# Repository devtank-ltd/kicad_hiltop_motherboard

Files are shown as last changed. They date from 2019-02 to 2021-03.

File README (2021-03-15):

Copyright Devtank Ltd 2021.

This documentation describes Open Hardware and is Licensed under CERN-OHL-W v2.

You may redistribute and modify this documentation under the terms of the CERN-OHL-W v2 (https://cern.ch/cern-ohl). This documentation is distributed WITHOUT ANY EXPRESS OR IMPLIED WARRANTY, INCLUDING OF MERCHANTABILITY, SATISFACTORY QUALITY AND FITNESS FOR A PARTICULAR PURPOSE. Please see the CERN-OHL-W v2 for applicable conditions

Source location: git@github.com:devtank-ltd/hiltop_motherboard.git 

As per CERN-OHL-W v2 section 4.1, should You produce hardware based on these sources, You must maintain the   Source Location visible on the external case of the HILTOP or other product you make using this documentation.

This folder contains HILTOP Motherboard hardware schematics, PCB layout and BOM files. 

You will need Kicad to open hardware design files.

HILTOP Motherboards and other test and measurement products can be purchased directly from Devtank Ltd.

Please contact:
Tim Telford
CTO - Devtank Ltd
+44 (0)1332 650944

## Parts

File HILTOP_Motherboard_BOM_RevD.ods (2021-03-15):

Title | HILTOP Motherboard
Revision | Rev D
Date | 2021-17-02
Generated
Company | Devtank Ltd
Comment 1
Comment 2
Comment 3
Comment 4
Total Parts | 793
Total Unique Parts | 157
Ref | Qty | Value | Footprint | Devtank | Description | Manufacturer | Manufacturer Part Number | Supplier | Supplier Part number
BT1 | 1 | Battery_Cell | Devtank_PCB_Lib:BatteryHolder_Keystone_1061_1x20mm | 750-001 | Keystone 1061_1x20mm Battery Holder, PCB Mount | Keystone | 1061 | Farnell | 1282702
C8 C22 C26 C25 C24 C12 C14 C17 C121 C5 C19 C15 C20 C50 C75 C77 C55 C243 C23 C123 C124 C125 C126 C127 C128 C152 C85 C86 C87 C88 C89 C90 C91 C92 C93 C94 C95 C236 C106 C109 C96 C97 C49 C66 C57 C60 C64 C118 C117 C180 C194 C187 C191 C192 C188 C189 C193 C190 C184 C185 C155 C98 C156 C99 C157 C160 C129 C122 C215 C223 C216 C218 C205 C207 C209 C211 C212 C213 C203 C201 C208 C210 C219 C225 C82 C80 C81 C83 C234 C226 C232 C230 C235 C228 C233 C231 C110 C143 C146 C149 C140 C137 C135 C144 C147 C150 C141 C138 C136 C142 C145 C148 C139 C173 C169 C244 | 116 | 100nF | Capacitor_SMD:C_0603_1608Metric | 105-002 | 100nF 50V X7R | Kemet | C0603C104M5RACTU | Farnell | 2581046
C27 C107 C114 C116 C113 C68 C100 C153 C217 C224 C76 C45 | 12 | 4.7uF | Capacitor_SMD:C_0805_2012Metric | 105-007 | 4.7uF 16V X7R | muRata | GCJ21BR71C475KA01L | Farnell | 2781412
C4 C10 C119 C6 | 4 | 10uF | Capacitor_SMD:CP_Elec_6.3x5.3 | 108-002 | 10uF 50V KZ, V-Chip Series | Multicomp | MCVKZ050M100EA1L | Farnell | 2611344
C9 C11 C16 C120 | 4 | 4.7uF | Capacitor_SMD:CP_Elec_5x5.3 | 108-001 | 4.7uF 50V KZ, V-Chip Series | Multicomp | MCVKZ050M4R7DA1L | Farnell | 2611348
C51 C32 C35 C28 C39 C34 C31 C36 C38 C40 C41 C52 | 12 | 100nF | Capacitor_SMD:C_0402_1005Metric | 105-019 | 100nF 50V X7R | TDK | C1005X7R1H104M050BB | Farnell | 2525048
C3 C18 C7 C13 C2 C241 C242 C67 C186 C70 C79 | 11 | 100uF | Capacitor_SMD:CP_Elec_6.3x7.7 | 108-003 | 100uF 50V 0.34R FT Series | Panasonic | EEEFTH101XAP | Farnell | 1868426
C74 C63 C115 C111 C171 | 5 | 1uF | Capacitor_SMD:C_0805_2012Metric | 105-004 | 1uF 16V X7R | Walsin | 0805B105K160CT | Farnell | 2496946
C30 C33 C151 C132 | 4 | 18pF | Capacitor_SMD:C_0402_1005Metric | 106-010 | 18pF COG/NPO | AVX | 04025A180JAT2A | Farnell | 1740572
C21 C29 C37 C42 C175 C195 C227 C229 | 8 | 1uF | Capacitor_SMD:C_0603_1608Metric | 105-014 | 1uF 16V X7R | Walsin | 0603B105K160CT | Farnell | 2496835
C131 C177 | 2 | 10nF | Capacitor_SMD:C_0603_1608Metric | 105-006 | 10nF 50V X7R | Kemet | C0603C103K5RACTU | Farnell | 1414609
C130 C61 C62 C112 C237 C238 C167 C176 | 8 | DNF | Capacitor_SMD:C_0603_1608Metric
C48 C47 | 2 | 12pF | Capacitor_SMD:C_0603_1608Metric | 106-009 | 12pF 50V COG/NPO | AVX | 06035A120JAT2A | Farnell | 1462447
C221 C222 C196 C133 C134 C174 C168 | 7 | 22uF | Capacitor_SMD:C_1206_3216Metric | 105-003 | 22uF 10V X7R | Kemet | C1206C226M8RACTU | Farnell | 2118135
C178 C84 C102 C78 C44 | 5 | 2.2uF | Capacitor_SMD:C_0805_2012Metric | 105-005 | 2.2uF 16V X7R | Kemet | C0805C225K4RACAUTO | Farnell | 2070473
C170 C172 | 2 | 10uF | Capacitor_SMD:C_0805_2012Metric | 105-001 | 10uF 16V X5R 10% MLCC | AVX | 0805YD106KAT2A | Farnell | 1658880
C56 C58 C179 | 3 | 2.2uF | Capacitor_SMD:C_1206_3216Metric | 105-011 | 2.2uF 25V X7R | Yageo | CC1206KKX7R8BB225 | Farnell | 1458911
C54 | 1 | 330pF | Capacitor_SMD:C_0201_0603Metric | 106-001 | 330pF 100V COG/NPO | Kemet | C0603C331J5GACTU | Farnell | 1414634
C65 C181 C182 C183 | 4 | 4.7uF | Capacitor_SMD:C_1210_3225Metric | 105-008 | 4.7uF 50V X7R | AVX | 12105C475KAT2A | Farnell | 1658891
C69 | 1 | 470nF | Capacitor_SMD:C_0805_2012Metric | 105-009 | 470nF 100V X7R | AVX | 08051C474K4Z2A | Farnell | 1867963
C53 C162 C159 C164 C166 C161 C158 C163 C165 C72 C202 C220 C240 C71 C73 C214 C239 | 17 | 47pF | Capacitor_SMD:C_0603_1608Metric | 106-011 | 47pF COG/NPO | AVX | 06035A470JAT2A | Farnell | 498567
C103 C105 C104 C108 C206 C204 | 6 | 9pF | Capacitor_SMD:C_0603_1608Metric | 106-008 | 9pF 50V COG/NPO | TDK | C1608C0G1H090C080AA | Farnell | 2526242
C101 C154 C43 C46 | 4 | 470pF | Capacitor_SMD:C_0603_1608Metric | 106-007 | 470pF 50V COG/NPO | AVX | 06035A471JAT2A | Farnell | 316672
C197 C198 C199 C200 | 4 | 10nF | Capacitor_SMD:C_0402_1005Metric | 105-017 | 10nF 50V X7R | AVX | 04025C103KAT2A | Farnell | 2332514
C59 | 1 | DNF | Capacitor_SMD:C_0402_1005Metric | 105-019
D1 D11 D13 D15 D17 D26 D28 D30 D23 D22 D21 D18 D85 D86 D87 D88 D89 D90 D91 D92 D32 D33 | 22 | GRN | LED_SMD:LED_0402_1005Metric | 110-005 | LED GREEN CLEAR 1006 SMD | Rohm Semiconductor | SML-P13PTT86R | Digikey | 846-1197-1-ND
D34 D35 D93 D94 D95 D38 D39 D40 D41 D42 D43 D44 D45 D47 D48 D49 D46 D50 D51 D55 D56 D57 D54 D58 D59 D60 D61 D63 D64 D65 D62 D76 D68 D74 D75 D8 D10 D7 D9 | 39 | BAV99 | Package_TO_SOT_SMD:SOT-23 | 134-001 | BAV99 - Small Signal Diode, Dual Series, 75 V, 300 mA, 1.25 V, 4 ns, 4.5 | Diodes Inc | BAV99 | Farnell | 1902422
D12 D14 D16 D25 D27 D29 D31 | 7 | YEL | LED_SMD:LED_0402_1005Metric | 110-007 | LED GREEN-YELLOW CLEAR 1006 SMD | Rohm Semiconductor | SML-P11MTT86R | Digikey | 846-1211-1-ND
D2 D4 D3 | 3 | RED | LED_SMD:LED_0402_1005Metric | 110-004 | LED RED CLEAR 0402 SMD | Rohm Semiconductor | SML-P12VTT86R | Digikey | 846-1168-6-ND
D66 | 1 | MBR230LSFT | Diode_SMD:D_SOD-123F | 133-006 | Schottky Rectifier, 30 V, 2 A, Single, SOD-123FL | ON Semi | MBR230LSFT1G | Farnell | 2317422
D24 D20 | 2 | STPS1L30 | Diodes_SMD:D_SMB | 133-001 | STPS1L30 Low Drop Power Schottky Diode (300mV max) | ST Microelectronics | STPS1L30 | Farnell | 1467550
D6 | 1 | MBRD1035 | Devtank_PCB_Lib:DPAK | 133-003 | MBRD1035CTL Schottky Power Rectifier | On Semi | MBRD1035CTL | Farnell | 9556974
D5 | 1 | VB40100C | Devtank_PCB_Lib:TO-263AB | 133-002 | Dual High Voltage Trench MOS barrier Schottky Rectifier | Vishay | VB40100C-E3/4W | Farnell | 2335186
D19 | 1 | LM4040 | Package_TO_SOT_SMD:SOT-23 | 138-001 | LM4040CYM3-2.5V Reference | Microchip | LM4040CYM3-2.5 | Farnell | 2509863
D37 D36 | 2 | NUP2105L | Package_TO_SOT_SMD:SOT-23 | 136-002 | TVS DIODE – CAN BUS | ON Semi | NUP2105LT1G | Digikey | NUP2105LT1GOSCT-ND
D67 D53 | 2 | SM6T15A | Diode_SMD:D_SMB | 136-004 | Transil SM6T Series, Unidirectional, 12.8 V, 27.2 V | ST Microelectronics | SM6T15A | Farnell | 9885900
D69 | 1 | SM6T6V8A | Diode_SMD:D_SMB | 136-005 | Transil SM6T Series, Unidirectional, 5.8 V, 13.4 V, DO-214AA | ST Microelectronics | SM6T6V8A | Farnell | 9802720
D52 | 1 | SMLVT3V3 | Diode_SMD:D_SMB | 136-006 | Transil SMLV Series, Unidirectional, 3.3 V, 10.3 V, DO-214AA | ST Microelectronics | SMLVT3V3 | Farnell | 9802886
EXP1 EXP2 | 2 | CONN_02X20 | Connector_IDC:IDC-Header_2x20_P2.54mm_Vertical | 710-007 | 40 Way 2.54mm Box Header | Amphenol | T821140A1S100CEU | Farnell | 2215314
F1 | 1 | PPTC 3.8A | Fuse:Fuse_Bourns_MF-RHT200 | 190-001 | PPTC Resettable Fuse, Through Hole, MF-RHT Series, 2 A, 3.8 A, 32 V, -40 °C | Bourns Inc | MF-RHT200/32-2 | Farnell | 2810350
F3 F2 | 2 | Polyfuse | Fuse:Fuse_1206_3216Metric | 190-002 | PPTC Resettable Fuse, SMD, POLYFUSE 1206L | Littlefuse | 1206L050/15YR | Farnell | 2752736
FB1 FB2 FB3 FB4 FB5 FB8 FB7 FB9 FB11 FB6 FB10 | 11 | 120R_100MHz | Resistor_SMD:R_0603_1608Metric | 113-001 | 120Ohm, 100MHz Ferrite Bead | muRata | BLM18AG121SN1D | Farnell | 1515672
FL2 FL1 | 2 | PE-1812ACC510STS | Devtank_PCB_Lib:Inductor_PE-1812ACCXXXSTS | 114-001 | CMC 230MA 2LN 3.5 KOHM AEC-Q200 | Pulse Electronics | PE-1812ACC510STS | Digikey | 553-2565-1-ND
J10 | 1 | HDMI | Devtank_PCB_Lib:FCI_10029449-11RLF | 702-001 | HDMI Connector – PCB Mount | Amphenol | 47151-1051 | Digikey | 609-4614-1-ND
J11 | 1 | DISP_PWR | Connector_Molex:Molex_KK-254_AE-6410-05A_1x05_P2.54mm_Vertical | 710-016 | 5 Way Header KK Series | Molex | 22-27-2051 | Farnell | 9731679
J19 | 1 | Micro_SD_Card | Devtank_PCB_Lib:uSD_MSDC-PP03 | 705-002 | uSD Valcon Push-push type MSDC-PP-03 | Valcon | MSDC-PP-03 | Toby | MSDC-PP-03
J12 | 1 | DISPLAY_PORT | Devtank_PCB_Lib:DSI_FCC15W_VERT | 702-003 | Vertical 15Way FFC Connector, 1mm | Valcon | FFC1-15-V-TR | Toby | FFC115VTR
J17 | 1 | PWR_LED | Pin_Headers:Pin_Header_Straight_1x02_Pitch2.54mm | 710-003 | 2 Way 2.54mm Header (shroudless) | Valcon | THS-02-R | Toby | THS-02-R
J16 | 1 | SOFT_START_PWR | Pin_Headers:Pin_Header_Straight_1x02_Pitch2.54mm | 710-003 | 2 Way 2.54mm Header (shroudless) | Valcon | THS-02-R | Toby | THS-02-R
J2 | 1 | ATX_MOLEX_02X12 | Connectors_Molex:Molex_MiniFit-JR-5556-24A_2x12x4.20mm_Straight | 709-001 | 24 Way Molex ATX Connector | Valcon | 5900-W24ST | Toby | 5900-W24ST
J14 | 1 | VADJ_B | Connectors_Molex:Molex_MiniFit-JR-5556-02A_2x01x4.20mm_Straight | 709-002 | 2 Way Molex ATX Connector | Valcon | 5900-W02ST | Toby | 5900-W02ST
J15 | 1 | VADJ_A | Connectors_Molex:Molex_MiniFit-JR-5556-02A_2x01x4.20mm_Straight | 709-002 | 2 Way Molex ATX Connector | Valcon | 5900-W02ST | Toby | 5900-W02ST
J4 | 1 | USB_A_DOUBLE | Devtank_PCB_Lib:USB_A_Double_Lumberg_2410_03 | 703-004 | USB Type A – PCB Mount Dual | Lumberg | 2410 03 | Toby | 2410-03
J9 | 1 | RJ45-TRANS_SI-61001-F | Devtank_PCB_Lib:RJ45_TRANSFO_STEWART | 704-002 | RJ45 Ethernet with Magnetics + LEDs 10/100/1000 | Stewart | SI-61001-F | Farnell | 1572191
J3 | 1 | SATA | Connector:SATA-7_THT_VERT_1 | 716-001 | SATA- 7 Pin Vertical Header | Molex | 47155-4001 | Farnell | 1519801
J21 J23 | 2 | EXT_FAN | Connector_Molex:Molex_KK-254_AE-6410-04A_1x04_P2.54mm_Vertical | 710-013 | 4 Way Header KK Series | Molex | 47053-1000 | Farnell | 2313705
J5 | 1 | USB FRONT PANEL | Connector_Molex:Molex_Picoflex_90325-0008_2x04_P1.27mm_Vertical | 714-001 | 8 Way Picoflex 90325 Series | Molex | 90325-0008 | Farnell | 673237
J7 | 1 | RS485 | Connector_Molex:Molex_Picoflex_90325-0016_2x08_P1.27mm_Vertical | 714-004 | 16 Way Picoflex 90325 Series | Molex | 90325-0016 | Farnell | 673262
J6 | 1 | CAN | Connector_Molex:Molex_Picoflex_90325-0010_2x05_P1.27mm_Vertical | 714-002 | 10 Way Picoflex 90325 Series | Molex | 90325-0010 | Farnell | 673249
J8 | 1 | EXT_TEMP_MON | Connector_Molex:Molex_KK-254_AE-6410-03A_1x03_P2.54mm_Vertical | 710-014 | 3 Way Header KK Series | Molex | 22-27-2031 | Farnell | 9731156
J20 | 1 | CAMERA_PORT | Devtank_PCB_Lib:DSI_FCC15W_VERT | 702-003 | Vertical 15Way FFC Connector, 1mm | Valcon | FFC1-15-V-TR | Toby | FFC115VTR
J1 | 1 | BACKPLANE_PWR | Connector_Molex:Molex_Mini-Fit_Jr_5566-08A_2x04_P4.20mm_Vertical | 709-005 | 8 Way Molex ATX Connector | Valcon | 5900-W08ST | Toby | 5900-W08ST
J22 | 1 | BACKPLANE_LV_PWR | Connector_Molex:Molex_Mini-Fit_Jr_5566-04A_2x02_P4.20mm_Vertical | 709-006 | 4 Way Molex ATX Connector | Valcon | 5900-W04ST | Toby | 5900-W04ST
J18 | 1 | USB_B | Connector_USB:USB_B_Horizontal | 703-002 | USB Type B – PCB Mount | Lumberg | 2411 02 | Toby | 2411-02
J26 | 1 | IO_EXP | Connector_IDC:IDC-Header_2x06_P2.54mm_Vertical | 710-002 | 12 Way 2.54mm Box Header | Amphenol | T821112A1S100CEU | Farnell | 2215306
J27 | 1 | USB_A | Devtank_PCB_Lib:USB_A_Vertical_Lumberg_2410_01 | 703-003
J13 | 1 | DDR2_SODIMM_COMPUTE_MODULE_3 | Devtank_PCB_Lib:Conn_TE-DDR2-SODIMM-0.6-200P-ComputeModule | 712-001 | DDR 2 SODIMM – Compute Module | Amp-TE | 1565917-4 | Farnell | 2112525
J25 | 1 | DEBUG | Connector_PinHeader_2.54mm:PinHeader_1x03_P2.54mm_Vertical | 710-015 | 3 Way Header (shroudless) | Valcon | THS-03-R | Toby | THS-03-R
J24 | 1 | HILTOP_PCIE-64_CONN | Devtank_PCB_Lib:PCIE-064-02-X-D-TH | 716-002 | Amphenol FCI 64 Way PCI-E connector | Amphenol FCI | 10018783-11111TLF | RS | 615-9524
L1 L2 L3 L8 | 4 | 22uH | Devtank_PCB_Lib:Inductor_8x8 | 112-001 | VLP8040T-220M, 22uH, 2.5A shielded | TDK | VLP8040T-220M | Farnell | 2345218
L12 | 1 | 120R | 6A | Resistor_SMD:R_1206_3216Metric
L9 | 1 | 3.3uH | Devtank_PCB_Lib:Inductor_8x8 | 112-003 | VLP8040T-3R3N, 3.3uH, 5.2A shielded | TDK | VLP8040T-3R3N | Mouser | 810-VLP8040T-3R3N
L10 | 1 | 2.2uH | Devtank_PCB_Lib:Inductor_8x8 | 112-002 | VLP8040T-2R2N, 2.2uH, 6.7A shielded | TDK | VLP8040T-2R2N | Farnell | 2345220
L4 | 1 | 10uH | Devtank_PCB_Lib:Inductor_Coilcraft_SER2800 | 112-005 | Coilcraft SER2814H-103 10uH – Extremely low DCR, High Current (>100A) | Coilcraft | SER2814H-103 | Coilcraft | SER2814H-103
L7 L11 L5 L6 | 4 | 10uH | Devtank_PCB_Lib:Inductor_MuRata_82103C | 112-004 | 82103C – 10uH, 500mA, 400mOhm, 10% | muRata | 82103C | Mouser | 580-82103C
Q3 Q4 | 2 | 2N7002 | Package_TO_SOT_SMD:SOT-23 | 170-001 | 2N7002 N Channel 300mA, 60V, 2.8Ohm | Nexperia | 2N7002 | Farnell | 1510761
Q1 Q2 | 2 | Si7148DP-T1-E3 | Devtank_PCB_Lib:PowerPAK_SO-8 | 172-001 | Si7148 N Channel 75V 28A 5.4W | Vishay | Si7148DP-T1-E3 | Digikey | SI7148DP-T1-E3CT-ND
Q5 Q6 Q7 | 3 | ZXMN6A07F | Package_TO_SOT_SMD:SOT-23 | 170-002 | ZXMN6A07F N Channel 1A, 60V, 0.4Ohm | Diodes Inc | ZXMN6A07FTA | Farnell | 9525769
Q8 | 1 | SSM3J328R | Package_TO_SOT_SMD:SOT-23 | 173-003 | SSM3J328R P-CH 20V 6A SOT23F | Toshiba | SSM3J328R | Digikey | SSM3J328RLFCT-ND
R12 R119 R121 R23 R25 R136 R167 R61 R65 R116 R113 R132 R105 R199 R200 R228 R233 R217 R218 R159 R184 R185 R81 R244 R221 R222 R110 R256 R202 | 29 | 10K | Resistor_SMD:R_0603_1608Metric | 101-010 | Use 1% part, voltage rating 50V or above
R17 R3 R10 R19 R18 R11 R148 R152 R126 R104 R103 R77 R79 R91 R174 R66 R67 R68 R142 R232 R94 R203 R208 R209 R223 R188 R192 R193 R194 R195 R196 R197 R198 R109 R162 | 35 | 0R | Resistor_SMD:R_0603_1608Metric | 101-005
R14 R16 R4 R22 R2 R24 R130 R73 R60 R118 R123 R143 R176 R175 R229 R177 R219 R220 R243 R186 R201 | 21 | DNF | Resistor_SMD:R_0603_1608Metric
R1 R6 R98 | 3 | 1K | Resistor_SMD:R_0603_1608Metric | 101-012
R5 R7 R56 | 3 | DNF | Resistor_SMD:R_1206_3216Metric
R120 R93 R131 R70 R71 R231 R230 R224 R226 R111 R106 | 11 | 4K7 | Resistor_SMD:R_0603_1608Metric | 101-009
R122 | 1 | 1K5 | Resistor_SMD:R_0603_1608Metric | 101-032
R124 R74 | 2 | 47K | Resistor_SMD:R_0603_1608Metric | 101-016
R125 | 1 | 20K | Resistor_SMD:R_0603_1608Metric | 101-017
R85 R83 R129 R128 R127 R76 R166 R133 R165 R204 R205 | 11 | 330R | Resistor_SMD:R_0603_1608Metric | 101-024
R149 | 1 | DNF | Resistor_SMD:R_1210_3225Metric
R8 | 1 | 360R | Resistor_SMD:R_1206_3216Metric
R9 | 1 | 120R | Resistor_SMD:R_0603_1608Metric | 101-047
R54 R245 R246 R247 R248 R28 R80 R82 R84 R86 R87 R88 R89 R90 R95 R96 R97 R140 R141 R153 R154 R155 R156 R157 R158 R182 R183 R189 R190 R191 R92 | 31 | 220R | Resistor_SMD:R_0402_1005Metric | 101-503
R20 | 1 | 100K | Resistor_SMD:R_0603_1608Metric | 101-015
R27 R134 | 2 | 12K | Resistor_SMD:R_0603_1608Metric | 101-044
R21 | 1 | 1M | Resistor_SMD:R_0603_1608Metric | 101-019
R34 R49 R50 R72 R53 | 5 | 10K | Resistor_SMD:R_0402_1005Metric | 101-501
R213 R206 R210 R214 R52 R51 R78 R173 R171 R169 | 10 | DNF | Resistor_SMD:R_0402_1005Metric
R35 R36 R37 R38 R39 R40 R41 R42 R43 R44 R45 R46 R47 R48 R31 R33 R32 R235 R236 R237 R238 R239 R240 R241 R242 | 25 | 330R | Resistor_SMD:R_0402_1005Metric | 101-504
R55 | 1 | 8.06K | Resistor_SMD:R_0603_1608Metric | 101-030
R135 R137 R138 R139 R144 R145 R146 R147 R64 | 9 | 51R | Resistor_SMD:R_0603_1608Metric | 101-028
R100 R101 R99 R102 | 4 | 100K | Resistor_SMD:R_0402_1005Metric | 101-502
R13 R15 R29 R26 R107 | 5 | 2K2 | Resistor_SMD:R_0603_1608Metric | 101-011
R178 R179 R180 R181 | 4 | 100R | Resistor_SMD:R_0402_1005Metric | 101-500
R108 R114 R215 R216 | 4 | 470R | Resistor_SMD:R_0603_1608Metric | 101-001
R160 | 1 | 30.1K | Resistor_SMD:R_0603_1608Metric | 101-003
R161 R164 | 2 | 22.1K | Resistor_SMD:R_0603_1608Metric | 101-002
R163 | 1 | 12.7K | Resistor_SMD:R_0603_1608Metric | 101-004
R63 | 1 | 0R | Resistor_SMD:R_1206_3216Metric | 101-007
R59 | 1 | 18K | Resistor_SMD:R_0603_1608Metric | 101-020
R58 | 1 | 30K | Resistor_SMD:R_0603_1608Metric | 101-021
R57 | 1 | 75K | Resistor_SMD:R_0603_1608Metric | 101-022
R69 | 1 | 0.015 | Devtank_PCB_Lib:RL7520W_3008 | 103-001 | 0.015R Precision Current Shunt Resisitor 2W 1% | Susumu | RL7520WT-R015-F | Digikey | RL75WT.015FCT-ND
R75 | 1 | 3K3 | Resistor_SMD:R_0603_1608Metric | 101-013
R112 | 1 | 3.16K | Resistor_SMD:R_0603_1608Metric | 101-027
R117 | 1 | 47R | Resistor_SMD:R_0603_1608Metric | 101-025
R115 | 1 | 2K | Resistor_SMD:R_0603_1608Metric | 101-026
R62 | 1 | 820R | Resistor_SMD:R_0603_1608Metric | 101-029
R234 | 1 | 90.9K | Resistor_SMD:R_0603_1608Metric | 101-010
R225 R227 R251 | 3 | DNF | Resistor_SMD:R_0603_1608Metric | 101-009
R211 R207 R212 R250 R168 R170 R172 | 7 | 0R | Resistor_SMD:R_0402_1005Metric | 101-506
R187 | 1 | 0R | Resistor_SMD:R_0805_2012Metric
RL1 | 1 | SPST-NO | Devtank_PCB_Lib:Relay_SPST_TE_PCH | 140-001 | 12V Coil – General Purpose Relay SPST-NO, 5A, 30V | TE-Connectivity | PCH-112L2MH | Farnell | 9659331
TP8 TP9 TP10 TP12 TP14 TP13 TP11 TP51 TP52 TP53 TP54 TP92 TP93 TP67 TP68 TP69 TP70 TP71 TP72 TP73 TP74 TP75 TP76 TP77 TP78 TP79 TP80 TP81 TP82 TP83 TP84 TP85 TP86 TP87 TP88 TP89 TP90 TP91 TP55 TP56 TP57 TP58 TP59 TP60 TP61 TP62 TP63 TP64 TP65 TP66 TP33 TP34 TP38 TP39 TP43 TP44 TP45 TP46 TP47 TP48 TP49 TP50 TP17 TP18 TP19 TP94 TP20 TP21 TP22 TP23 TP24 TP25 TP26 TP27 TP28 TP29 TP30 TP31 TP32 TP15 TP16 TP41 TP42 TP40 TP37 TP36 TP35 TP2 TP1 TP3 TP4 TP6 TP5 TP7 TP95 | 95 | TP | TestPoint:TestPoint_THTPad_D1.0mm_Drill0.5mm
U25 | 1 | STM6719SFWB6F | Package_TO_SOT_SMD:TSOT-23-6 | 128-001 | STM6719SFWB6F Triple POR 140ms Active Low | ST Microelectronics | STM6719SFWB6F | Mouser | 511-M6719SFWB6F
U1 | 1 | LM337BD2TG | Package_TO_SOT_SMD:TO-263-2 | 150-003 | LM337D2TG Linear Negative Regulator Adjustable -37 to -1.2v | ON Semi | LM337D2TG | Farnell | 9665005
U39 | 1 | MCP23017 | Package_SO:SSOP-28_5.3x10.2mm_P0.65mm | 123-007 | MCP23017 | Microchip | MCP23017 | Farnell | 2851558RL
U42 | 1 | 24LC512 | Package_SO:SOIC-8_3.9x4.9mm_P1.27mm | 129-005 | 24LC512 | Microchip | 24LC512 | Farnell | 9758038
U48 | 1 | 74LVC1G3157 | Package_SO:TSOP-6_1.65x3.05mm_P0.95mm |  | Multiplexer/Demultiplexer | Nexperia | 74LVC1G3157GV,125 | Farnell | 2463921
U3 | 1 | USB2517 | Devtank_PCB_Lib:QFN-64-1EP_9x9mm_P0.5mm_EP4.7x4.7mm | 118-004 | USB2517 USB Hub controller – 7 Ports | Microchip | USB2517-JZX | Farnell | 2292607
U2 U4 | 2 | MIC2026-1YM | Package_SOIC:SOIC-8_3.9x4.9mm_P1.27mm | 153-003 | MIC2026-1YM USB Power distribution Switch Current Limit, high side switch – 2 outputs | Microchip | MIC2026-1YM | Farnell | 2509898
U5 U6 U14 U47 U40 | 5 | SP3003-02XJ | Devtank_PCB_Lib:SC70-5 | 153-004 | SP3003-02JTG-ESD Protection Device | Littlefuse | SP3003-02JTG | Farnell | 1827640
U7 | 1 | LAN7500 | Devtank_PCB_Lib:QFN-56_8x8mm_Pitch0.5mm | 123-003 | LAN7500 10/100/1000 USB Ethernet Controller | Microchip | LAN7500 | RS | 803-2339
U45 | 1 | 93AAxxA | Package_SO:SOIC-8_3.9x4.9mm_P1.27mm | 129-003 | EEPROM, 512K x8 | Microchip | 93AA66A-I/SN | Mouser | 579-93AA66A-I/SN
U23 | 1 | TPD12S016 | Package_SSOP:TSSOP-24_4.4x7.8mm_P0.65mm | 123-001 | TPD12S016 HDMI Companion chip | Texas Instruments | TPD12S016 | RS | 812-4270
U22 | 1 | BQ32000 | Package_SO:SOIC-8_3.9x4.9mm_P1.27mm | 123-008 | BQ32000DR – RTC, I2C, 3V to 3.6V | Texas Instruments | BQ32000DR | Farnell | 1754773
U26 | 1 | LM75B | Package_SO:SOIC-8_3.9x4.9mm_P1.27mm | 155-005 | LM75BD Temperature Sensor -55degC to +125degC | NXP | LM75BD | Farnell | 1854077
U24 | 1 | MAX16054 | Package_TO_SOT_SMD:TSOT-23-6 | 123-002 | MAX16054 Push Button On/Off Debouncer | Maxim | MAX16054 | Farnell | 2515822
U28 | 1 | LP2985 | Package_TO_SOT_SMD:SOT-23-5 | 150-001 | LP2985 Fixed 2.5V LDO, 280mV dropout, 150mA | Texas Instruments | LP2985-25DBVR | Farnell | 2492273
U27 | 1 | TPS54394 | Devtank_PCB_Lib:HTSSOP-16_4.4x5mm_Pitch0.65mm | 151-002 | TPS54394 3A Dual Synchronous Step-Down Switcher with Integrated FETs | Texas Instruments | TPS54394 | Farnell | 2211340
U8 | 1 | LM5118 | Package_SSOP:HTSSOP-20-1EP_4.4x6.5mm_P0.65mm_ThermalPad | 151-001 | LM5118 DC/DC Buck Boost Controller 3 to 75V input | Texas Instruments | LM5118MH | Farnell | 1609187
U11 | 1 | ADS1015 | Package_SSOP:TSSOP-10_3x3mm_P0.5mm | 124-001 | ADS1015 12 bit ADC, 4 Channel, 3.3kSPS, I2C | Texas Instruments | ADS1015IDGST | Farnell | 1778211
U12 | 1 | MCP4725 | Package_TO_SOT_SMD:SOT-23-6 | 125-001 | MCP4725 12bit DAC, single channel, I2C | Microchip | MCP4725A0T-E/CH | Farnell | 1578449
U10 | 1 | TLC271 | Package_SOIC:SOIC-8_3.9x4.9mm_P1.27mm | 120-001 | TLC271 Single 1.7MHz 3.6V/uS, 3V to 16V | Texas Instruments | TLC271ACDG4 | Farnell | 1234674
U9 | 1 | INA250A3 | Package_SSOP:TSSOP-16_4.4x5mm_P0.65mm | 119-001 | INA250 Current Shunt Monitor 800mV/A (A3) | Texas Instruments | INA250A3PWR | Digikey | 296-43803-1-ND
U36 U35 | 2 | MCP2561FD | Package_SOIC:SOIC-8_3.9x4.9mm_P1.27mm | 118-005 | MCP2561FD CAN FD Transceiver – 4.5 to 5.5V | Texas Instruments | MCP2561FD-E/SN | Farnell | 2434896
U34 U33 | 2 | ADuM1201 | Package_SOIC:SOIC-8_3.9x4.9mm_P1.27mm | 117-002 | ADUM1201 Digital Isolator Dual 2 Channel, 150ns | Analog Devices | ADUM1201ARZ | Digikey | ADUM1201ARZ-RL7CT-ND
U31 U30 | 2 | MCP2517FD | Package_SOIC:SOIC-14_3.9x8.7mm_P1.27mm | 118-006 | MCP2517FD CAN FD Controller | Texas Instruments | MCP2517FD-H/SL | Farnell | 2806158
U29 U32 U13 U17 | 4 | CME0505S3C | Devtank_PCB_Lib:CME_XXXX_S3C_PSU_MODULE | 131-003 | CME0505S3C Isolated Fixed output 5V, 750mW | MuRata | CME0505S3C | Farnell | 2400812
U37 | 1 | TUSB9261 | Devtank_PCB_Lib:PQFP-64_7x7mm_P0.4mm_EP | 118-003 | TUSB9261 USB3.0 to SATA Bridge IC | Texas Instruments | TUSB9261PVP | Farnell | 2335695
U38 | 1 | AT25DN512CSSHF-B | Package_SO:SOIC-8_3.9x4.9mm_P1.27mm | 129-002 | 512K, 2.3V, 104MHz Serial Flash | Adesto | AT25DN512C-SSHF-B (https://www.mouser.co.uk/ProductDetail/Adesto-Technologies/AT25DN512C-SSHF-B) | Mouser | 988-AT25DN512CSSHF-B
U41 | 1 | CP2102N-A01-GQFN24 | Package_DFN_QFN:QFN-24-1EP_4x4mm_P0.5mm_EP2.6x2.6mm_ThermalVias | 118-007 | CP2102N USB to UART adapter IC | Silicon Labs | CP2102N-A01-GQFN24 | Farnell | 2577278
U15 U16 | 2 | ISO3080 | Package_SOIC:SOIC-16W_7.5x10.3mm_P1.27mm | 118-008 | ISO3080DW Line Transceiver | Texas Instruments | ISO3080DW | RS | 121-9062
U18 U19 U20 U21 | 4 | USB6B1 | Package_SOIC:SOIC-8_3.9x4.9mm_P1.27mm | 153-005 | USB6B1 ESD Protection Device | ST Microelectronics | USB6B1RL | Farnell | 2341651
U43 U44 | 2 | MAX3107 | Package_SO:SSOP-24_5.3x8.2mm_P0.65mm | 118-009 | MAX3107 UART Interface (SPI/I2C) 1 Channel, 24Mbps | Maxim | MAX3107EAG+ | Farnell | 2517399
Y1 | 1 | 24Mhz Xtal | Crystal:Crystal_SMD_Abracon_ABM8G-4Pin_3.2x2.5mm | 181-012 | 24MHz Crystal 10ppm | AEL Crystals | X24M000000S050 | Farnell | 3255020RL
Y2 | 1 | 25MHz Crystal | Crystal:Crystal_SMD_SeikoEpson_FA238V-4Pin_3.2x2.5mm | 181-001 | 25MHz Crystal 30ppm | Abracon | ABM8G-25.000MHZ-18-D2Y-T | Farnell | 2101339
Y4 | 1 | 32.768kHz | Crystal:Crystal_SMD_EuroQuartz_EQ161-2Pin_3.2x1.5mm |  | 32.768kHz Crystal | ECS | ECS-.327-6-34QN-TR | Mouser | 520-.327-6-34QNT
Y5 Y6 Y7 | 3 | 40MHz Crystal | Crystal:Crystal_SMD_SeikoEpson_FA238V-4Pin_3.2x2.5mm | 181-004 | 40MHz Crystal 10ppm | Epson | X1E0000210177 TSX-3225 | Farnell | 1712847
Y8 Y9 | 2 | 3.6864MHz Crystal | Crystal:Crystal_SMD_SeikoEpson_MA505-2Pin_12.7x5.1mm | 181-006 | 3.6864 Mhz Crystal 30ppm | TXC | 9C-3.6864MAAJ-T | Farnell | 1842323RL
Green | Can use equivalent/better
Black | Do not replace/substitute
DNP/DNF | do not populate / do not fit

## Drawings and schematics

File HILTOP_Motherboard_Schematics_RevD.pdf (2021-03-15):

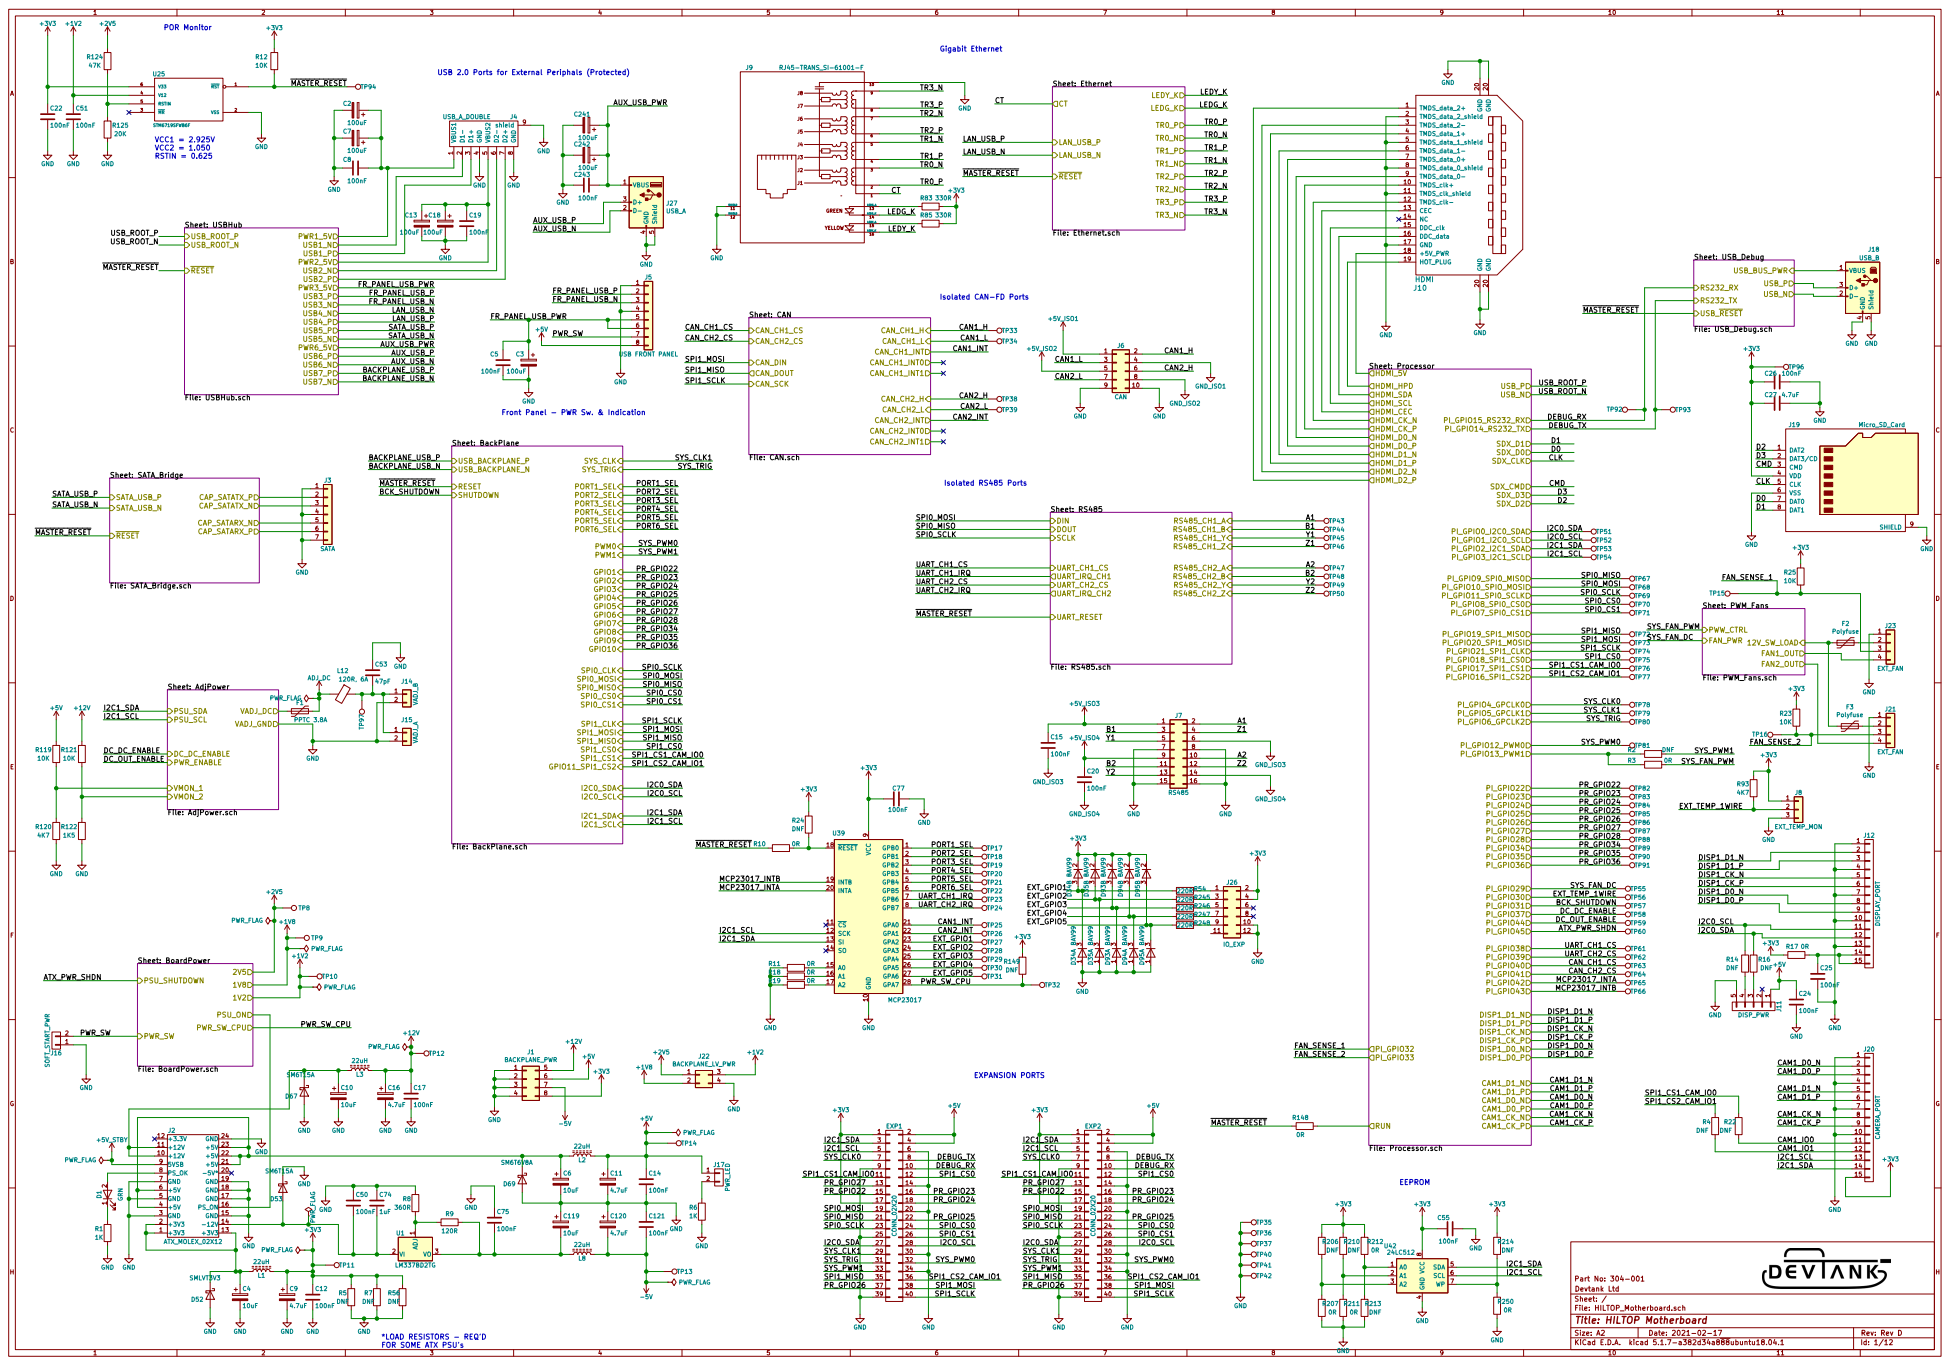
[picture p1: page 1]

USB 2.0 Ports for External Periphals (Protected) POR Monitor

Gigabit Ethernet
Sheet: Ethernet File: Ethernet.sch

Isolated CAN-FD Ports

Sheet: BackPlane File: BackPlane.sch

Front Panel - PWR Sw. & Indication

-5V* 20 +5V 21 +5V 22 +5V 23 GND 24 GND 3 +5V 4 GND 5 +5V 6 GND 7 PS_OK 8

-12V 14 GND 15 PS_ON 16 GND 17 GND 18 GND 19 +3V3 2

File: HILTOP_Motherboard.sch Sheet: / Devtank Ltd Part No: 304-001

Id: 1/12 Title: HILTOP Motherboard

GND
*LOAD RESISTORS - REQ'D
FOR SOME ATX PSU's

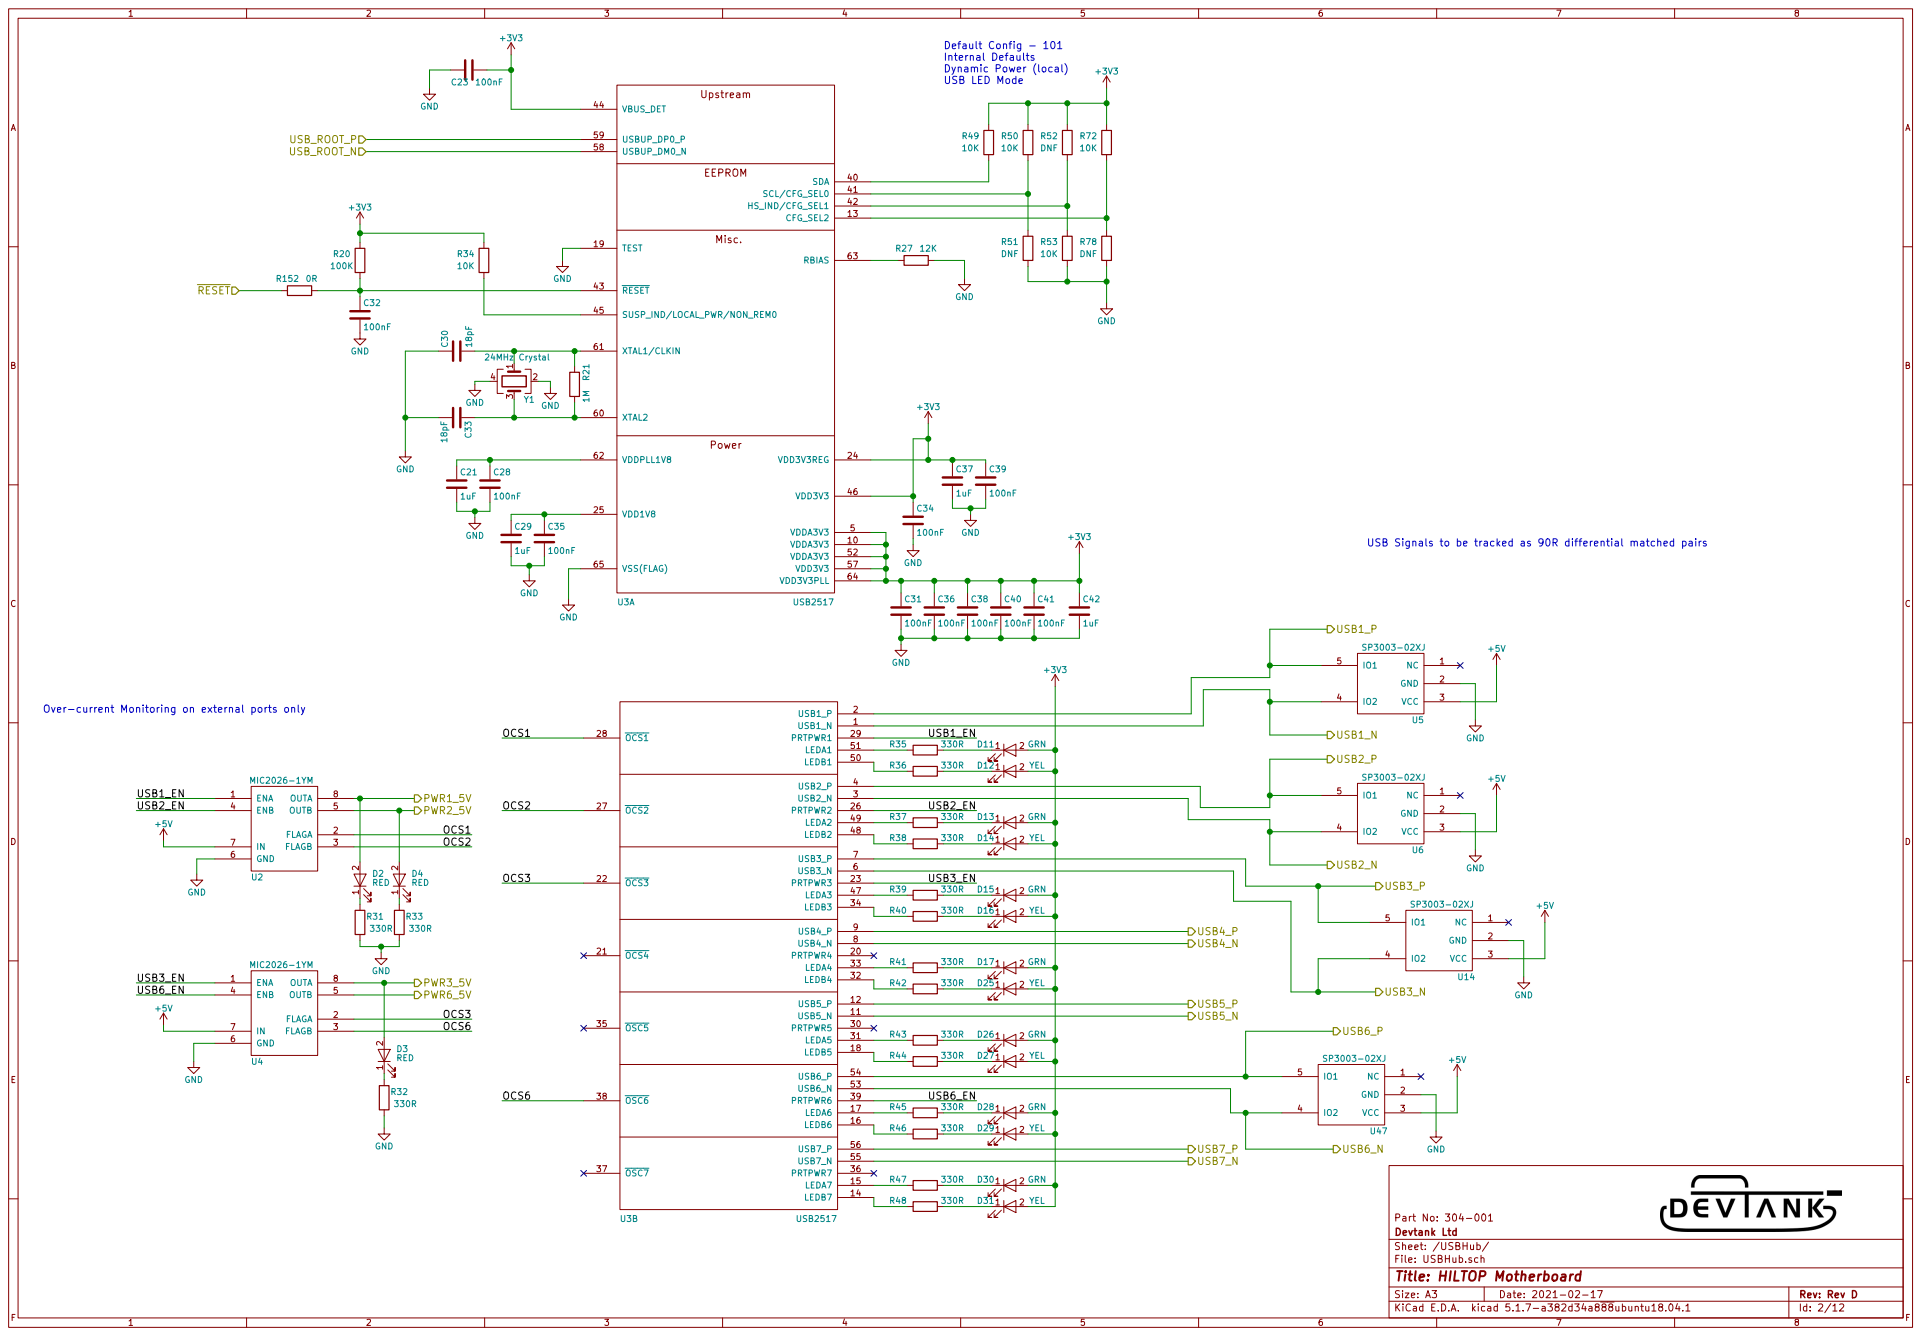
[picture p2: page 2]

Default Config - 101
Internal Defaults Dynamic Power (local)
+3V3 R78 DNF R53

USB Signals to be tracked as 90R differential matched pairs

Over-current Monitoring on external ports only

File: USBHub.sch Sheet: /USBHub/ Devtank Ltd Part No: 304-001 GND

Id: 2/12 Title: HILTOP Motherboard

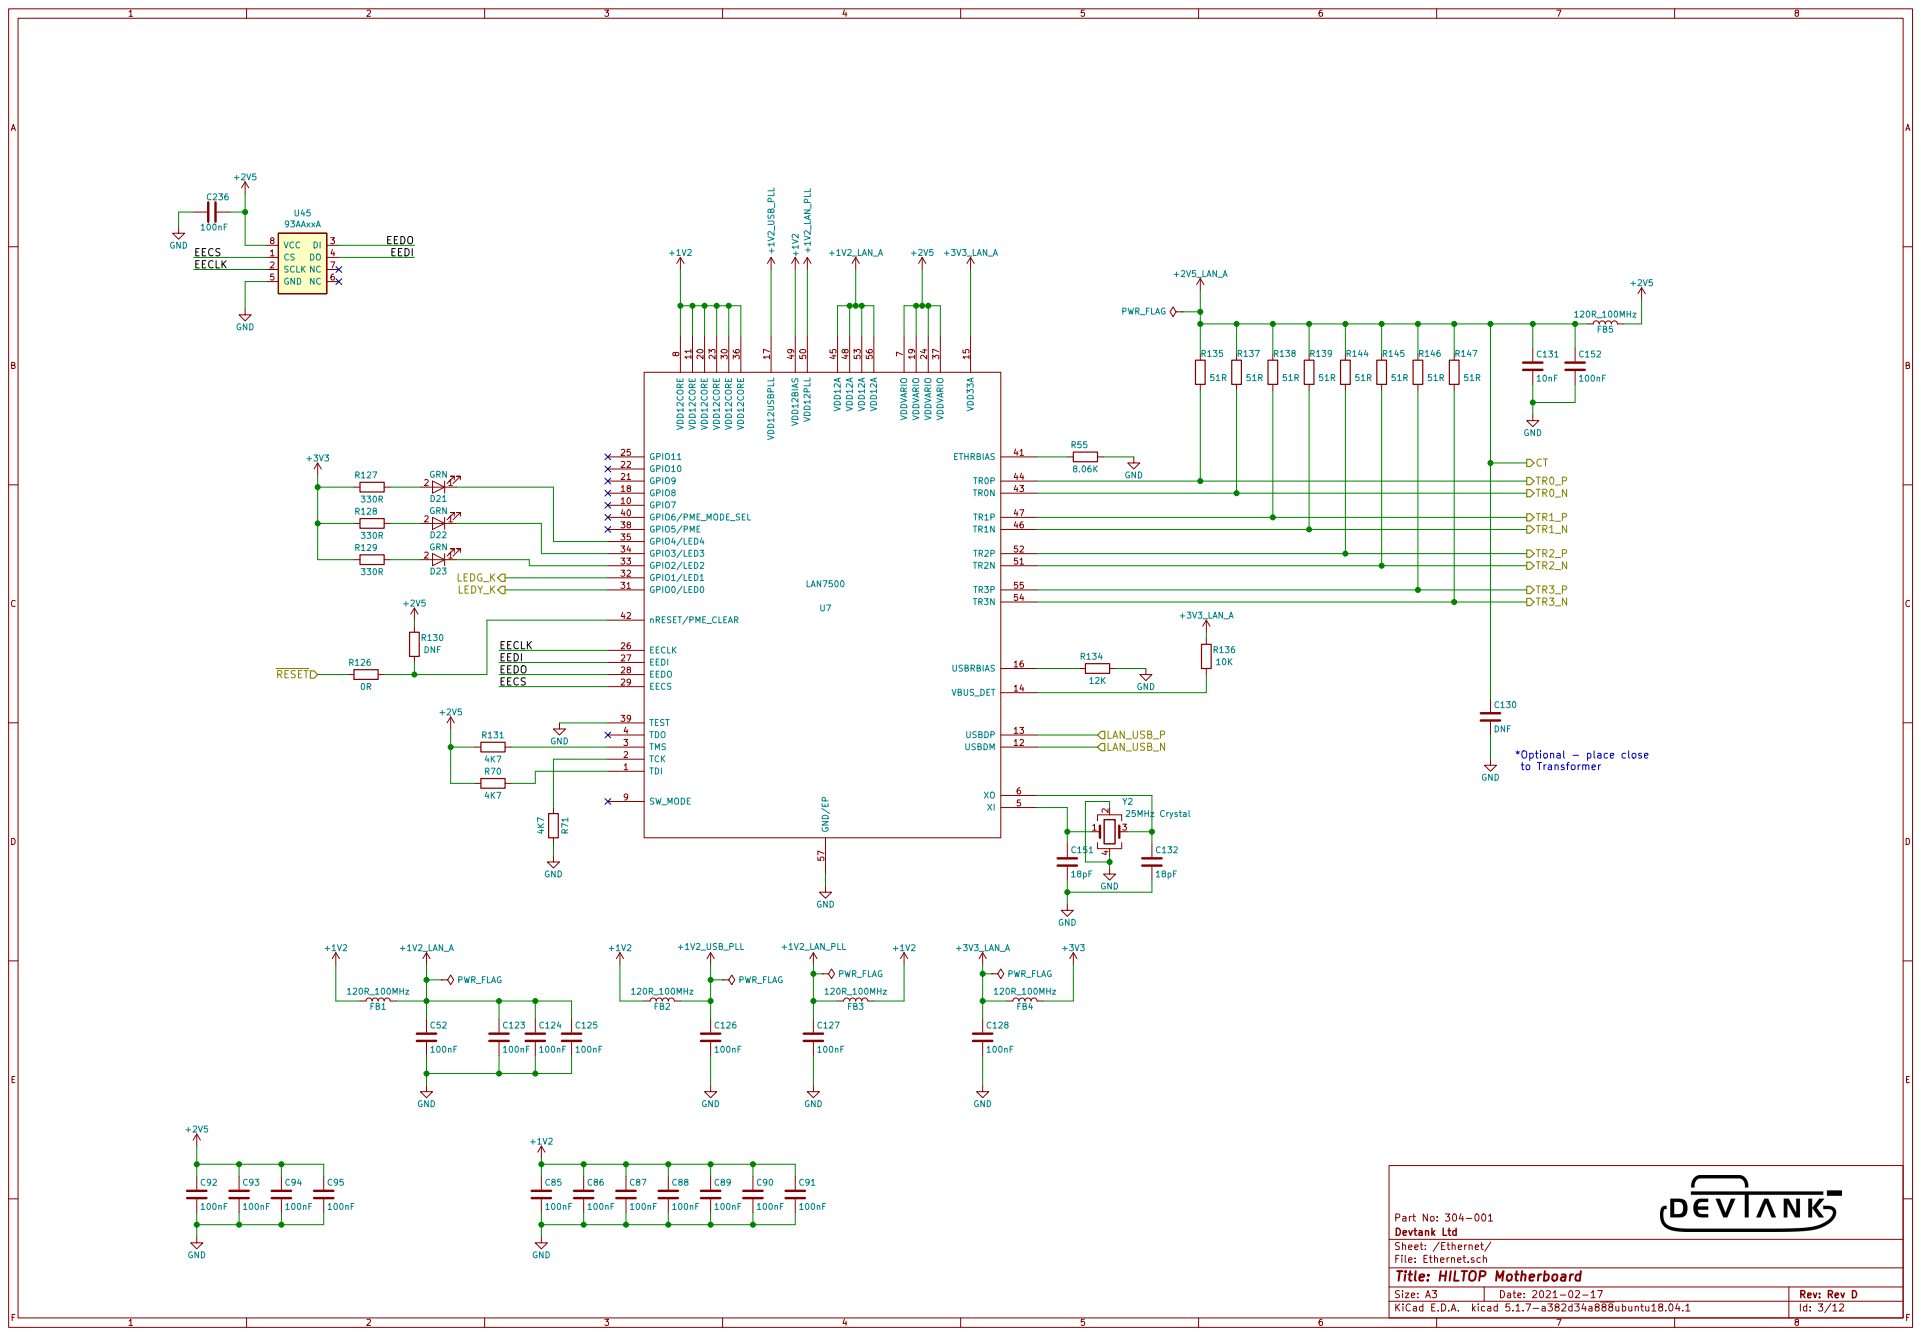
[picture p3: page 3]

File: Ethernet.sch Sheet: /Ethernet/ Devtank Ltd Part No: 304-001

Id: 3/12 Title: HILTOP Motherboard

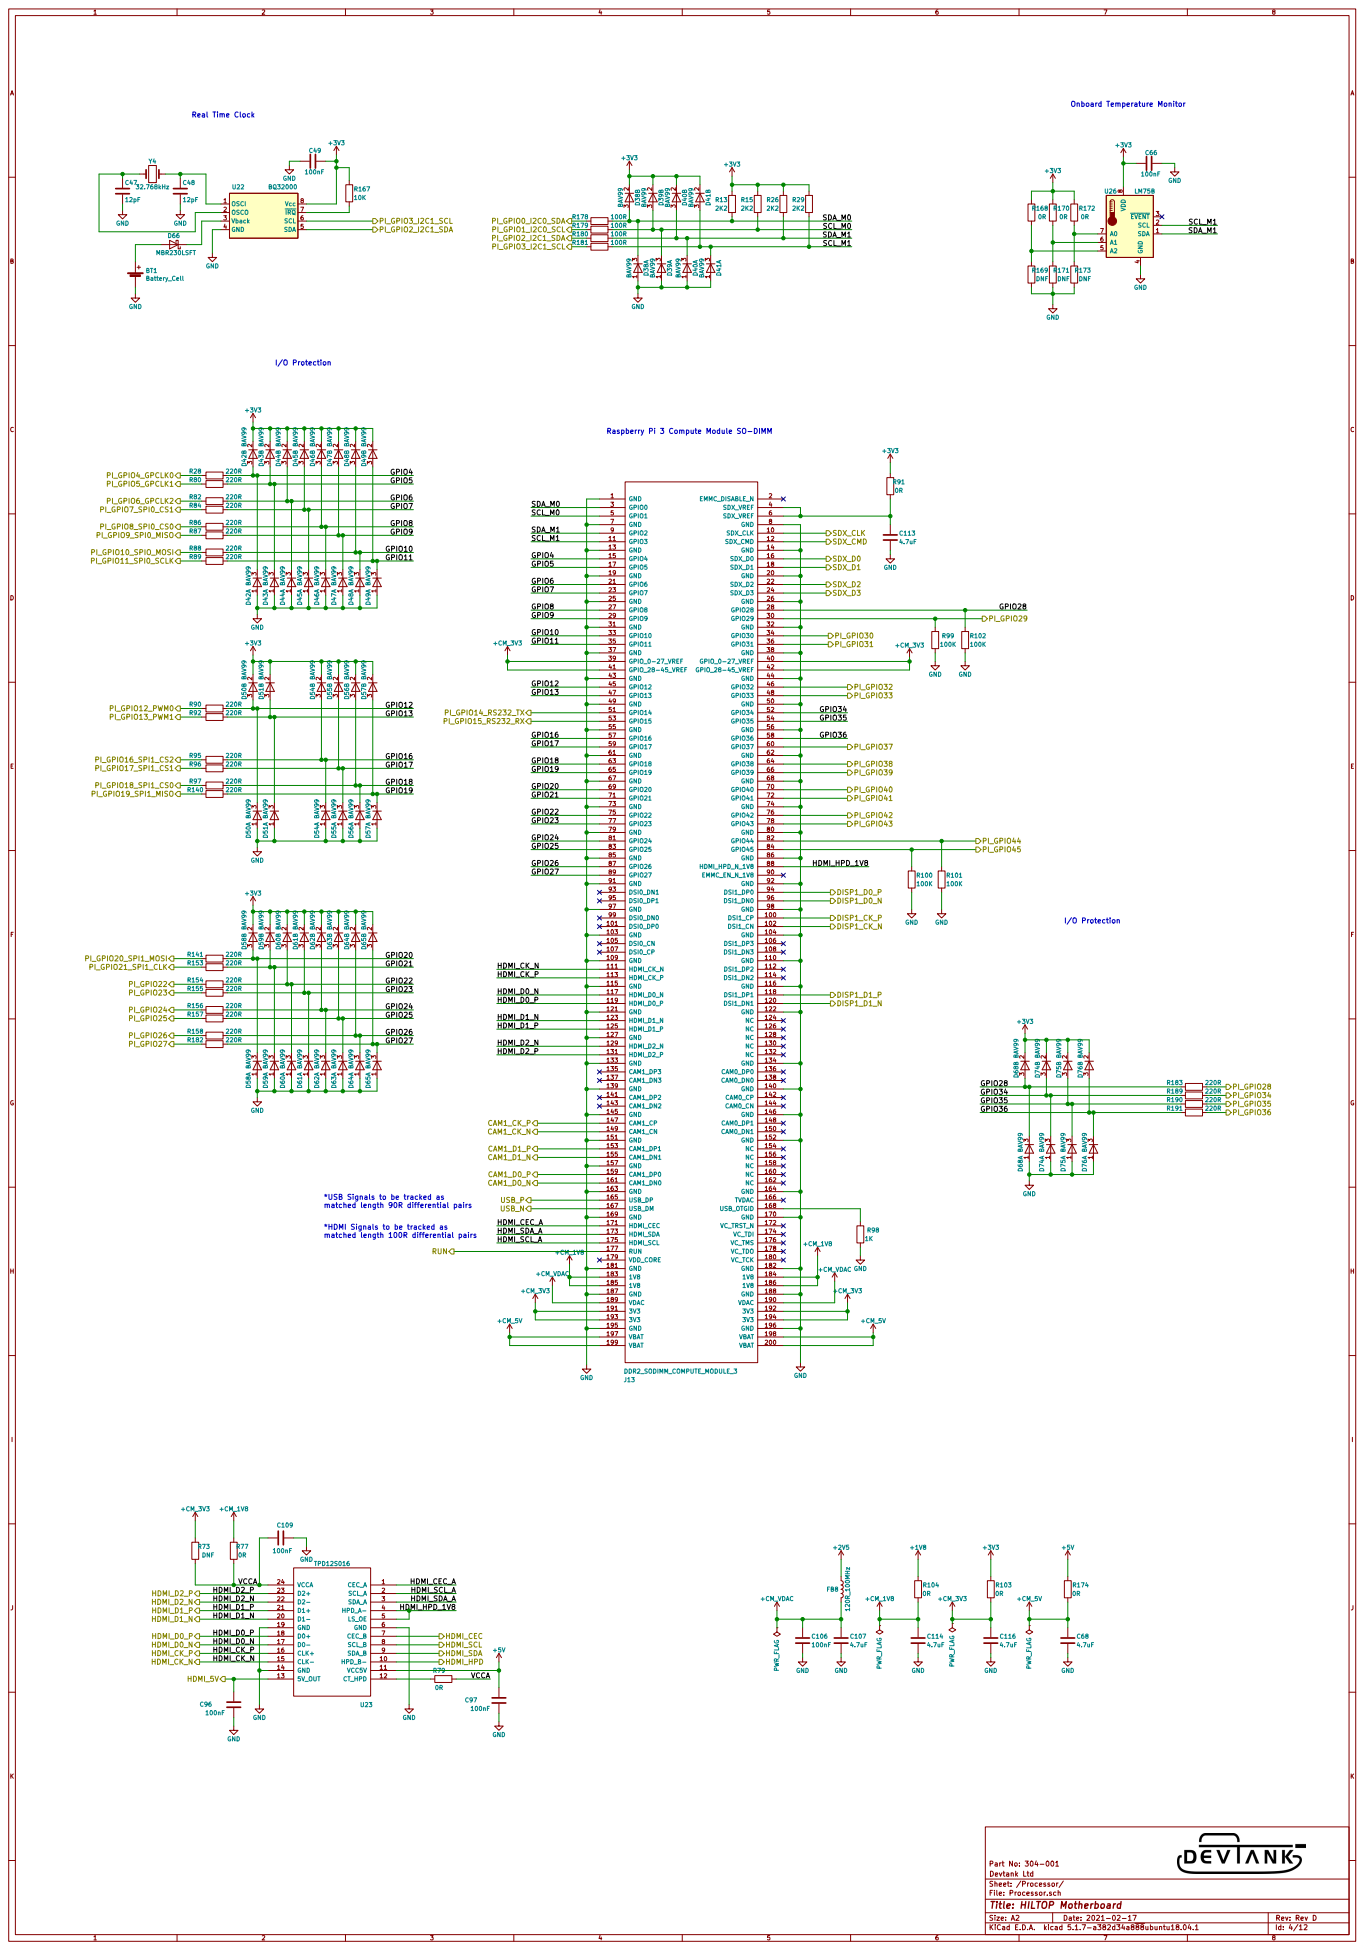
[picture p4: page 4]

Raspberry Pi 3 Compute Module SO-DIMM

*USB Signals to be tracked as
matched length 90R differential pairs

*HDMI Signals to be tracked as
matched length 100R differential pairs

File: Processor.sch Sheet: /Processor/ Devtank Ltd Part No: 304-001

Id: 4/12 Title: HILTOP Motherboard

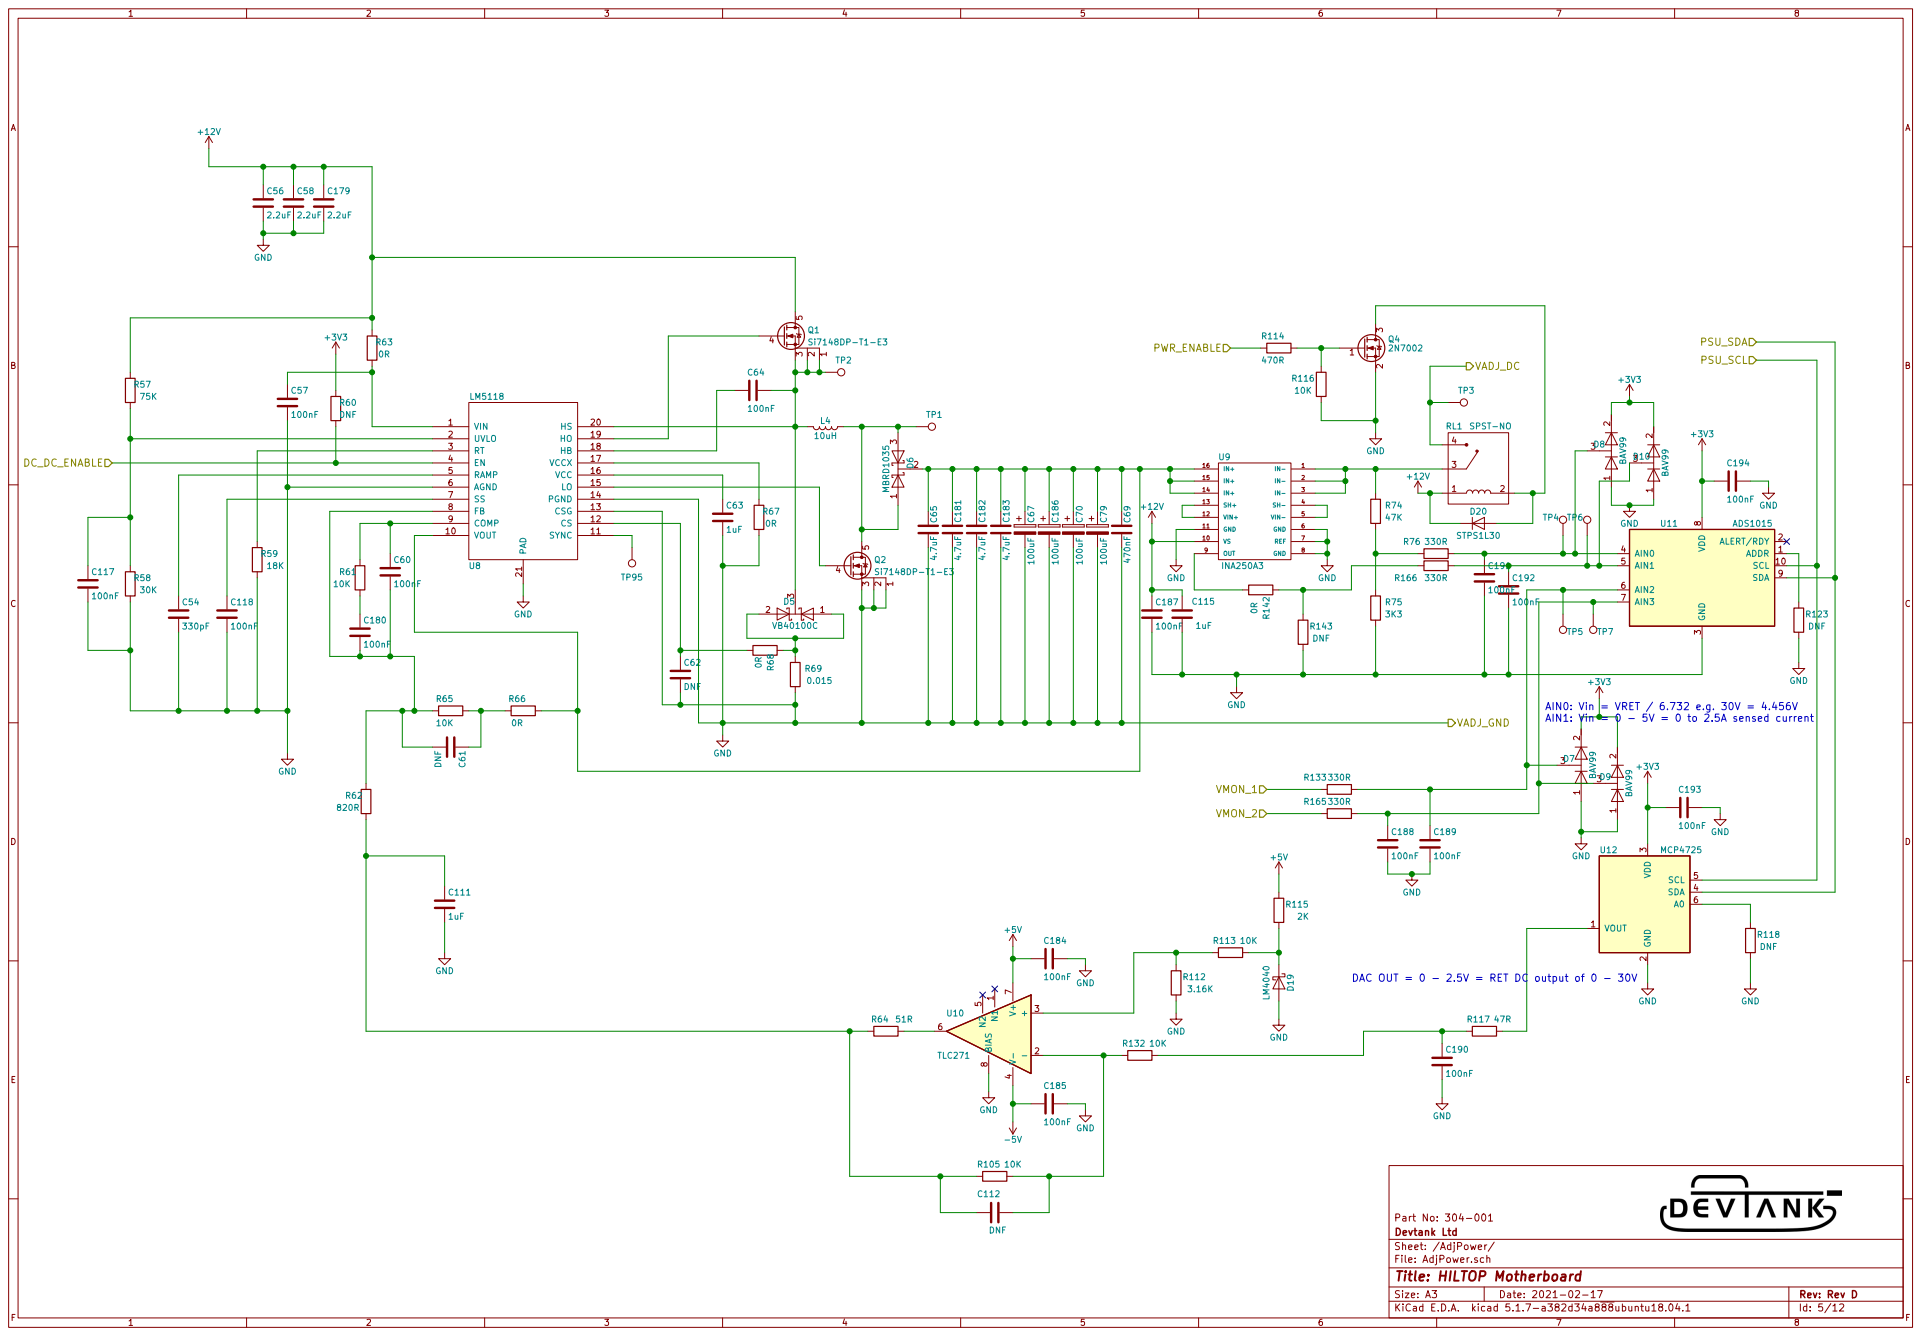
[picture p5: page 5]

AIN1: Vin = 0 - 5V = 0 to 2.5A sensed current DAC OUT = 0 - 2.5V = RET DC output of 0 - 30V

Sheet: /AdjPower/ Devtank Ltd Part No: 304-001

File: AdjPower.sch
Id: 5/12 Title: HILTOP Motherboard

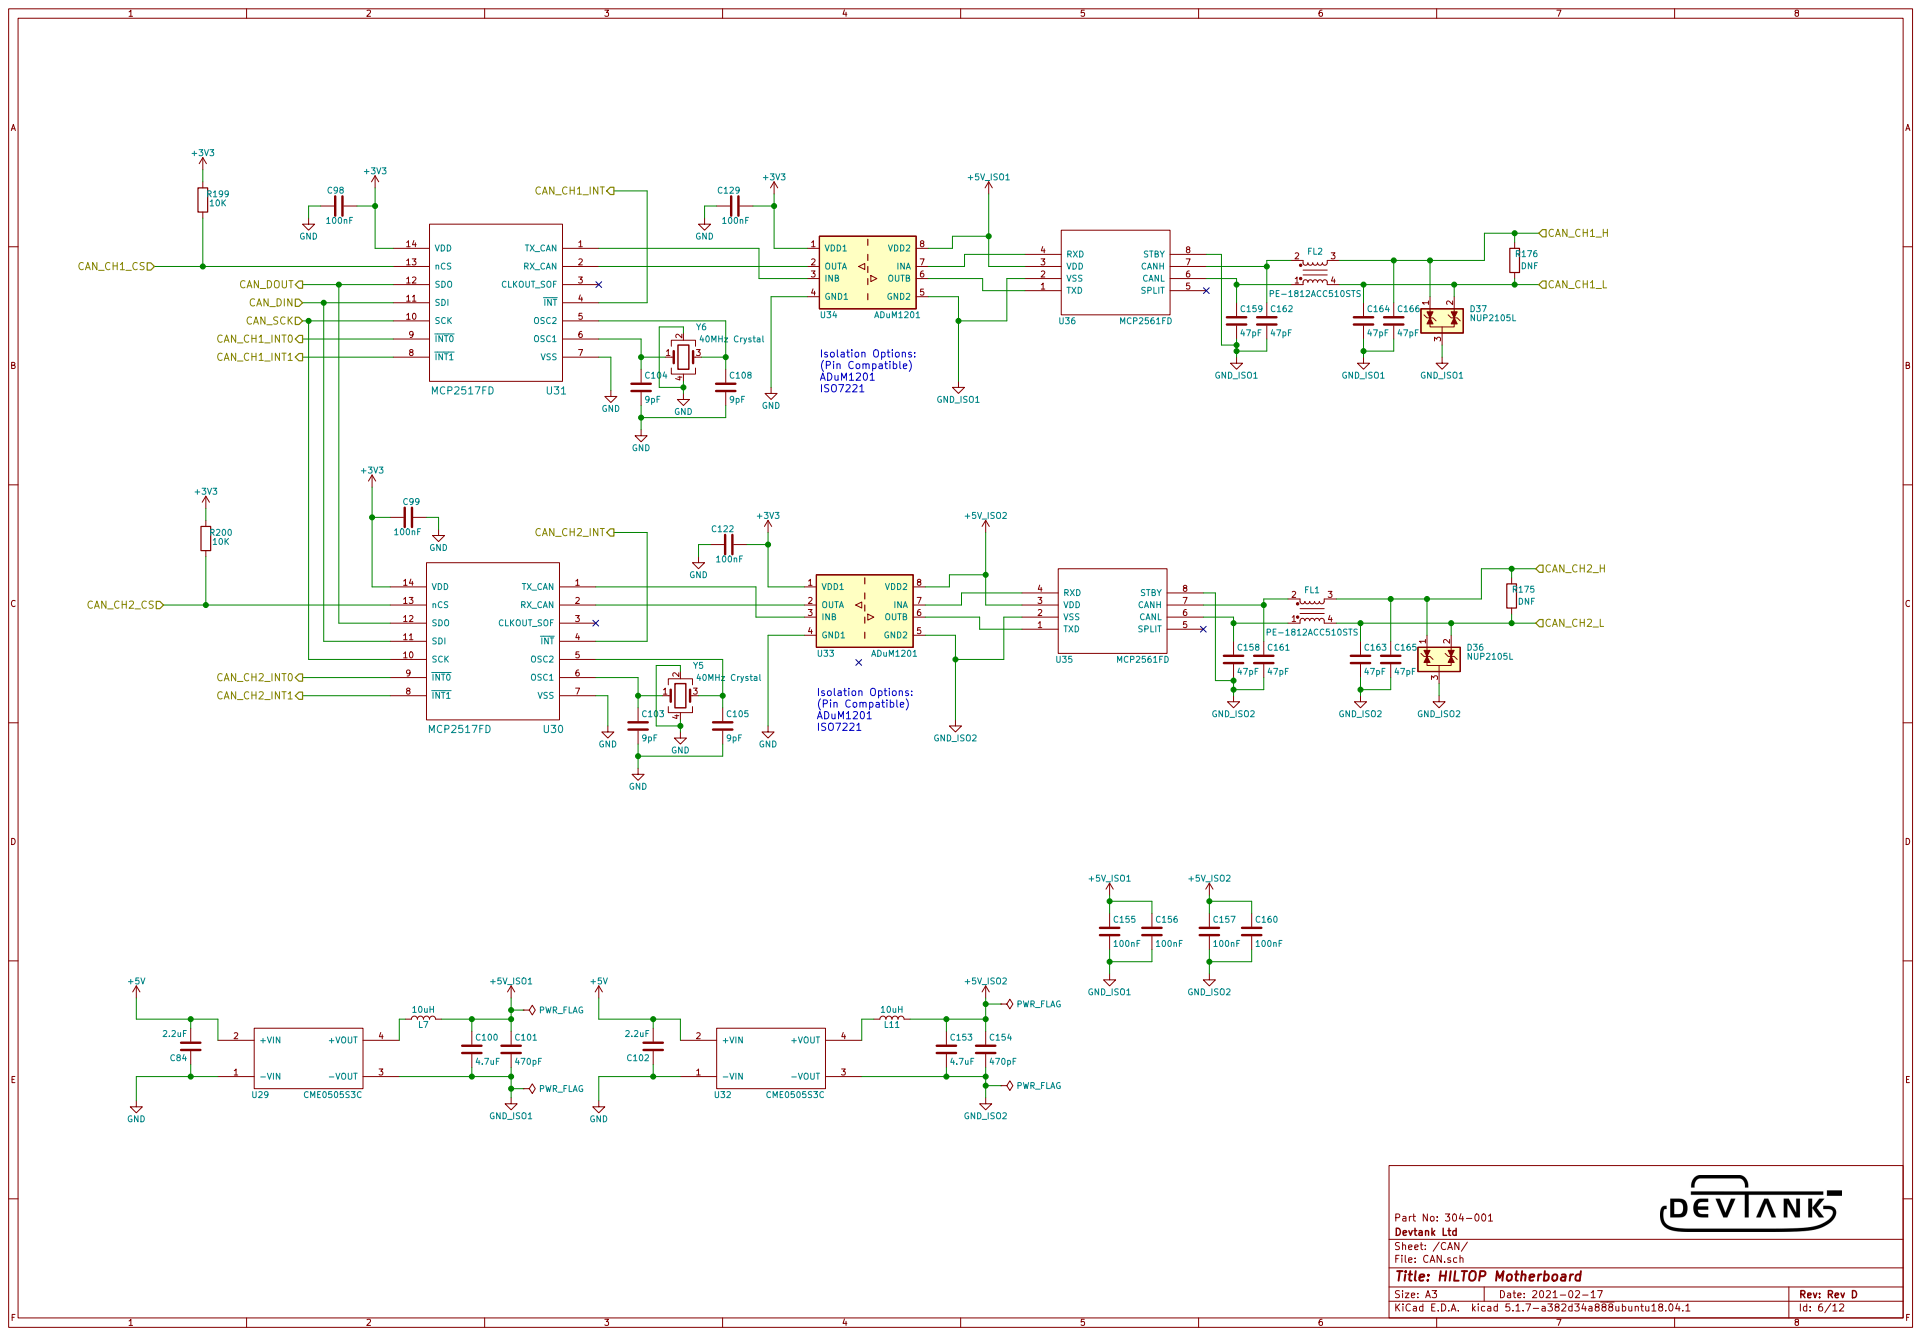
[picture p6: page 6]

File: CAN.sch Sheet: /CAN/ Devtank Ltd Part No: 304-001

Id: 6/12 Title: HILTOP Motherboard

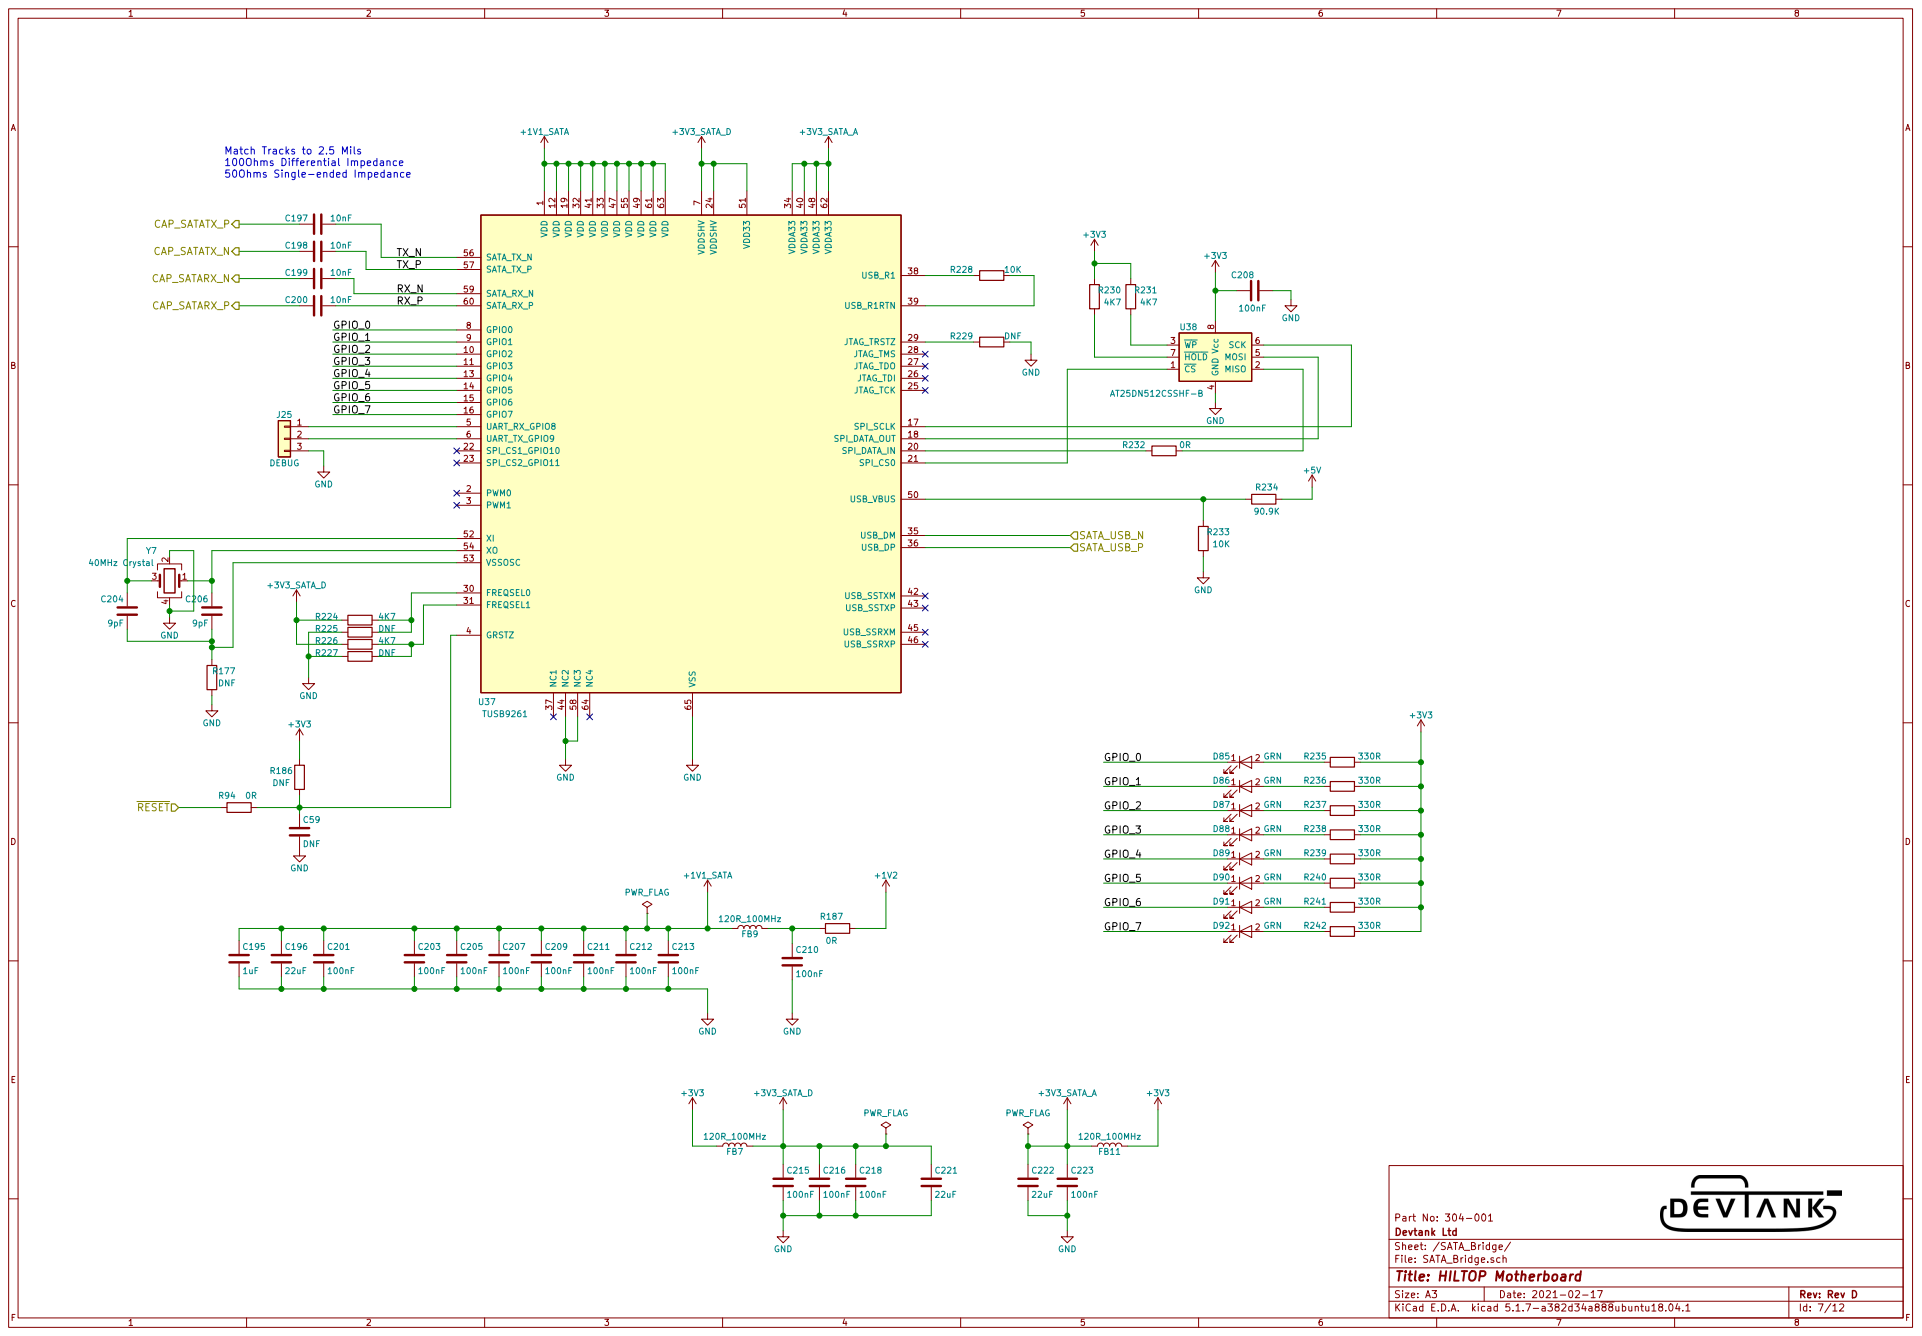
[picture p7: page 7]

GPIO_5 Match Tracks to 2.5 Mils 100Ohms Differential Impedance

4 MOSI 5 SCK 6 HOLD 7 Vcc U38 8 AT25DN512CSSHF-B VDD

Sheet: /SATA_Bridge/ Devtank Ltd Part No: 304-001

File: SATA_Bridge.sch
Id: 7/12 Title: HILTOP Motherboard

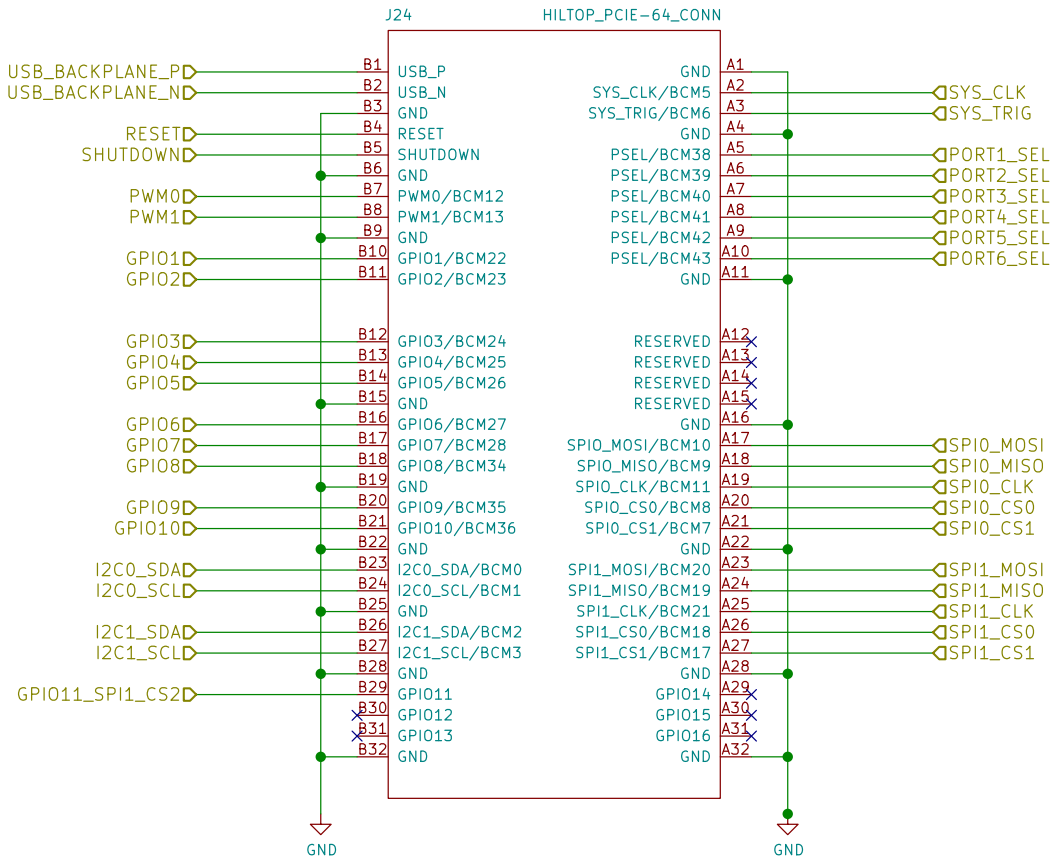
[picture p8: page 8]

Id: 8/12 Title: HILTOP Motherboard

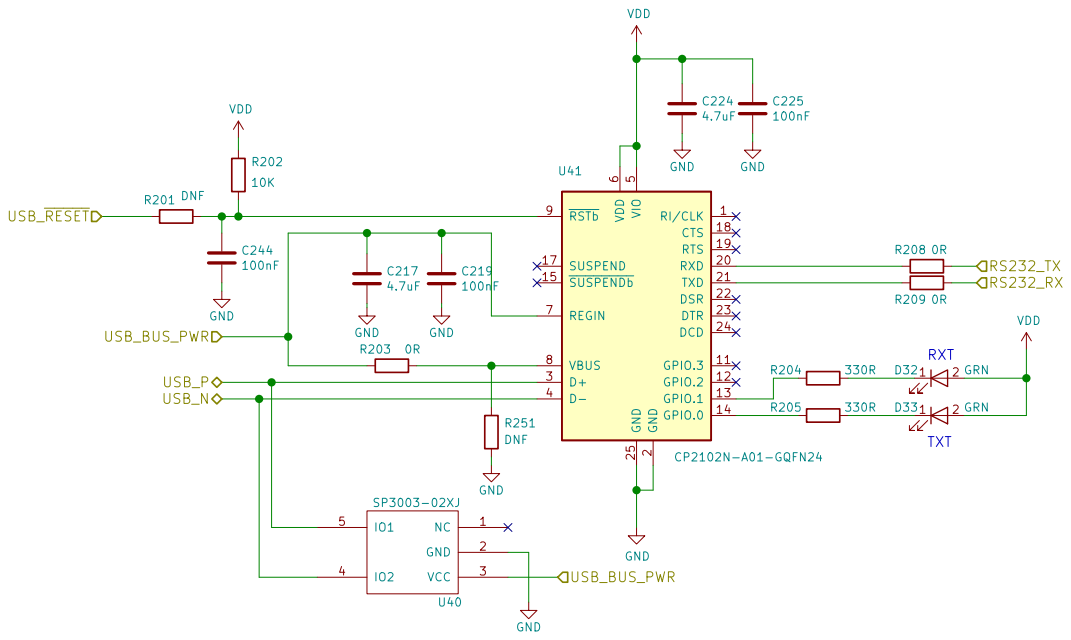
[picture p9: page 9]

2 RXD 20 TXD 21 DSR 22 DTR 23 DCD 24 GND 25 D+ 3 D- 4 VIO

Sheet: /USB_Debug/ Devtank Ltd Part No: 304-001 GND

File: USB_Debug.sch
Id: 9/12 Title: HILTOP Motherboard

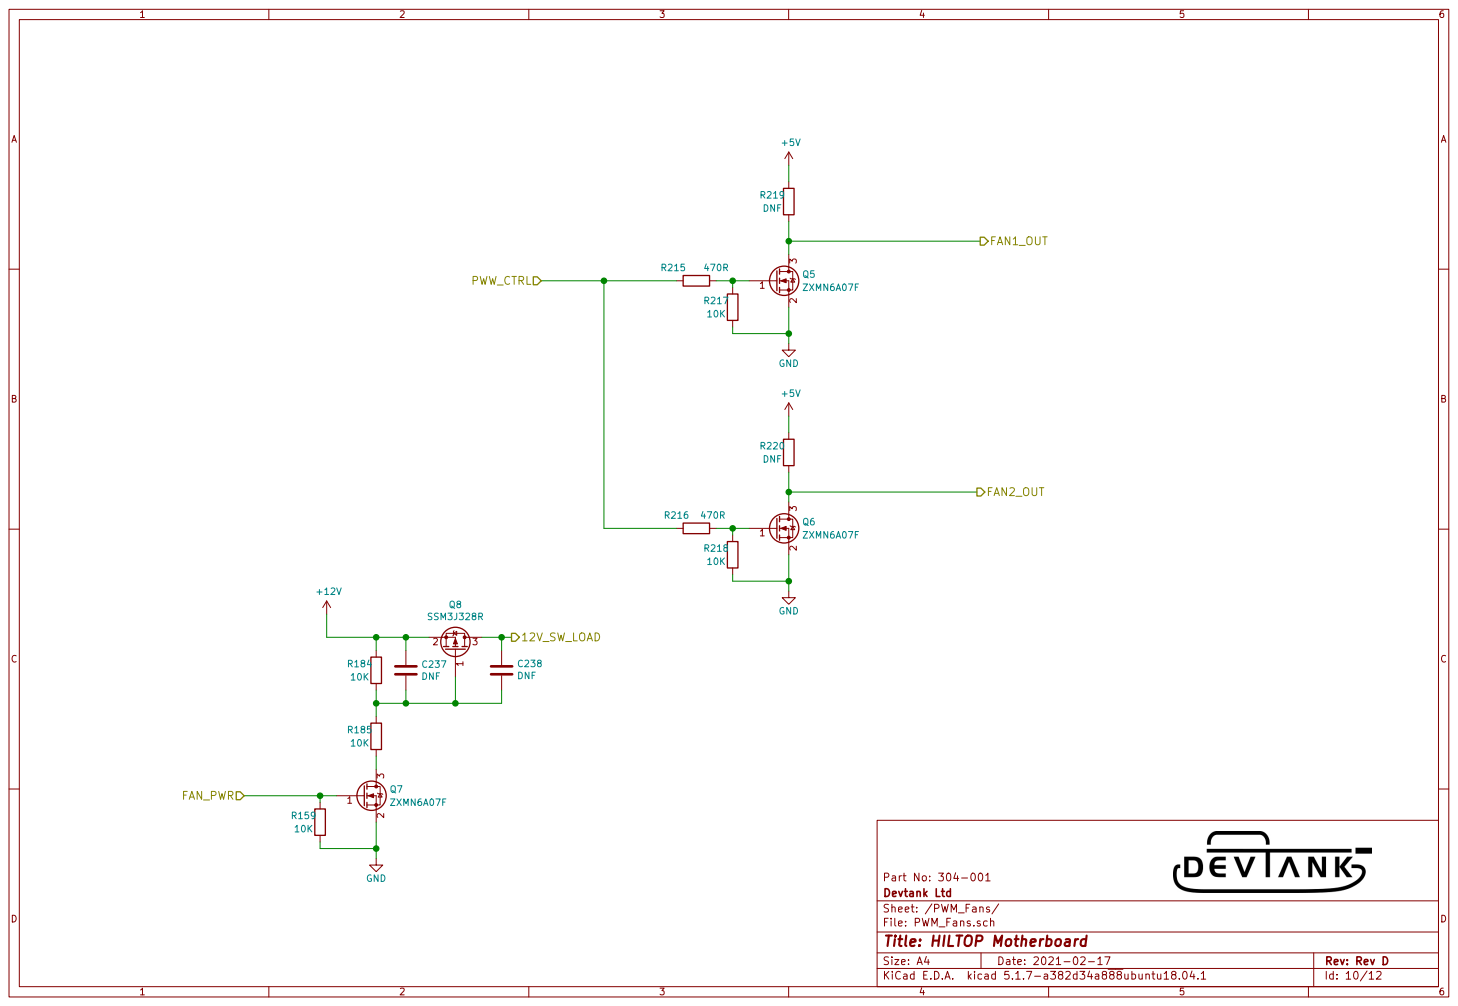
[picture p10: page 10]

Sheet: /PWM_Fans/ Devtank Ltd Part No: 304-001 R218

File: PWM_Fans.sch
Id: 10/12 Title: HILTOP Motherboard

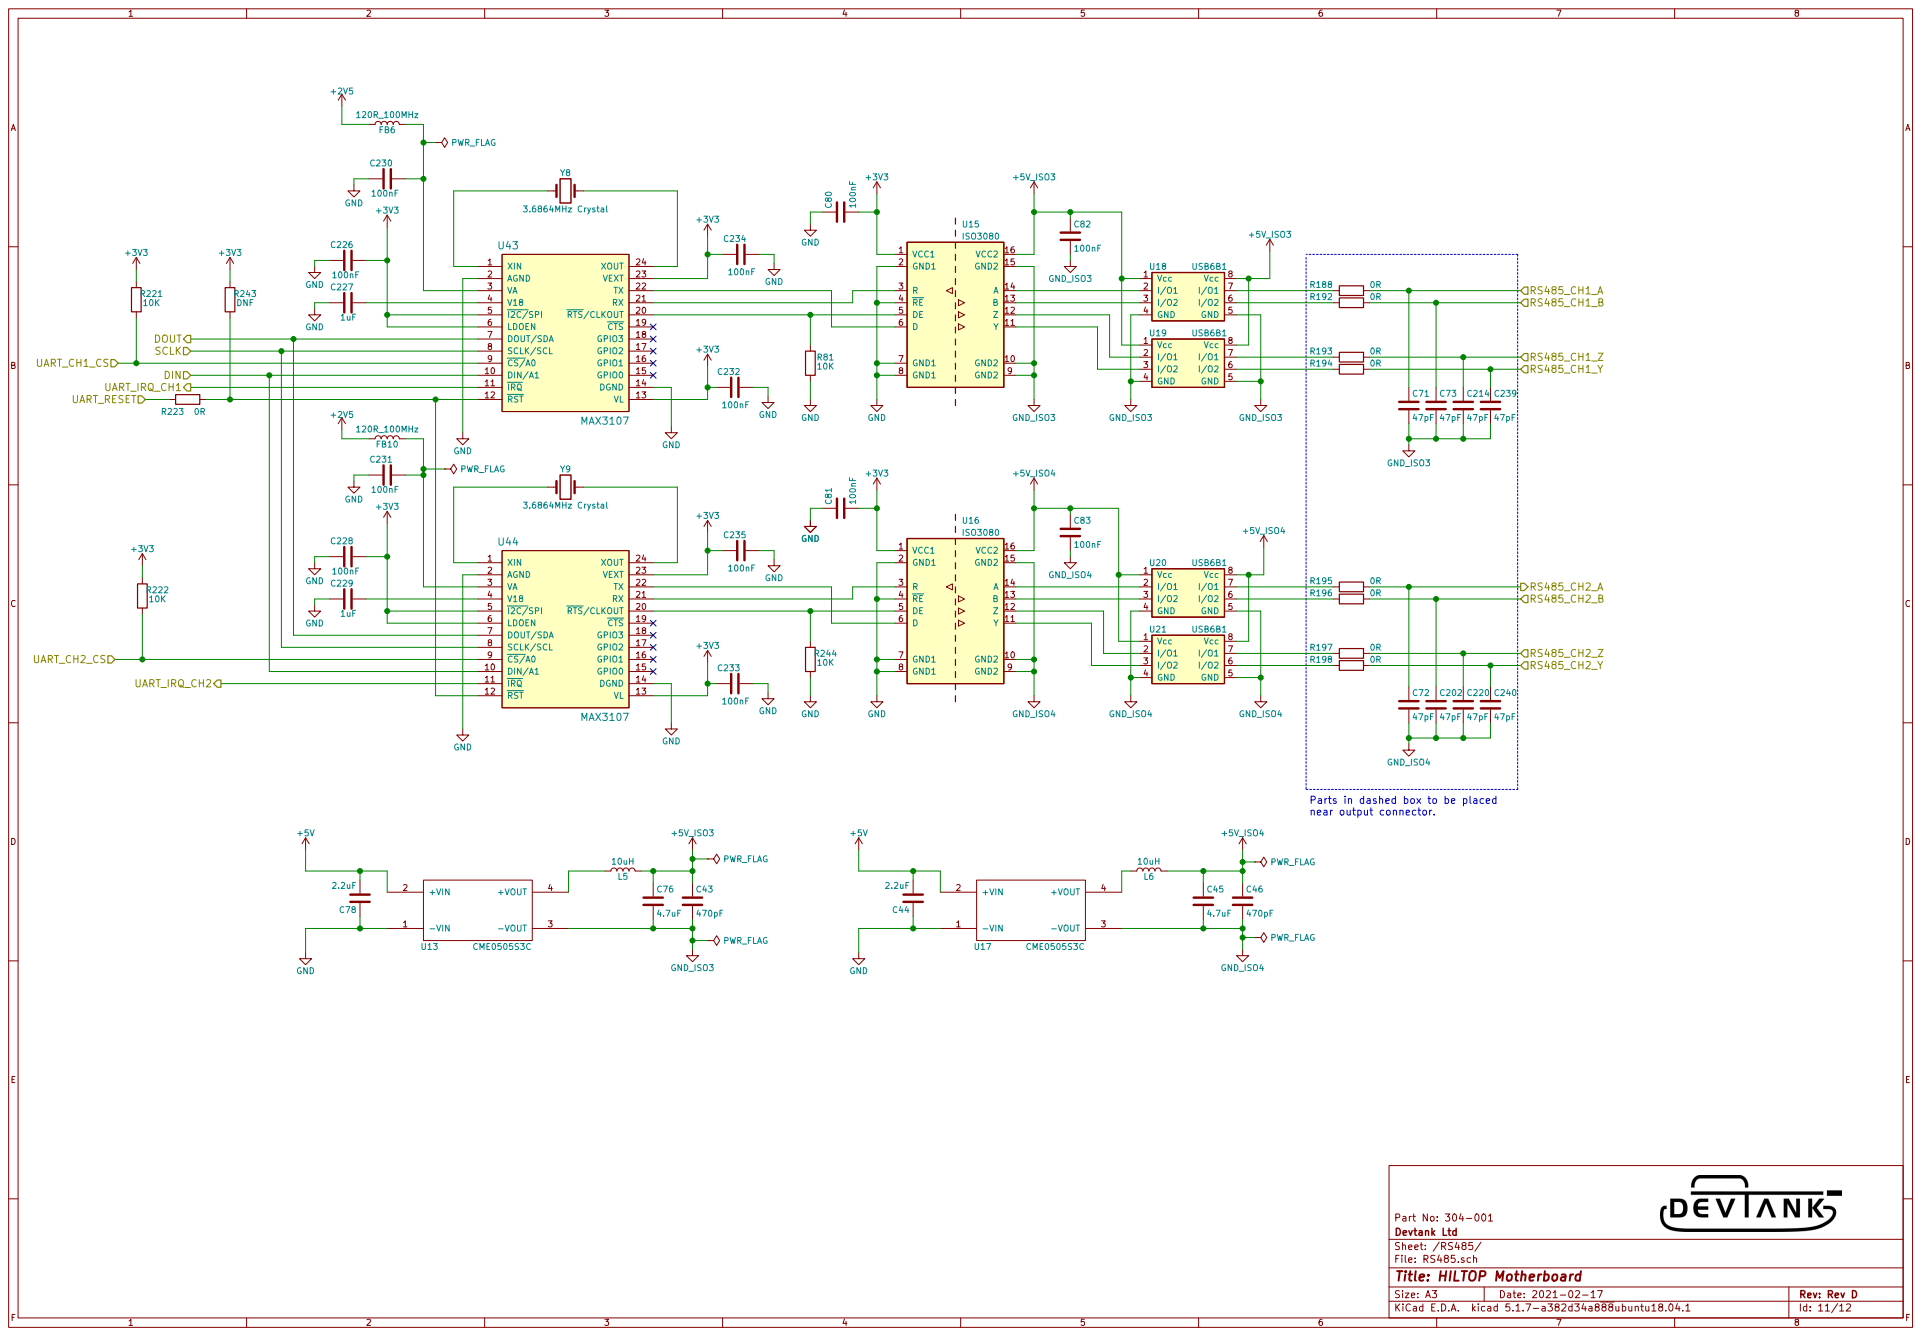
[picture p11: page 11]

Parts in dashed box to be placed
near output connector.

File: RS485.sch Sheet: /RS485/ Devtank Ltd Part No: 304-001

Id: 11/12 Title: HILTOP Motherboard

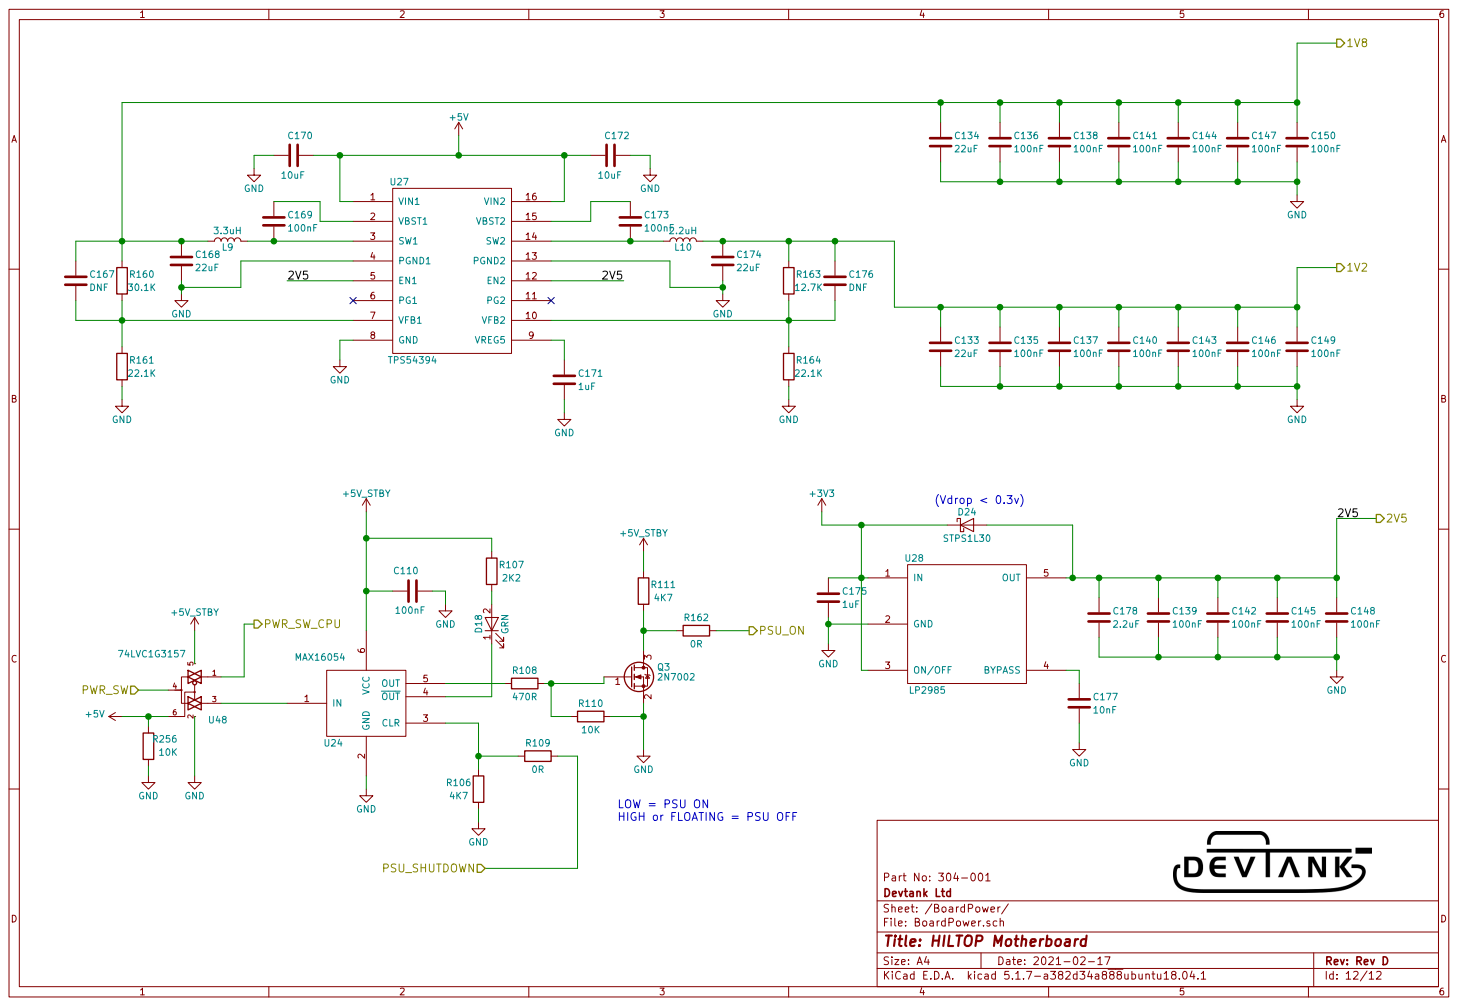
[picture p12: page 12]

2 CLR 3 OUT 4 OUT 5 VCC

LOW = PSU ON
HIGH or FLOATING = PSU OFF

File: BoardPower.sch Sheet: /BoardPower/ Devtank Ltd Part No: 304-001

Id: 12/12 Title: HILTOP Motherboard

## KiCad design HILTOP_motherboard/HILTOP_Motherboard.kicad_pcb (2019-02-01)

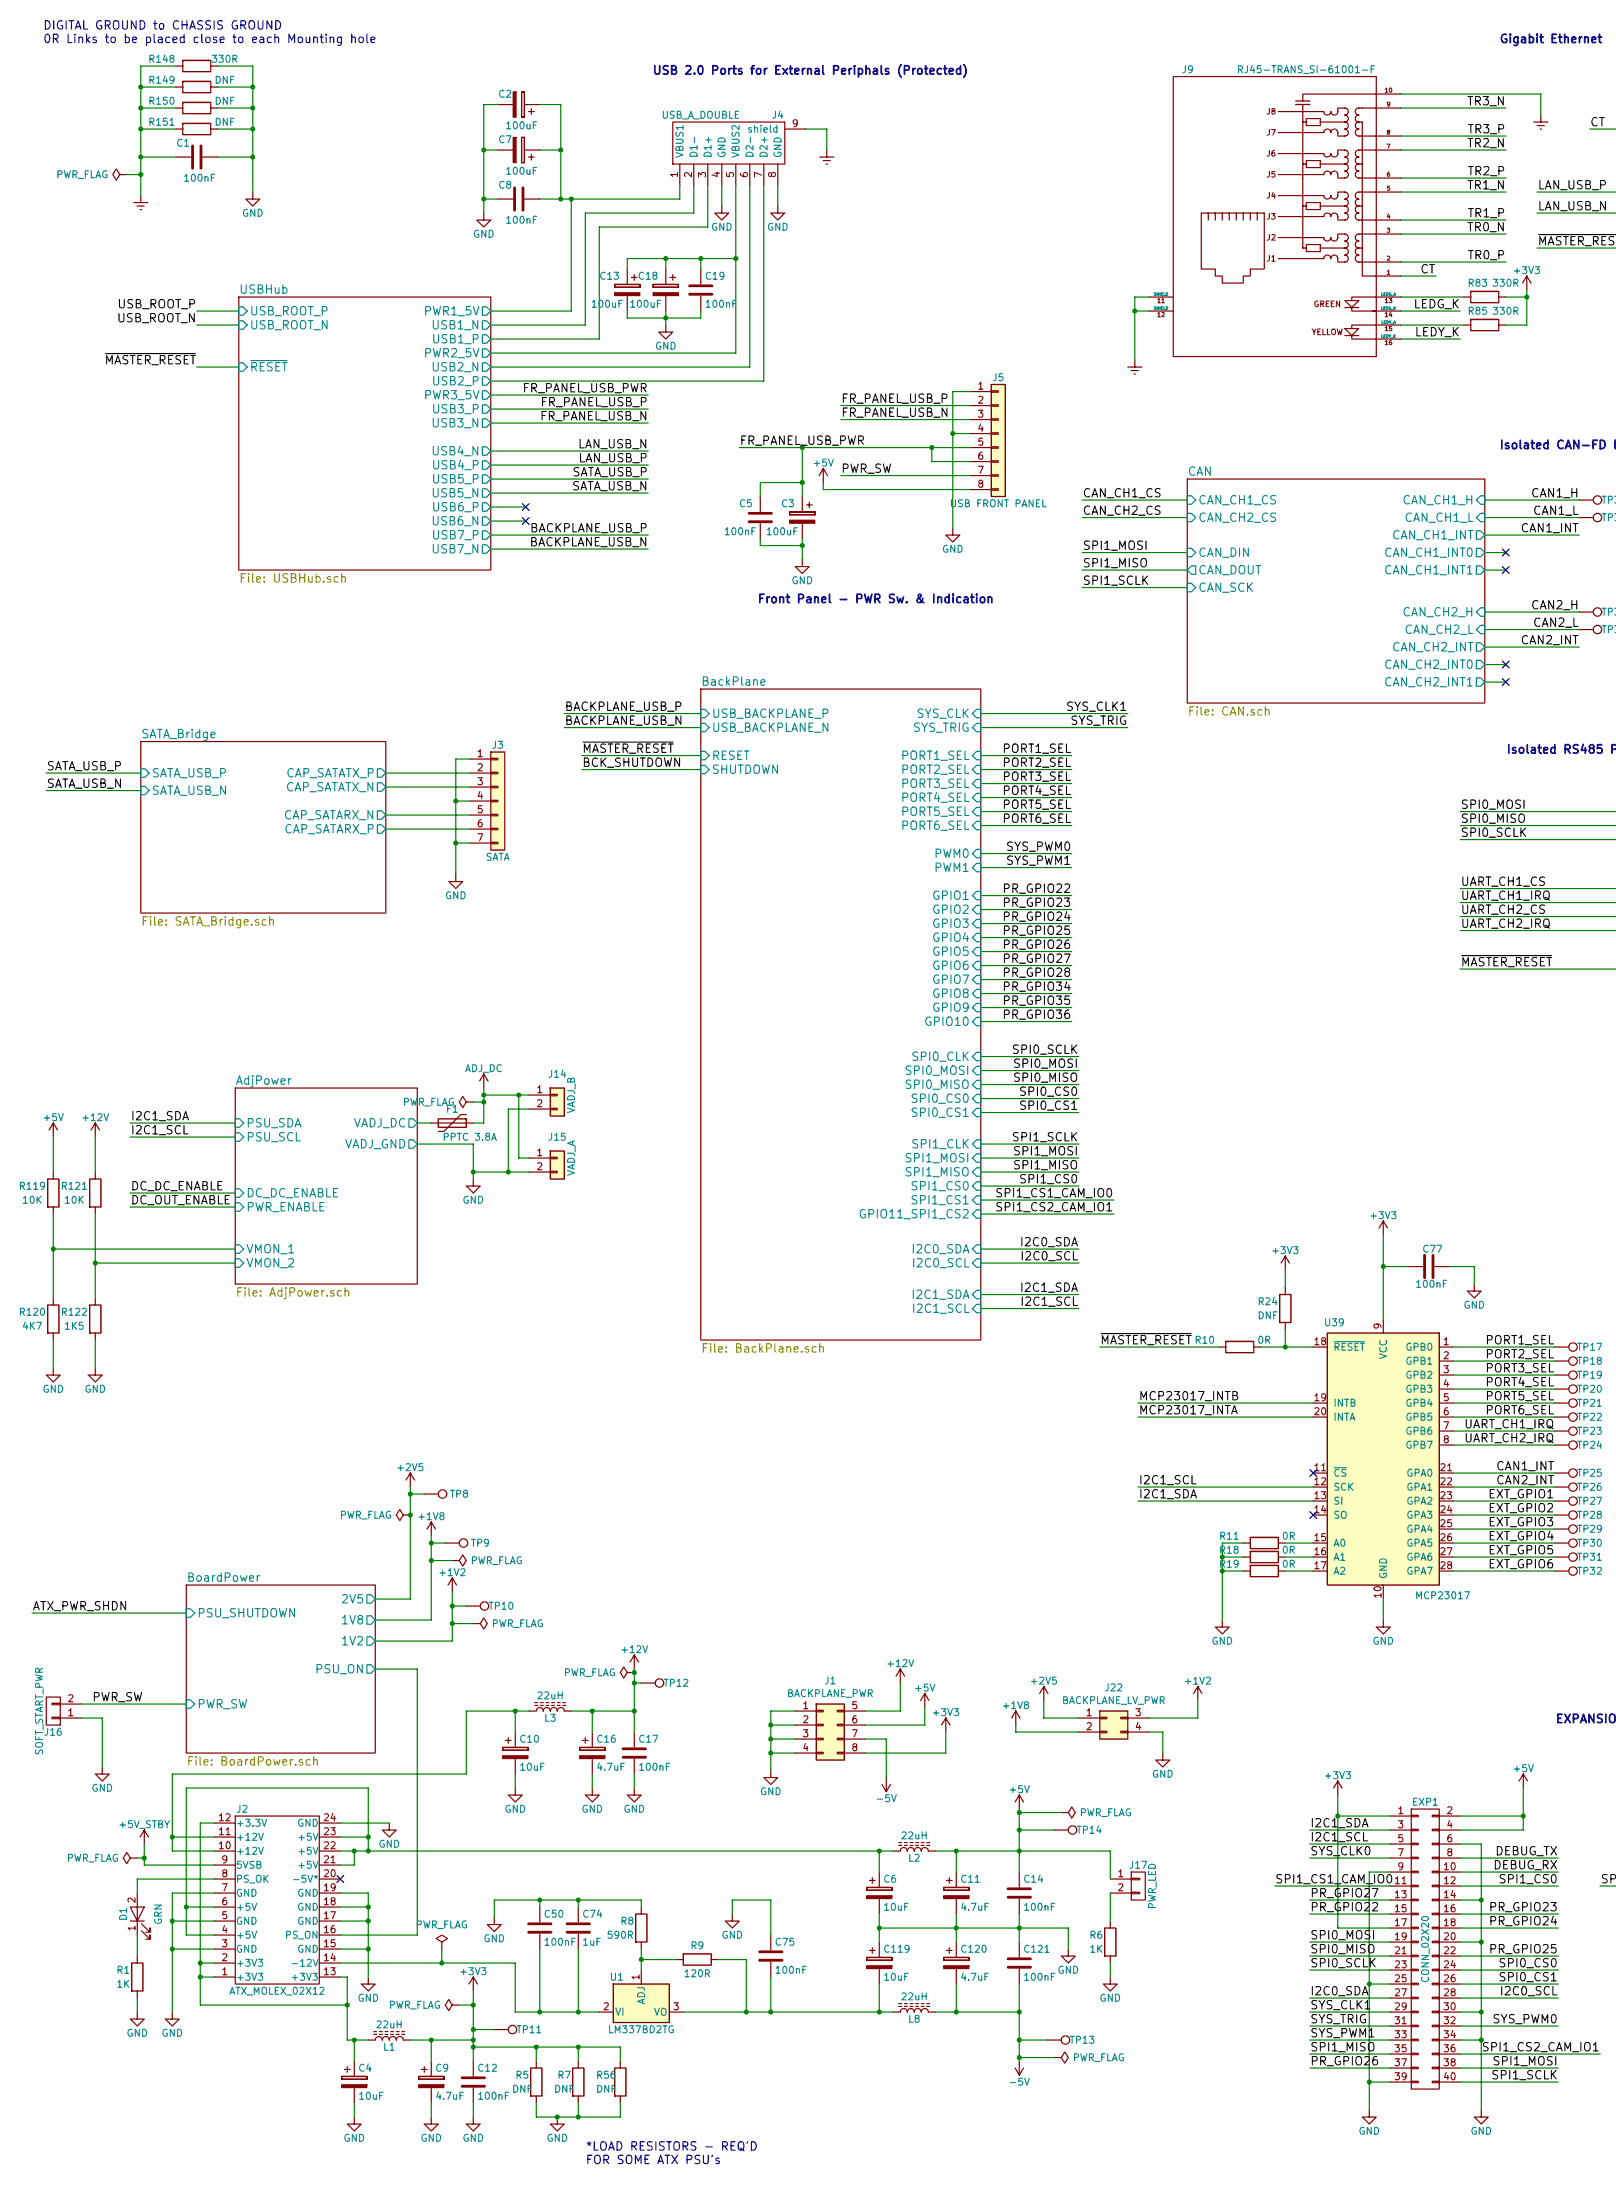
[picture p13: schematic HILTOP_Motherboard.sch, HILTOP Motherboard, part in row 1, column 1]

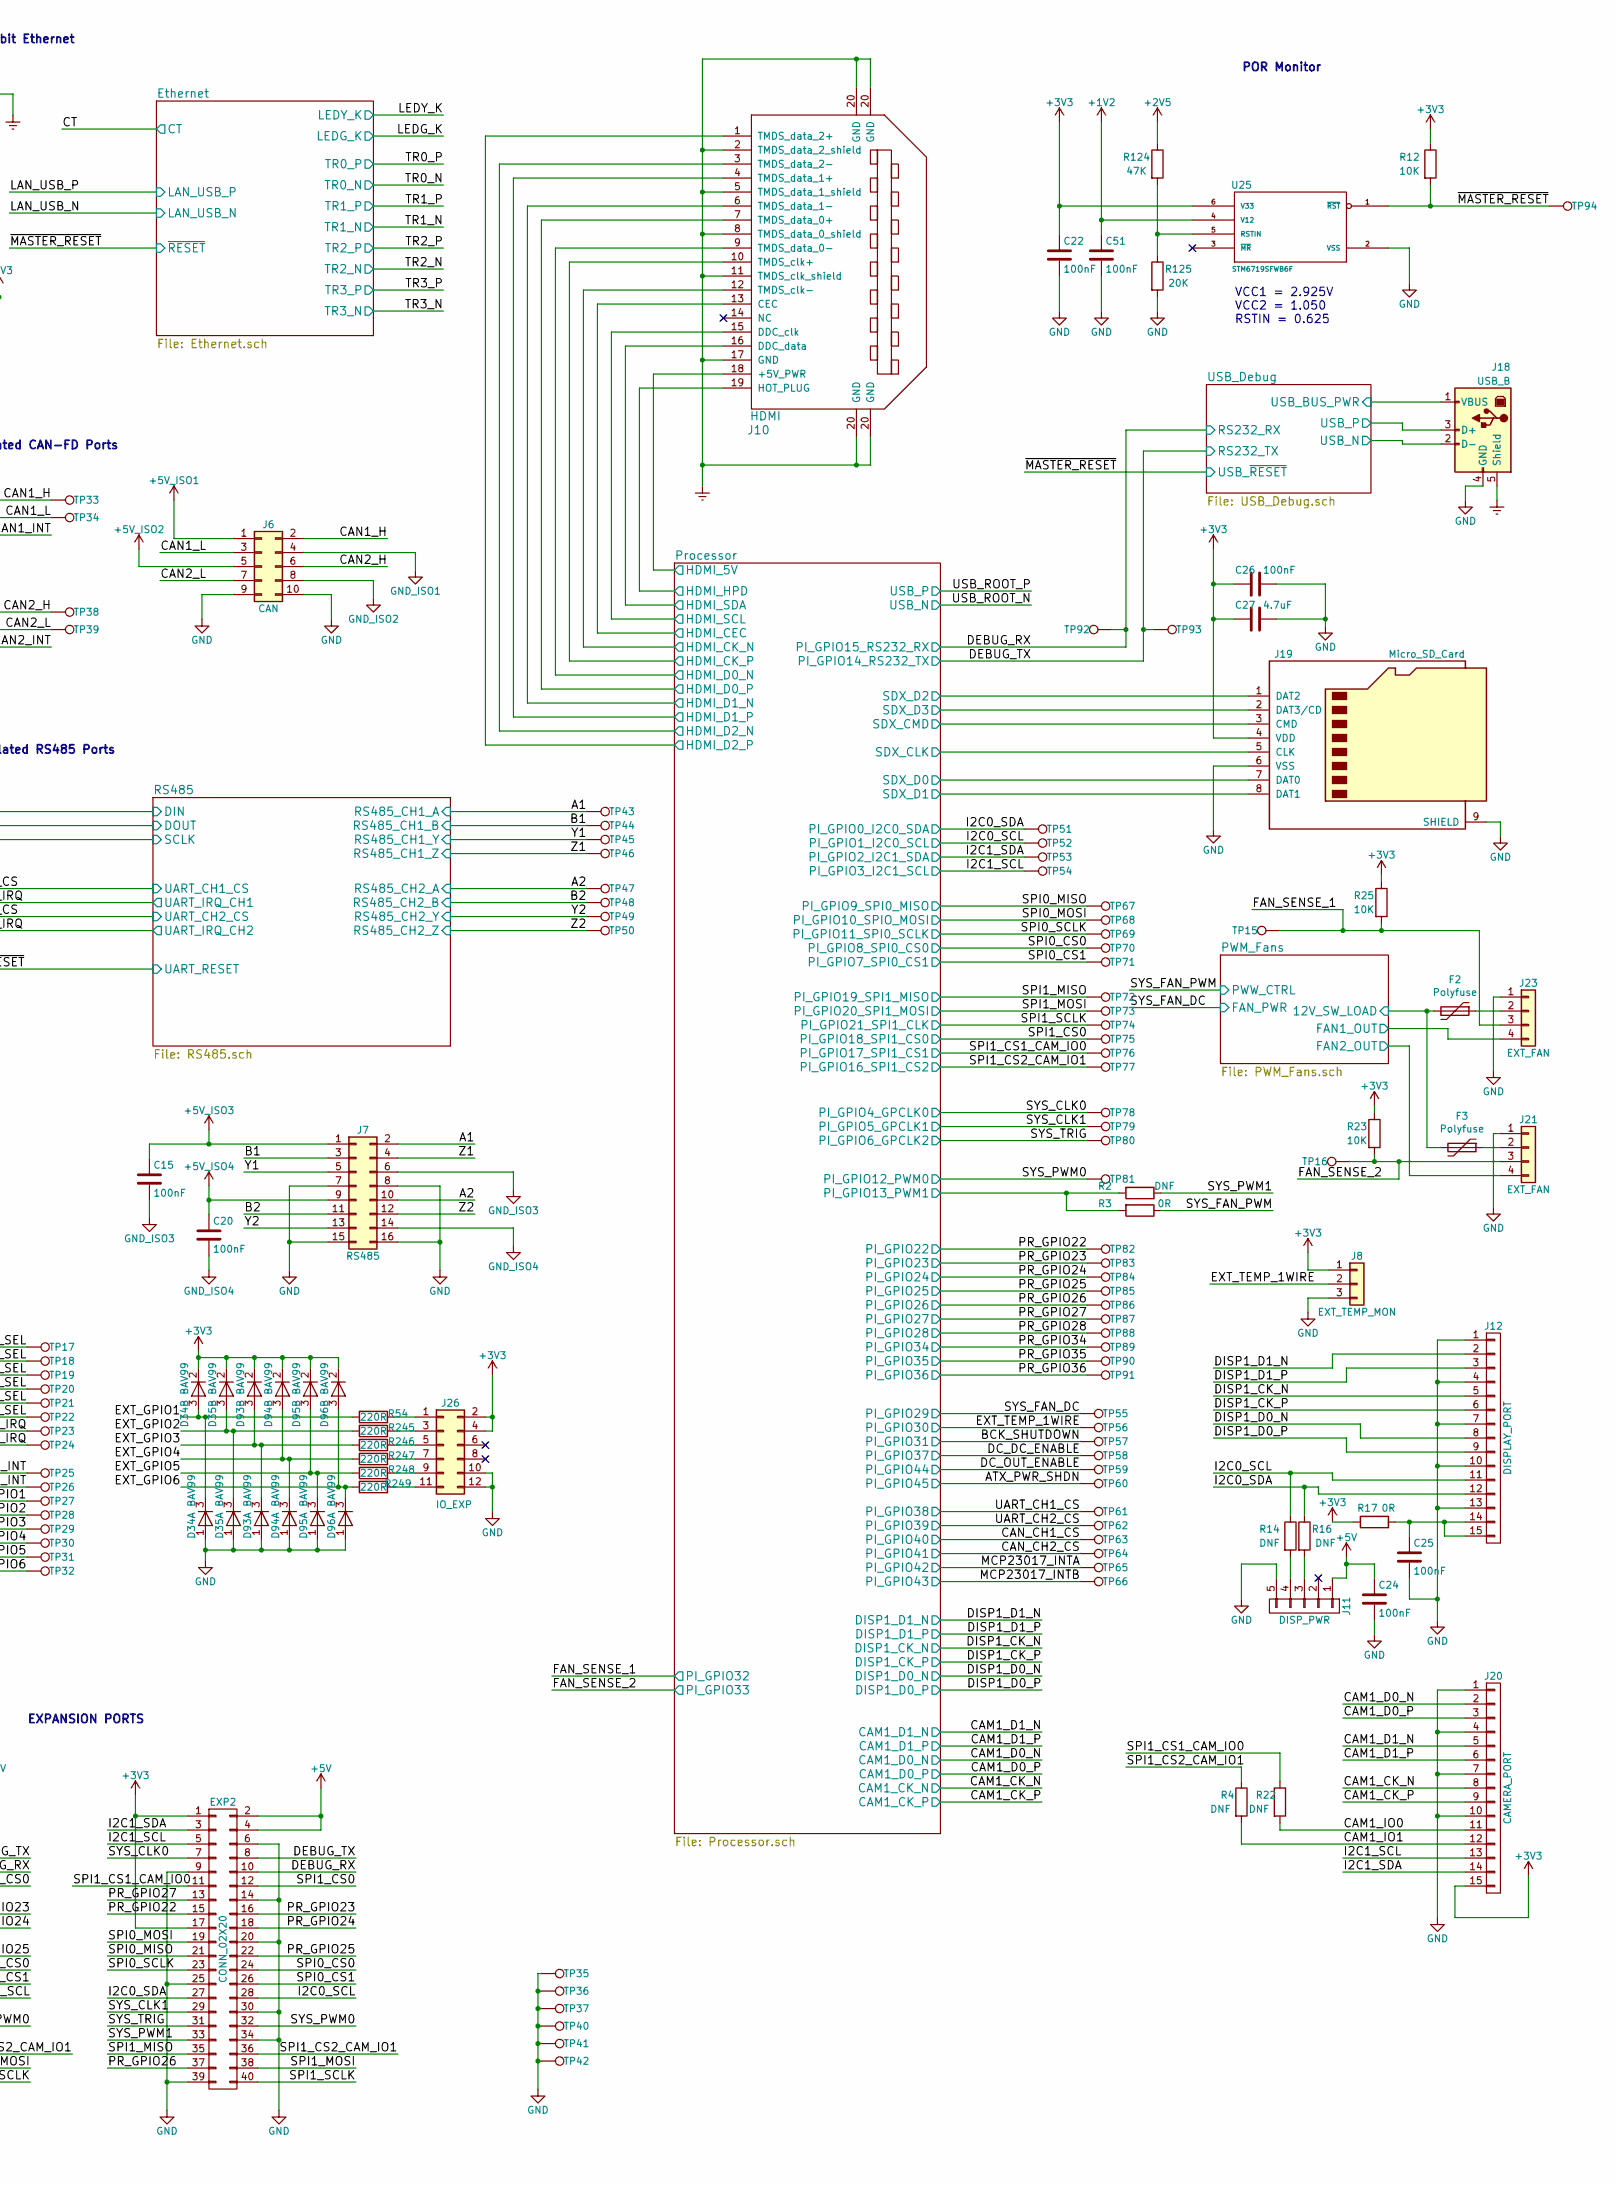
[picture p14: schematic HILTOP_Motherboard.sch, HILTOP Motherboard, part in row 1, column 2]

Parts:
C1: 100nF; C_1210_3225Metric
C2, C3, C7, C13, C18: 100uF; CP_Elec_6.3x7.7
C4, C6, C10, C119: 10uF; CP_Elec_6.3x5.3
C5, C8, C12, C14, C15, C17, C19, C20, C22, C24, C25, C26, C50, C75, C77, C121: 100nF; C_0603_1608Metric
C9, C11, C16, C120: 4.7uF; CP_Elec_5x5.3
C27: 4.7uF; C_0805_2012Metric
C51: 100nF; C_0402_1005Metric
C74: 1uF; C_0805_2012Metric
D1: GRN; LED_0402_1005Metric
D34, D35, D93, D94, D95, D96: BAV99; SOT-23
EXP1, EXP2: CONN_02X20; IDC-Header_2x20_P2.54mm_Vertical
F1: PPTC 3.8A; Fuse_Bourns_MF-RHT200
F2, F3: Polyfuse; Fuse_1206_3216Metric
J1: BACKPLANE_PWR; Molex_Mini-Fit_Jr_5566-08A_2x04_P4.20mm_Vertical
J2: ATX_MOLEX_02X12; Molex_MiniFit-JR-5556-24A_2x12x4.20mm_Straight
J3: SATA; SATA-7_THT_VERT_1
J4: USB_A_DOUBLE; USB_A_Double_Lumberg_2410_03
J5: USB FRONT PANEL; Molex_Picoflex_90325-0008_2x04_P1.27mm_Vertical
J6: CAN; Molex_Picoflex_90325-0010_2x05_P1.27mm_Vertical
J7: RS485; Molex_Picoflex_90325-0016_2x08_P1.27mm_Vertical
J8: EXT_TEMP_MON; Molex_KK-254_AE-6410-03A_1x03_P2.54mm_Vertical
J9: RJ45-TRANS_SI-61001-F; RJ45_TRANSFO_STEWART
J10: HDMI; FCI_10029449-11RLF
J11: DISP_PWR; Molex_KK-254_AE-6410-05A_1x05_P2.54mm_Vertical
J12: DISPLAY_PORT; DSI_FCC15W_VERT
J14: VADJ_B; Molex_MiniFit-JR-5556-02A_2x01x4.20mm_Straight
J15: VADJ_A; Molex_MiniFit-JR-5556-02A_2x01x4.20mm_Straight
J16: SOFT_START_PWR; Pin_Header_Straight_1x02_Pitch2.54mm
J17: PWR_LED; Pin_Header_Straight_1x02_Pitch2.54mm
J18: USB_B; USB_B_Horizontal
J19: Micro_SD_Card; uSD_MSDC-PP03
J20: CAMERA_PORT; DSI_FCC15W_VERT
J21, J23: EXT_FAN; Molex_KK-254_AE-6410-04A_1x04_P2.54mm_Vertical
J22: BACKPLANE_LV_PWR; Molex_Mini-Fit_Jr_5566-04A_2x02_P4.20mm_Vertical
J26: IO_EXP; IDC-Header_2x06_P2.54mm_Vertical
L1, L2, L3, L8: 22uH; Inductor_8x8
R1, R6: 1K; R_0603_1608Metric
R2, R4, R14, R16, R22, R24: DNF; R_0603_1608Metric
R3, R10, R11, R17, R18, R19: 0R; R_0603_1608Metric
R5, R7, R56: DNF; R_1206_3216Metric
R8: 590R; R_1206_3216Metric
R9: 120R; R_0603_1608Metric
R12, R23, R25, R119, R121: 10K; R_0603_1608Metric
R54, R245, R246, R247, R248, R249: 220R; R_0402_1005Metric
R83, R85: 330R; R_0603_1608Metric
R120: 4K7; R_0603_1608Metric
R122: 1K5; R_0603_1608Metric
R124: 47K; R_0603_1608Metric
R125: 20K; R_0603_1608Metric
R148: 330R; R_1210_3225Metric
R149, R150, R151: DNF; R_1210_3225Metric
TP8, TP9, TP10, TP11, TP12, TP13, TP14, TP15, TP16, TP17, TP18, TP19, TP20, TP21, TP22, TP23, TP24, TP25, TP26, TP27, TP28, TP29, TP30, TP31, TP32, TP33, TP34, TP35, TP36, TP37, TP38, TP39, TP40, TP41, TP42, TP43, TP44, TP45, TP46, TP47, TP48, TP49, TP50, TP51, TP52, TP53, TP54, TP55, TP56, TP57, TP58, TP59, TP60, TP61, TP62, TP63, TP64, TP65, TP66, TP67, TP68, TP69, TP70, TP71, TP72, TP73, TP74, TP75, TP76, TP77, TP78, TP79, TP80, TP81, TP82, TP83, TP84, TP85, TP86, TP87, TP88, TP89, TP90, TP91, TP92, TP93, TP94: TP; TestPoint_THTPad_D1.0mm_Drill0.5mm
U1: LM337BD2TG; TO-263-2
U25: STM6719SFWB6F; TSOT-23-6
U39: MCP23017; SSOP-28_5.3x10.2mm_P0.65mm

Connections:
+1V2: C51.1, J22.3, TP10.1, U25.4 (V12); also elsewhere on the board
+1V8: J22.2, TP9.1; also elsewhere on the board
+2V5: J22.1, R124.1, TP8.1; also elsewhere on the board
+2V5_LAN_A: J9.1; also elsewhere on the board
+3V3: C9.1, C12.1, C22.1, C26.2, C27.2, C77.2, D34.2 (K), D35.2 (K), D93.2 (K), D94.2 (K), D95.2 (K), D96.2 (K), EXP1.1, EXP1.17, EXP2.1, EXP2.17, J1.8, J8.1, J19.4 (VDD), J20.15, J26.2, J26.4, L1.2, R5.1, R7.1, R12.1, R17.2, R23.1, R24.1, R25.1, R56.1, R83.1, R85.1, TP11.1, U25.6 (V33), U39.9 (VCC); also elsewhere on the board
+5V: C11.1, C14.1, C24.1, EXP1.2, EXP1.4, EXP2.2, EXP2.4, J1.6, J5.8, J11.1, J17.1, L2.2, R119.1, TP14.1; also elsewhere on the board
+5V_ISO1: J6.1; also elsewhere on the board
+5V_ISO2: J6.5; also elsewhere on the board
+5V_ISO3: C15.1, J7.1; also elsewhere on the board
+5V_ISO4: C20.1, J7.9; also elsewhere on the board
+5V_STBY: J2.9 (5VSB); also elsewhere on the board
+12V: C16.1, C17.1, J1.5, L3.2, R121.1, TP12.1; also elsewhere on the board
-5V: C120.2, C121.2, J1.7, L8.2, TP13.1; also elsewhere on the board
/A1: J7.2, TP43.1; also elsewhere on the board
/A2: J7.10, TP47.1; also elsewhere on the board
/ATX_PWR_SHDN: TP60.1; also elsewhere on the board
/AdjPower/VADJ_DC: F1.2; also elsewhere on the board
/AdjPower/VMON_1: R119.2, R120.1; also elsewhere on the board
/AdjPower/VMON_2: R121.2, R122.1; also elsewhere on the board
/B1: J7.3, TP44.1; also elsewhere on the board
/B2: J7.11, TP48.1; also elsewhere on the board
/BCK_SHUTDOWN: TP57.1; also elsewhere on the board
/BoardPower/PSU_ON: J2.16 (PS_ON); also elsewhere on the board
/CAM1_CK_N: J20.8; also elsewhere on the board
/CAM1_CK_P: J20.9; also elsewhere on the board
/CAM1_D0_N: J20.2; also elsewhere on the board
/CAM1_D0_P: J20.3; also elsewhere on the board
/CAM1_D1_N: J20.5; also elsewhere on the board
/CAM1_D1_P: J20.6; also elsewhere on the board
/CAM1_IO0: J20.11, R22.2
/CAM1_IO1: J20.12, R4.2
/CAN1_H: J6.2, TP33.1; also elsewhere on the board
/CAN1_INT: TP25.1, U39.21 (GPA0); also elsewhere on the board
/CAN1_L: J6.3, TP34.1; also elsewhere on the board
/CAN2_H: J6.6, TP38.1; also elsewhere on the board
/CAN2_INT: TP26.1, U39.22 (GPA1); also elsewhere on the board
/CAN2_L: J6.7, TP39.1; also elsewhere on the board
/CAN_CH1_CS: TP63.1; also elsewhere on the board
/CAN_CH2_CS: TP64.1; also elsewhere on the board
/DC_DC_ENABLE: TP58.1; also elsewhere on the board
/DC_OUT_ENABLE: TP59.1; also elsewhere on the board
/DEBUG_RX: EXP1.10, EXP2.10, TP92.1; also elsewhere on the board
/DEBUG_TX: EXP1.8, EXP2.8, TP93.1; also elsewhere on the board
/DISP1_CK_N: J12.5; also elsewhere on the board
/DISP1_CK_P: J12.6; also elsewhere on the board
/DISP1_D0_N: J12.8; also elsewhere on the board
/DISP1_D0_P: J12.9; also elsewhere on the board
/DISP1_D1_N: J12.2; also elsewhere on the board
/DISP1_D1_P: J12.3; also elsewhere on the board
/EXT_GPIO1: D34.3 (K), R54.2, TP27.1, U39.23 (GPA2)
/EXT_GPIO2: D35.3 (K), R245.2, TP28.1, U39.24 (GPA3)
/EXT_GPIO3: D93.3 (K), R246.2, TP29.1, U39.25 (GPA4)
/EXT_GPIO4: D94.3 (K), R247.2, TP30.1, U39.26 (GPA5)
/EXT_GPIO5: D95.3 (K), R248.2, TP31.1, U39.27 (GPA6)
/EXT_GPIO6: D96.3 (K), R249.2, TP32.1, U39.28 (GPA7)
/EXT_TEMP_1WIRE: J8.2, TP56.1; also elsewhere on the board
/FAN_SENSE_1: J23.3, R25.2, TP15.1; also elsewhere on the board
/FAN_SENSE_2: J21.3, R23.2, TP16.1; also elsewhere on the board
/FR_PANEL_USB_N: J5.3; also elsewhere on the board
/FR_PANEL_USB_P: J5.2; also elsewhere on the board
/FR_PANEL_USB_PWR: C3.1, C5.1, J5.5, J5.6; also elsewhere on the board
/I2C0_SCL: EXP1.28, EXP2.28, J12.11, R14.1, TP52.1; also elsewhere on the board
/I2C0_SDA: EXP1.27, EXP2.27, J12.12, R16.1, TP51.1; also elsewhere on the board
/I2C1_SCL: EXP1.5, EXP2.5, J20.13, TP54.1, U39.12 (SCK); also elsewhere on the board
/I2C1_SDA: EXP1.3, EXP2.3, J20.14, TP53.1, U39.13 (SI); also elsewhere on the board
/LEDG_K: J9.14 (LEDG_K); also elsewhere on the board
/LEDY_K: J9.16 (LEDY_K); also elsewhere on the board
/MCP23017_INTA: TP65.1, U39.20 (INTA); also elsewhere on the board
/MCP23017_INTB: TP66.1, U39.19 (INTB); also elsewhere on the board
/PORT1_SEL: TP17.1, U39.1 (GPB0); also elsewhere on the board
/PORT2_SEL: TP18.1, U39.2 (GPB1); also elsewhere on the board
/PORT3_SEL: TP19.1, U39.3 (GPB2); also elsewhere on the board
/PORT4_SEL: TP20.1, U39.4 (GPB3); also elsewhere on the board
/PORT5_SEL: TP21.1, U39.5 (GPB4); also elsewhere on the board
/PORT6_SEL: TP22.1, U39.6 (GPB5); also elsewhere on the board
/PR_GPIO22: EXP1.15, EXP2.15, TP82.1; also elsewhere on the board
/PR_GPIO23: EXP1.16, EXP2.16, TP83.1; also elsewhere on the board
/PR_GPIO24: EXP1.18, EXP2.18, TP84.1; also elsewhere on the board
/PR_GPIO25: EXP1.22, EXP2.22, TP85.1; also elsewhere on the board
/PR_GPIO26: EXP1.37, EXP2.37, TP86.1; also elsewhere on the board
/PR_GPIO27: EXP1.13, EXP2.13, TP87.1; also elsewhere on the board
/PR_GPIO28: TP88.1; also elsewhere on the board
/PR_GPIO34: TP89.1; also elsewhere on the board
/PR_GPIO35: TP90.1; also elsewhere on the board
/PR_GPIO36: TP91.1; also elsewhere on the board
/PWM_Fans/12V_SW_LOAD: F2.2, F3.2; also elsewhere on the board
/PWM_Fans/FAN1_OUT: J23.4; also elsewhere on the board
/PWM_Fans/FAN2_OUT: J21.4; also elsewhere on the board
/PWR_SW: J5.7, J16.2; also elsewhere on the board
/Processor/HDMI_5V: J10.18 (+5V_PWR); also elsewhere on the board
/Processor/HDMI_CEC: J10.13 (CEC); also elsewhere on the board
/Processor/HDMI_CK_N: J10.12 (TMDS_clk-); also elsewhere on the board
/Processor/HDMI_CK_P: J10.10 (TMDS_clk+); also elsewhere on the board
/Processor/HDMI_D0_N: J10.9 (TMDS_data_0-); also elsewhere on the board
/Processor/HDMI_D0_P: J10.7 (TMDS_data_0+); also elsewhere on the board
/Processor/HDMI_D1_N: J10.6 (TMDS_data_1-); also elsewhere on the board
/Processor/HDMI_D1_P: J10.4 (TMDS_data_1+); also elsewhere on the board
/Processor/HDMI_D2_N: J10.3 (TMDS_data_2-); also elsewhere on the board
/Processor/HDMI_D2_P: J10.1 (TMDS_data_2+); also elsewhere on the board
/Processor/HDMI_HPD: J10.19 (HOT_PLUG); also elsewhere on the board
/Processor/HDMI_SCL: J10.15 (DDC_clk); also elsewhere on the board
/Processor/HDMI_SDA: J10.16 (DDC_data); also elsewhere on the board
/Processor/PI_GPIO13_PWM1: R2.2, R3.2; also elsewhere on the board
/Processor/SDX_CLK: J19.5 (CLK); also elsewhere on the board
/Processor/SDX_CMD: J19.3 (CMD); also elsewhere on the board
/Processor/SDX_D0: J19.7 (DAT0); also elsewhere on the board
/Processor/SDX_D1: J19.8 (DAT1); also elsewhere on the board
/Processor/SDX_D2: J19.1 (DAT2); also elsewhere on the board
/Processor/SDX_D3: J19.2 (DAT3/CD); also elsewhere on the board
/SATA_Bridge/CAP_SATARX_N: J3.5; also elsewhere on the board
/SATA_Bridge/CAP_SATARX_P: J3.6; also elsewhere on the board
/SATA_Bridge/CAP_SATATX_N: J3.3; also elsewhere on the board
/SATA_Bridge/CAP_SATATX_P: J3.2; also elsewhere on the board
/SPI0_CS0: EXP1.24, EXP2.24, TP70.1; also elsewhere on the board
/SPI0_CS1: EXP1.26, EXP2.26, TP71.1; also elsewhere on the board
/SPI0_MISO: EXP1.21, EXP2.21, TP67.1; also elsewhere on the board
/SPI0_MOSI: EXP1.19, EXP2.19, TP68.1; also elsewhere on the board
/SPI0_SCLK: EXP1.23, EXP2.23, TP69.1; also elsewhere on the board
/SPI1_CS0: EXP1.12, EXP2.12, TP75.1; also elsewhere on the board
/SPI1_CS1_CAM_IO0: EXP1.11, EXP2.11, R22.1, TP76.1; also elsewhere on the board
/SPI1_CS2_CAM_IO1: EXP1.36, EXP2.36, R4.1, TP77.1; also elsewhere on the board
/SPI1_MISO: EXP1.35, EXP2.35, TP72.1; also elsewhere on the board
/SPI1_MOSI: EXP1.38, EXP2.38, TP73.1; also elsewhere on the board
/SPI1_SCLK: EXP1.40, EXP2.40, TP74.1; also elsewhere on the board
/SYS_CLK0: EXP1.7, EXP2.7, TP78.1; also elsewhere on the board
/SYS_CLK1: EXP1.29, EXP2.29, TP79.1; also elsewhere on the board
/SYS_FAN_DC: TP55.1; also elsewhere on the board
/SYS_FAN_PWM: R3.1; also elsewhere on the board
/SYS_PWM0: EXP1.32, EXP2.32, TP81.1; also elsewhere on the board
/SYS_PWM1: EXP1.33, EXP2.33, R2.1; also elsewhere on the board
/SYS_TRIG: EXP1.31, EXP2.31, TP80.1; also elsewhere on the board
/TR0_N: J9.3; also elsewhere on the board
/TR0_P: J9.2; also elsewhere on the board
/TR1_N: J9.5; also elsewhere on the board
/TR1_P: J9.4; also elsewhere on the board
/TR2_N: J9.7; also elsewhere on the board
/TR2_P: J9.6; also elsewhere on the board
/TR3_N: J9.9; also elsewhere on the board
/TR3_P: J9.8; also elsewhere on the board
/UART_CH1_CS: TP61.1; also elsewhere on the board
/UART_CH1_IRQ: TP23.1, U39.7 (GPB6); also elsewhere on the board
/UART_CH2_CS: TP62.1; also elsewhere on the board
/UART_CH2_IRQ: TP24.1, U39.8 (GPB7); also elsewhere on the board
/USBHub/PWR1_5V: C2.1, C7.1, C8.1, J4.1 (VBUS1); also elsewhere on the board
/USBHub/PWR2_5V: C13.1, C18.1, C19.1, J4.5 (VBUS2); also elsewhere on the board
/USBHub/USB1_N: J4.2 (D1-); also elsewhere on the board
/USBHub/USB1_P: J4.3 (D1+); also elsewhere on the board
/USBHub/USB2_N: J4.6 (D2-); also elsewhere on the board
/USBHub/USB2_P: J4.7 (D2+); also elsewhere on the board
/USB_Debug/USB_BUS_PWR: J18.1 (VBUS); also elsewhere on the board
/USB_Debug/USB_N: J18.2 (D-); also elsewhere on the board
/USB_Debug/USB_P: J18.3 (D+); also elsewhere on the board
/Y1: J7.5, TP45.1; also elsewhere on the board
/Y2: J7.13, TP49.1; also elsewhere on the board
/Z1: J7.4, TP46.1; also elsewhere on the board
/Z2: J7.12, TP50.1; also elsewhere on the board
/~MASTER_RESET: R10.2, R12.2, TP94.1, U25.1 (~RST); also elsewhere on the board
ADJ_DC: F1.1, J14.1, J15.1
Earth: C1.2, J4.9 (shield), J9.10, J9.11 (SHIELD), J9.12 (SHIELD), J10.2 (TMDS_data_2_shield), J10.5 (TMDS_data_1_shield), J10.8 (TMDS_data_0_shield), J10.11 (TMDS_clk_shield), J10.17 (GND), J10.20 (GND), J18.5 (Shield), R148.2, R149.2, R150.2, R151.2
GND: C1.1, C2.2, C3.2, C4.2, C5.2, C6.2, C7.2, C8.2, C9.2, C10.2, C11.2, C12.2, C13.2, C14.2, C16.2, C17.2, C18.2, C19.2, C22.2, C24.2, C25.2, C26.1, C27.1, C50.1, C51.2, C74.1, C75.1, C77.1, C119.1, C120.1, C121.1, D34.1 (A), D35.1 (A), D93.1 (A), D94.1 (A), D95.1 (A), D96.1 (A), EXP1.6, EXP1.9, EXP1.14, EXP1.20, EXP1.25, EXP1.30, EXP1.34, EXP1.39, EXP2.6, EXP2.9, EXP2.14, EXP2.20, EXP2.25, EXP2.30, EXP2.34, EXP2.39, J1.1, J1.2, J1.3, J1.4, J2.3 (GND), J2.5 (GND), J2.7 (GND), J2.15 (GND), J2.17 (GND), J2.18 (GND), J2.19 (GND), J2.24 (GND), J3.1, J3.4, J3.7, J4.4 (GND), J4.8 (GND), J5.1, J5.4, J6.9, J6.10, J7.7, J7.8, J7.15, J7.16, J8.3, J11.5, J12.1, J12.4, J12.7, J12.10, J12.13, J14.2, J15.2, J16.1, J18.4 (GND), J19.6 (VSS), J19.9 (SHIELD), J20.1, J20.4, J20.7, J20.10, J21.1, J22.4, J23.1, J26.10, J26.12, R1.2, R5.2, R6.2, R7.2, R8.1, R11.2, R18.2, R19.2, R56.2, R120.2, R122.2, R125.2, R148.1, R149.1, R150.1, R151.1, TP35.1, TP36.1, TP37.1, TP40.1, TP41.1, TP42.1, U25.2 (VSS), U39.10 (GND); also elsewhere on the board
GND_ISO1: J6.4; also elsewhere on the board
GND_ISO2: J6.8; also elsewhere on the board
GND_ISO3: C15.2, J7.6; also elsewhere on the board
GND_ISO4: C20.2, J7.14; also elsewhere on the board
unnamed: C4.1, J2.1 (+3V3), J2.2 (+3V3), J2.12 (+3.3V), J2.13 (+3V3), L1.1
unnamed: C6.1, J2.4 (+5V), J2.6 (+5V), J2.21 (+5V), J2.22 (+5V), J2.23 (+5V), L2.1
unnamed: C10.1, J2.10 (+12V), J2.11 (+12V), L3.1
unnamed: C25.1, J12.14, J12.15, R17.1
unnamed: C50.2, C74.2, J2.14 (-12V), U1.2 (VI)
unnamed: C75.2, C119.2, L8.1, R9.1, U1.3 (VO)
unnamed: D1.1 (K), R1.1
unnamed: D1.2 (A), J2.8 (PS_OK)
unnamed: F2.1, J23.2
unnamed: F3.1, J21.2
unnamed: J9.13 (LEDG_A), R83.2
unnamed: J9.15 (LEDY_A), R85.2
unnamed: J11.3, R16.2
unnamed: J11.4, R14.2
unnamed: J17.2, R6.1
unnamed: J26.1, R54.1
unnamed: J26.3, R245.1
unnamed: J26.5, R246.1
unnamed: J26.7, R247.1
unnamed: J26.9, R248.1
unnamed: J26.11, R249.1
unnamed: R8.2, R9.2, U1.1 (ADJ)
unnamed: R10.1, R24.2, U39.18 (~RESET)
unnamed: R11.1, U39.15 (A0)
unnamed: R18.1, U39.16 (A1)
unnamed: R19.1, U39.17 (A2)
unnamed: R124.2, R125.1, U25.5 (RSTIN)

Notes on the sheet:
*LOAD RESISTORS - REQ'D FOR SOME ATX PSU's
EXPANSION PORTS
VCC1 = 2.925V VCC2 = 1.050 RSTIN = 0.625
DIGITAL GROUND to CHASSIS GROUND 0R Links to be placed close to each Mounting hole
Isolated RS485 Ports
Isolated CAN-FD Ports
Gigabit Ethernet
USB 2.0 Ports for External Periphals (Protected)
POR Monitor
Front Panel - PWR Sw. & Indication

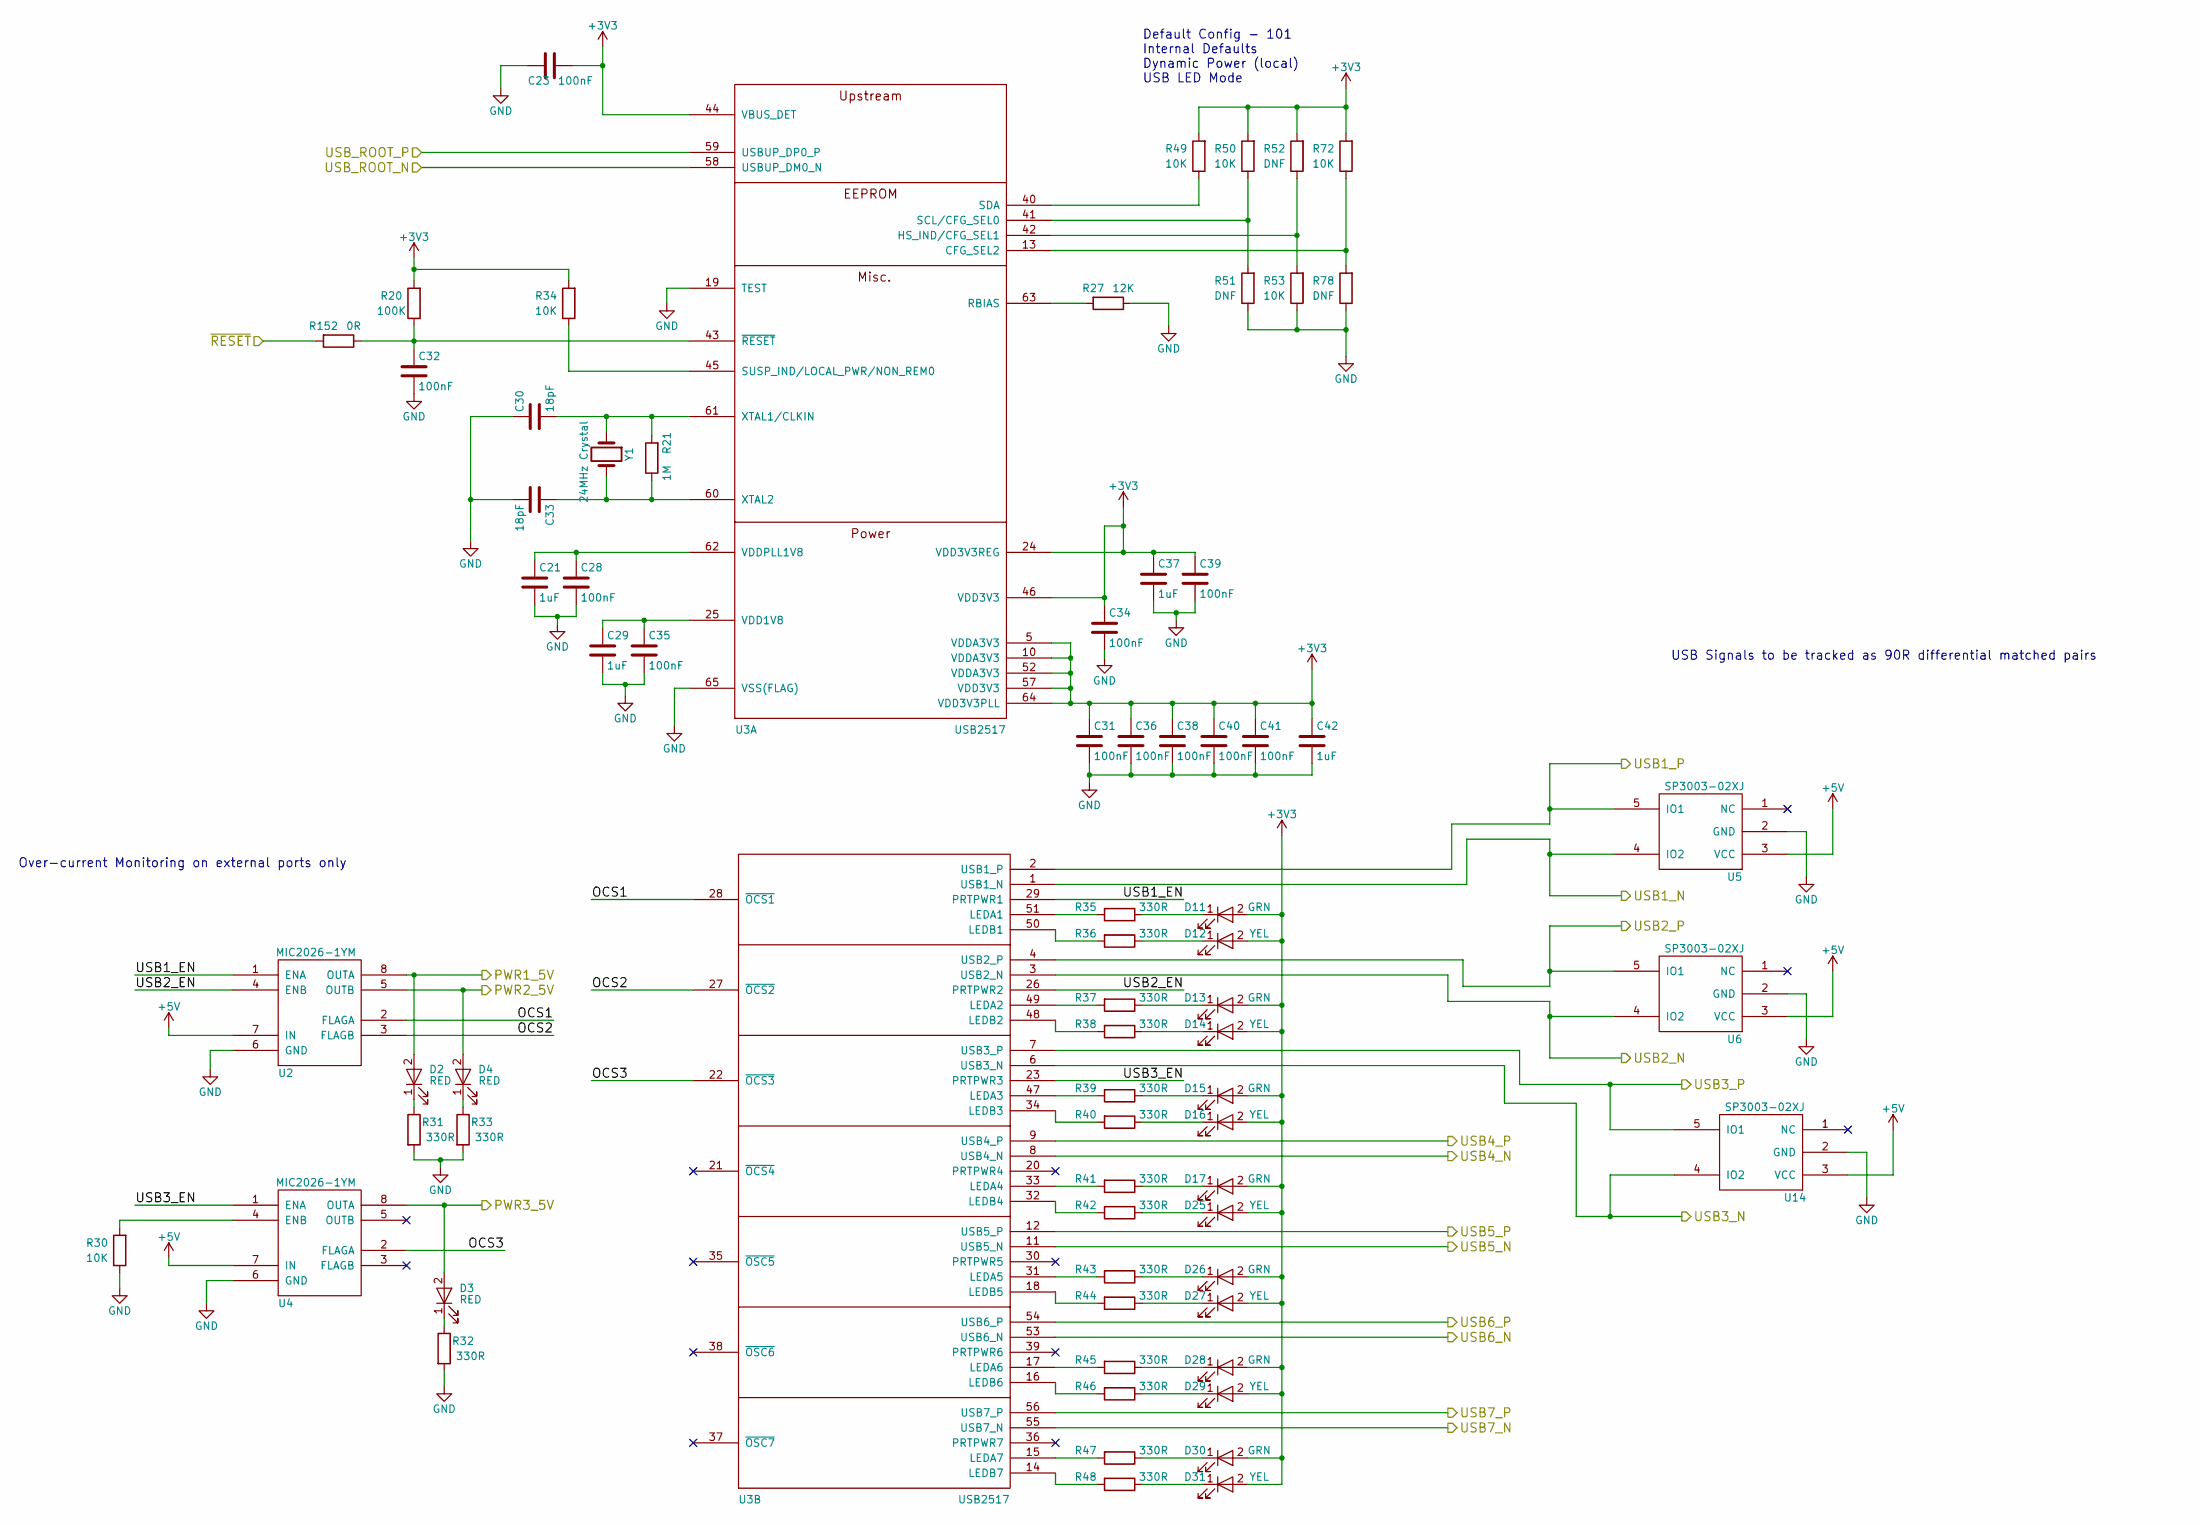
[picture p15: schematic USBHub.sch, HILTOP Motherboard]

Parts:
C21, C29, C37, C42: 1uF; C_0603_1608Metric
C23: 100nF; C_0603_1608Metric
C28: 100nF; C_0201_0603Metric
C30, C33: 18pF; C_0402_1005Metric
C31, C32, C34, C35, C36, C38, C39, C40, C41: 100nF; C_0402_1005Metric
D2, D3, D4: RED; LED_0402_1005Metric
D11, D13, D15, D17, D26, D28, D30: GRN; LED_0402_1005Metric
D12, D14, D16, D25, D27, D29, D31: YEL; LED_0402_1005Metric
R20: 100K; R_0603_1608Metric
R21: 1M; R_0603_1608Metric
R27: 12K; R_0603_1608Metric
R30, R34, R49, R50, R53, R72: 10K; R_0402_1005Metric
R31, R32, R33, R35, R36, R37, R38, R39, R40, R41, R42, R43, R44, R45, R46, R47, R48: 330R; R_0402_1005Metric
R51, R52, R78: DNF; R_0402_1005Metric
R152: 0R; R_0603_1608Metric
U2, U4: MIC2026-1YM; SOIC-8_3.9x4.9mm_P1.27mm
U3: USB2517; QFN-64-1EP_9x9mm_P0.5mm_EP4.7x4.7mm
U5, U6, U14: SP3003-02XJ; SC70-5
Y1: 24MHz Crystal; Crystal_SMD_7050-2Pin_7.0x5.0mm

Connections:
+3V3: C23.1, C31.1, C34.1, C36.1, C37.1, C38.1, C39.1, C40.1, C41.1, C42.1, D11.2 (A), D12.2 (A), D13.2 (A), D14.2 (A), D15.2 (A), D16.2 (A), D17.2 (A), D25.2 (A), D26.2 (A), D27.2 (A), D28.2 (A), D29.2 (A), D30.2 (A), D31.2 (A), R20.2, R34.2, R49.2, R50.2, R52.2, R72.2, U3.5 (VDDA3V3), U3.10 (VDDA3V3), U3.24 (VDD3V3REG), U3.44 (VBUS_DET), U3.46 (VDD3V3), U3.52 (VDDA3V3), U3.57 (VDD3V3), U3.64 (VDD3V3PLL); also elsewhere on the board
+5V: U2.7 (IN), U4.7 (IN), U5.3 (VCC), U6.3 (VCC), U14.3 (VCC); also elsewhere on the board
/BACKPLANE_USB_N: U3.55 (USB7_N); also elsewhere on the board
/BACKPLANE_USB_P: U3.56 (USB7_P); also elsewhere on the board
/FR_PANEL_USB_N: U3.6 (USB3_N), U14.4 (IO2); also elsewhere on the board
/FR_PANEL_USB_P: U3.7 (USB3_P), U14.5 (IO1); also elsewhere on the board
/FR_PANEL_USB_PWR: D3.2 (A), U4.8 (OUTA); also elsewhere on the board
/LAN_USB_N: U3.8 (USB4_N); also elsewhere on the board
/LAN_USB_P: U3.9 (USB4_P); also elsewhere on the board
/SATA_USB_N: U3.11 (USB5_N); also elsewhere on the board
/SATA_USB_P: U3.12 (USB5_P); also elsewhere on the board
/USBHub/OCS1: U2.2 (FLAGA), U3.28 (~OCS1)
/USBHub/OCS2: U2.3 (FLAGB), U3.27 (~OCS2)
/USBHub/OCS3: U3.22 (~OCS3), U4.2 (FLAGA)
/USBHub/PWR1_5V: D2.2 (A), U2.8 (OUTA); also elsewhere on the board
/USBHub/PWR2_5V: D4.2 (A), U2.5 (OUTB); also elsewhere on the board
/USBHub/USB1_EN: U2.1 (ENA), U3.29 (PRTPWR1)
/USBHub/USB1_N: U3.1 (USB1_N), U5.4 (IO2); also elsewhere on the board
/USBHub/USB1_P: U3.2 (USB1_P), U5.5 (IO1); also elsewhere on the board
/USBHub/USB2_EN: U2.4 (ENB), U3.26 (PRTPWR2)
/USBHub/USB2_N: U3.3 (USB2_N), U6.4 (IO2); also elsewhere on the board
/USBHub/USB2_P: U3.4 (USB2_P), U6.5 (IO1); also elsewhere on the board
/USBHub/USB3_EN: U3.23 (PRTPWR3), U4.1 (ENA)
/USB_ROOT_N: U3.58 (USBUP_DM0_N); also elsewhere on the board
/USB_ROOT_P: U3.59 (USBUP_DP0_P); also elsewhere on the board
/~MASTER_RESET: R152.2; also elsewhere on the board
GND: C21.2, C23.2, C28.2, C29.2, C30.1, C31.2, C32.2, C33.2, C34.2, C35.2, C36.2, C37.2, C38.2, C39.2, C40.2, C41.2, C42.2, R27.1, R30.1, R31.2, R32.2, R33.2, R51.1, R53.1, R78.1, U2.6 (GND), U3.19 (TEST), U3.65 (VSS(FLAG)), U4.6 (GND), U5.2 (GND), U6.2 (GND), U14.2 (GND); also elsewhere on the board
unnamed: C21.1, C28.1, U3.62 (VDDPLL1V8)
unnamed: C29.1, C35.1, U3.25 (VDD1V8)
unnamed: C30.2, R21.2, U3.61 (XTAL1/CLKIN), Y1.1
unnamed: C32.1, R20.1, R152.1, U3.43 (~RESET)
unnamed: C33.1, R21.1, U3.60 (XTAL2), Y1.2
unnamed: D2.1 (K), R31.1
unnamed: D3.1 (K), R32.1
unnamed: D4.1 (K), R33.1
unnamed: D11.1 (K), R35.1
unnamed: D12.1 (K), R36.1
unnamed: D13.1 (K), R37.1
unnamed: D14.1 (K), R38.1
unnamed: D15.1 (K), R39.1
unnamed: D16.1 (K), R40.1
unnamed: D17.1 (K), R41.1
unnamed: D25.1 (K), R42.1
unnamed: D26.1 (K), R43.1
unnamed: D27.1 (K), R44.1
unnamed: D28.1 (K), R45.1
unnamed: D29.1 (K), R46.1
unnamed: D30.1 (K), R47.1
unnamed: D31.1 (K), R48.1
unnamed: R27.2, U3.63 (RBIAS)
unnamed: R30.2, U4.4 (ENB)
unnamed: R34.1, U3.45 (SUSP_IND/LOCAL_PWR/NON_REM0)
unnamed: R35.2, U3.51 (LEDA1)
unnamed: R36.2, U3.50 (LEDB1)
unnamed: R37.2, U3.49 (LEDA2)
unnamed: R38.2, U3.48 (LEDB2)
unnamed: R39.2, U3.47 (LEDA3)
unnamed: R40.2, U3.34 (LEDB3)
unnamed: R41.2, U3.33 (LEDA4)
unnamed: R42.2, U3.32 (LEDB4)
unnamed: R43.2, U3.31 (LEDA5)
unnamed: R44.2, U3.18 (LEDB5)
unnamed: R45.2, U3.17 (LEDA6)
unnamed: R46.2, U3.16 (LEDB6)
unnamed: R47.2, U3.15 (LEDA7)
unnamed: R48.2, U3.14 (LEDB7)
unnamed: R49.1, U3.40 (SDA)
unnamed: R50.1, R51.2, U3.41 (SCL/CFG_SEL0)
unnamed: R52.1, R53.2, U3.42 (HS_IND/CFG_SEL1)
unnamed: R72.1, R78.2, U3.13 (CFG_SEL2)

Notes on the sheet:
Default Config - 101 Internal Defaults Dynamic Power (local) USB LED Mode
Over-current Monitoring on external ports only
USB Signals to be tracked as 90R differential matched pairs

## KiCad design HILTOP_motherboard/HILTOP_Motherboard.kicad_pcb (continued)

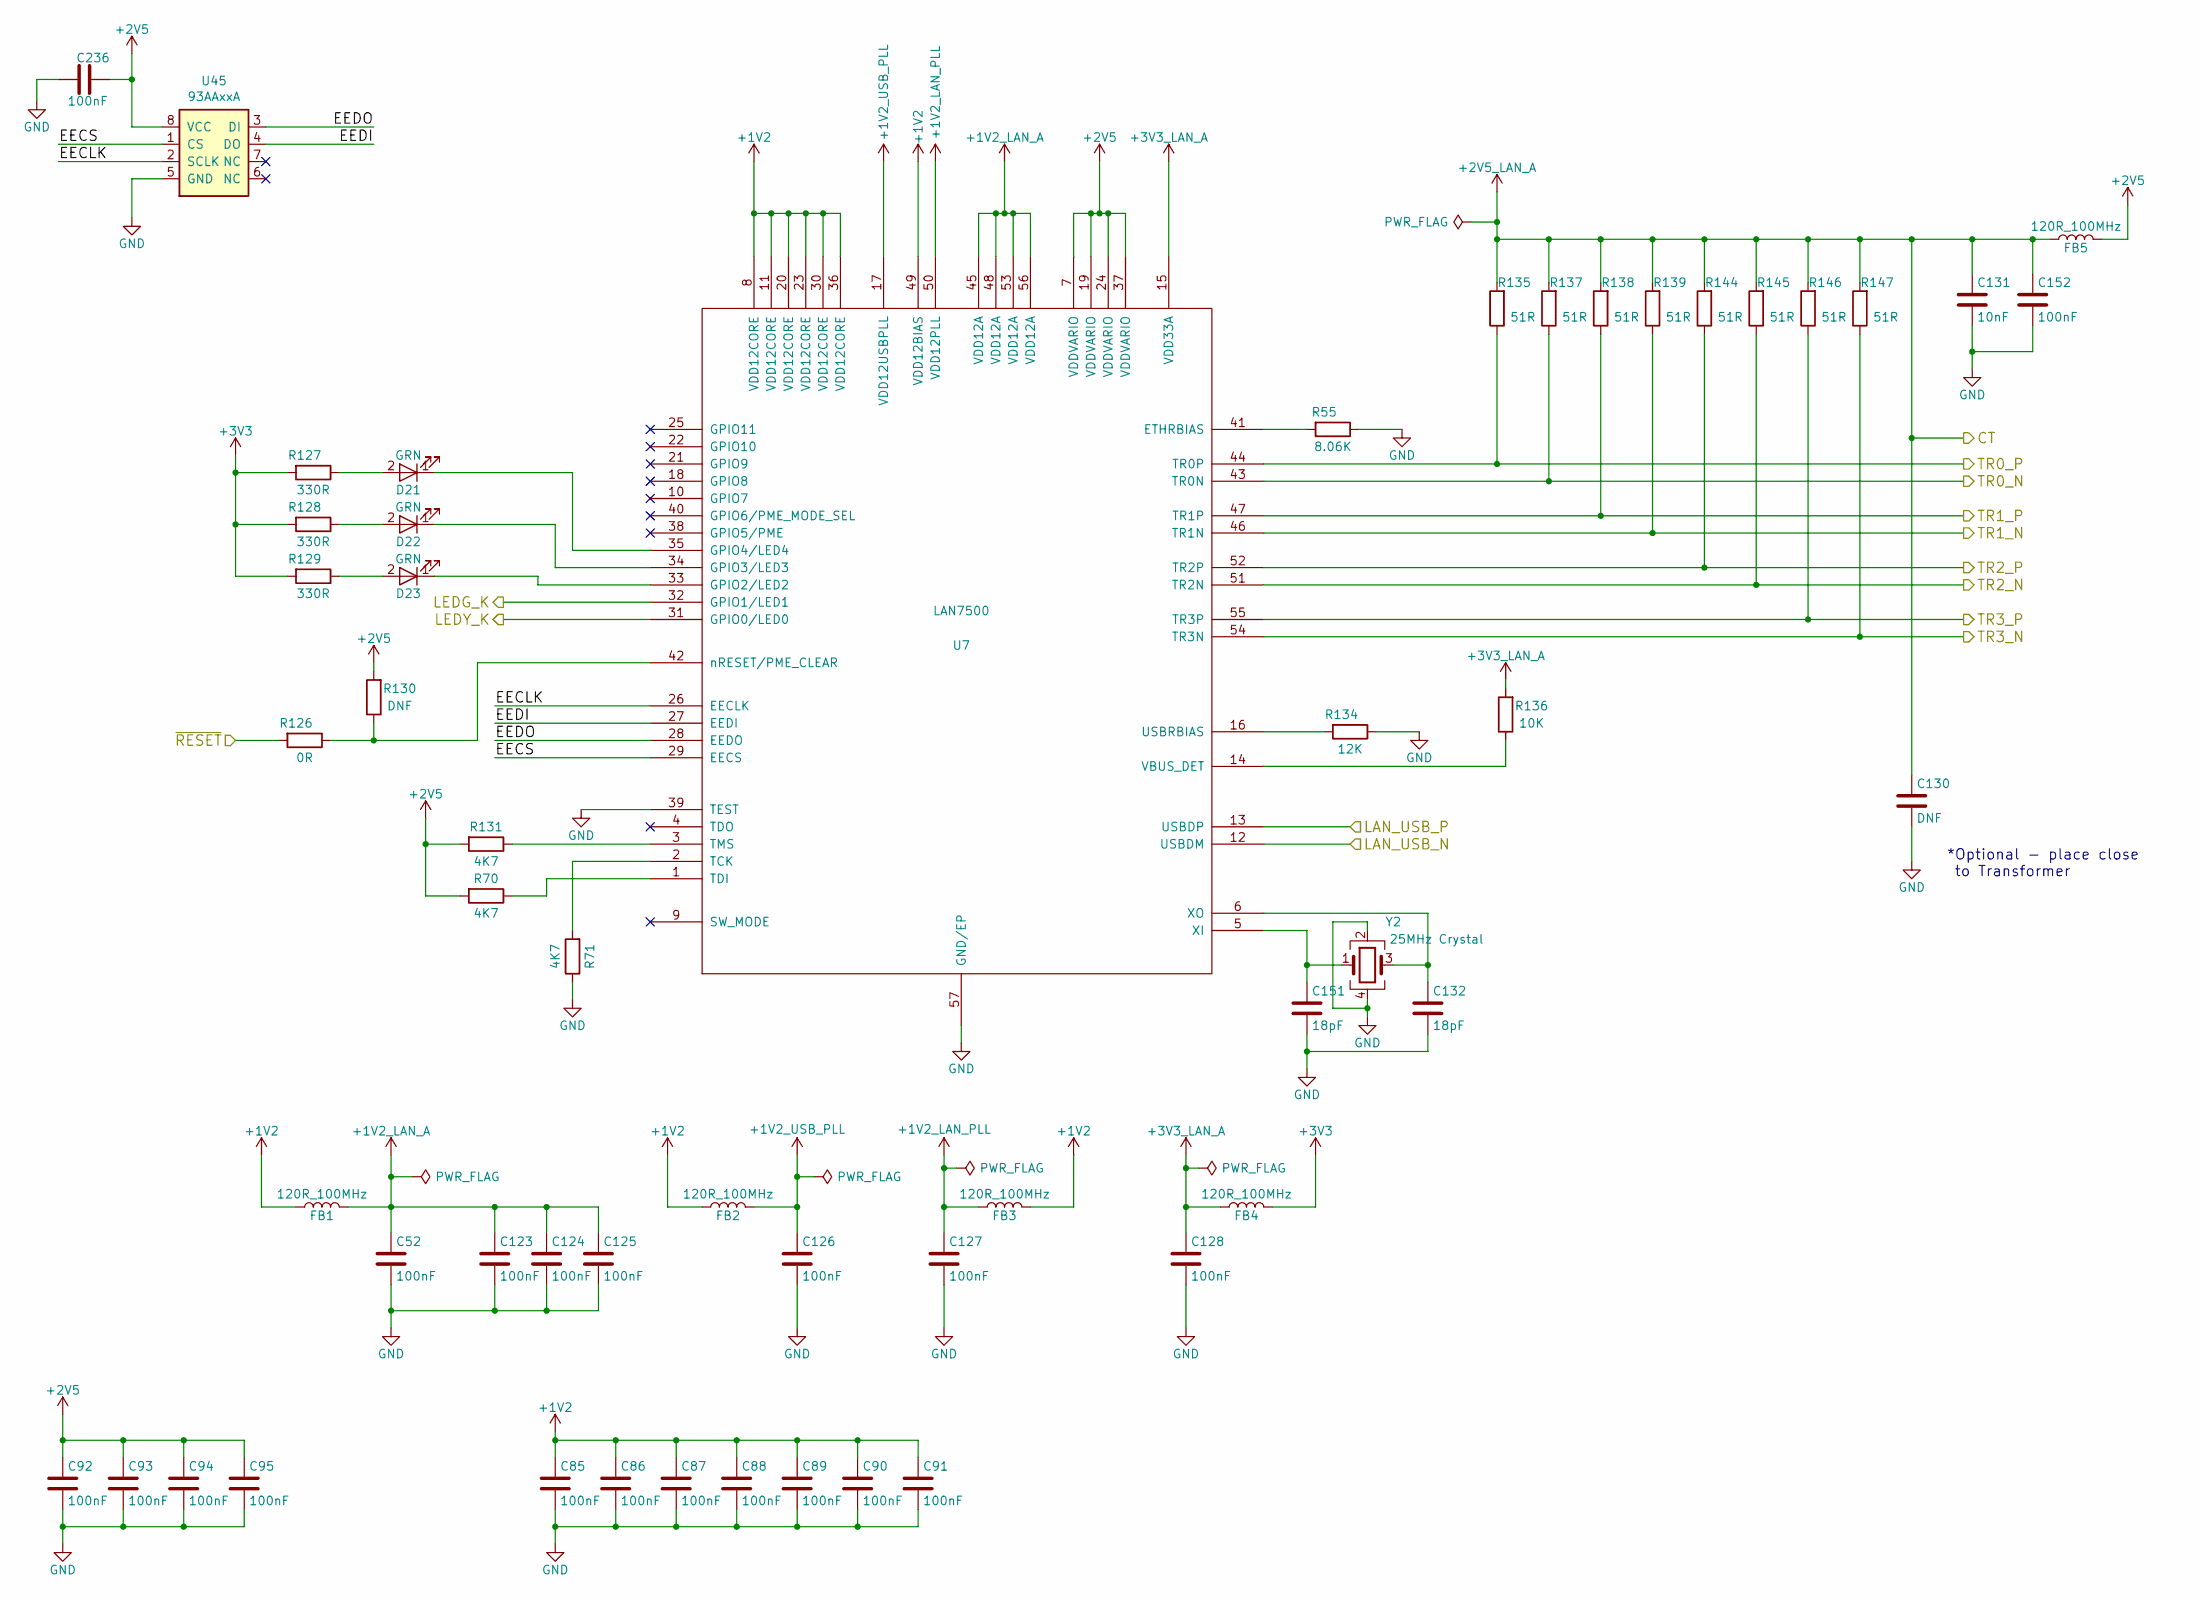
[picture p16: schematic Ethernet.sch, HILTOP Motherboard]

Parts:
C52: 100nF; C_0402_1005Metric
C85, C86, C87, C88, C89, C90, C91, C92, C93, C94, C95, C123, C124, C125, C126, C127, C128, C152, C236: 100nF; C_0603_1608Metric
C130: DNF; C_0603_1608Metric
C131: 10nF; C_0603_1608Metric
C132, C151: 18pF; C_0402_1005Metric
D21, D22, D23: GRN; LED_0402_1005Metric
FB1, FB2, FB3, FB4, FB5: 120R_100MHz; R_0603_1608Metric
R55: 8.06K; R_0603_1608Metric
R70, R71, R131: 4K7; R_0603_1608Metric
R126: 0R; R_0603_1608Metric
R127, R128, R129: 330R; R_0603_1608Metric
R130: DNF; R_0603_1608Metric
R134: 12K; R_0603_1608Metric
R135, R137, R138, R139, R144, R145, R146, R147: 51R; R_0603_1608Metric
R136: 10K; R_0603_1608Metric
U7: LAN7500; QFN-56_8x8mm_Pitch0.5mm
U45: 93AAxxA; SOIC-8_3.9x4.9mm_P1.27mm
Y2: 25MHz Crystal; Crystal_SMD_SeikoEpson_FA238V-4Pin_3.2x2.5mm

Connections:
+1V2: C85.1, C86.1, C87.1, C88.1, C89.1, C90.1, C91.1, FB1.1, FB2.1, FB3.2, U7.8 (VDD12CORE), U7.11 (VDD12CORE), U7.20 (VDD12CORE), U7.23 (VDD12CORE), U7.30 (VDD12CORE), U7.36 (VDD12CORE), U7.49 (VDD12BIAS); also elsewhere on the board
+1V2_LAN_A: C52.1, C123.1, C124.1, C125.1, FB1.2, U7.45 (VDD12A), U7.48 (VDD12A), U7.53 (VDD12A), U7.56 (VDD12A)
+1V2_LAN_PLL: C127.1, FB3.1, U7.50 (VDD12PLL)
+1V2_USB_PLL: C126.1, FB2.2, U7.17 (VDD12USBPLL)
+2V5: C92.1, C93.1, C94.1, C95.1, C236.1, FB5.2, R70.2, R130.2, R131.2, U7.7 (VDDVARIO), U7.19 (VDDVARIO), U7.24 (VDDVARIO), U7.37 (VDDVARIO), U45.8 (VCC); also elsewhere on the board
+2V5_LAN_A: C130.1, C131.1, C152.1, FB5.1, R135.2, R137.2, R138.2, R139.2, R144.2, R145.2, R146.2, R147.2; also elsewhere on the board
+3V3: FB4.2, R127.2, R128.2, R129.2; also elsewhere on the board
+3V3_LAN_A: C128.1, FB4.1, R136.2, U7.15 (VDD33A)
/Ethernet/EECLK: U7.26 (EECLK), U45.2 (SCLK)
/Ethernet/EECS: U7.29 (EECS), U45.1 (CS)
/Ethernet/EEDI: U7.27 (EEDI), U45.4 (DO)
/Ethernet/EEDO: U7.28 (EEDO), U45.3 (DI)
/LAN_USB_N: U7.12 (USBDM); also elsewhere on the board
/LAN_USB_P: U7.13 (USBDP); also elsewhere on the board
/LEDG_K: U7.32 (GPIO1/LED1); also elsewhere on the board
/LEDY_K: U7.31 (GPIO0/LED0); also elsewhere on the board
/TR0_N: R137.1, U7.43 (TR0N); also elsewhere on the board
/TR0_P: R135.1, U7.44 (TR0P); also elsewhere on the board
/TR1_N: R139.1, U7.46 (TR1N); also elsewhere on the board
/TR1_P: R138.1, U7.47 (TR1P); also elsewhere on the board
/TR2_N: R145.1, U7.51 (TR2N); also elsewhere on the board
/TR2_P: R144.1, U7.52 (TR2P); also elsewhere on the board
/TR3_N: R147.1, U7.54 (TR3N); also elsewhere on the board
/TR3_P: R146.1, U7.55 (TR3P); also elsewhere on the board
/~MASTER_RESET: R126.2; also elsewhere on the board
GND: C52.2, C85.2, C86.2, C87.2, C88.2, C89.2, C90.2, C91.2, C92.2, C93.2, C94.2, C95.2, C123.2, C124.2, C125.2, C126.2, C127.2, C128.2, C130.2, C131.2, C132.2, C151.2, C152.2, C236.2, R55.1, R71.1, R134.1, U7.39 (TEST), U7.57 (GND/EP), U45.5 (GND), Y2.2, Y2.4; also elsewhere on the board
unnamed: C132.1, U7.6 (XO), Y2.3
unnamed: C151.1, U7.5 (XI), Y2.1
unnamed: D21.1 (K), U7.35 (GPIO4/LED4)
unnamed: D21.2 (A), R127.1
unnamed: D22.1 (K), U7.34 (GPIO3/LED3)
unnamed: D22.2 (A), R128.1
unnamed: D23.1 (K), U7.33 (GPIO2/LED2)
unnamed: D23.2 (A), R129.1
unnamed: R55.2, U7.41 (ETHRBIAS)
unnamed: R70.1, U7.1 (TDI)
unnamed: R71.2, U7.2 (TCK)
unnamed: R126.1, R130.1, U7.42 (nRESET/PME_CLEAR)
unnamed: R131.1, U7.3 (TMS)
unnamed: R134.2, U7.16 (USBRBIAS)
unnamed: R136.1, U7.14 (VBUS_DET)

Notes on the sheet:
*Optional - place close to Transformer

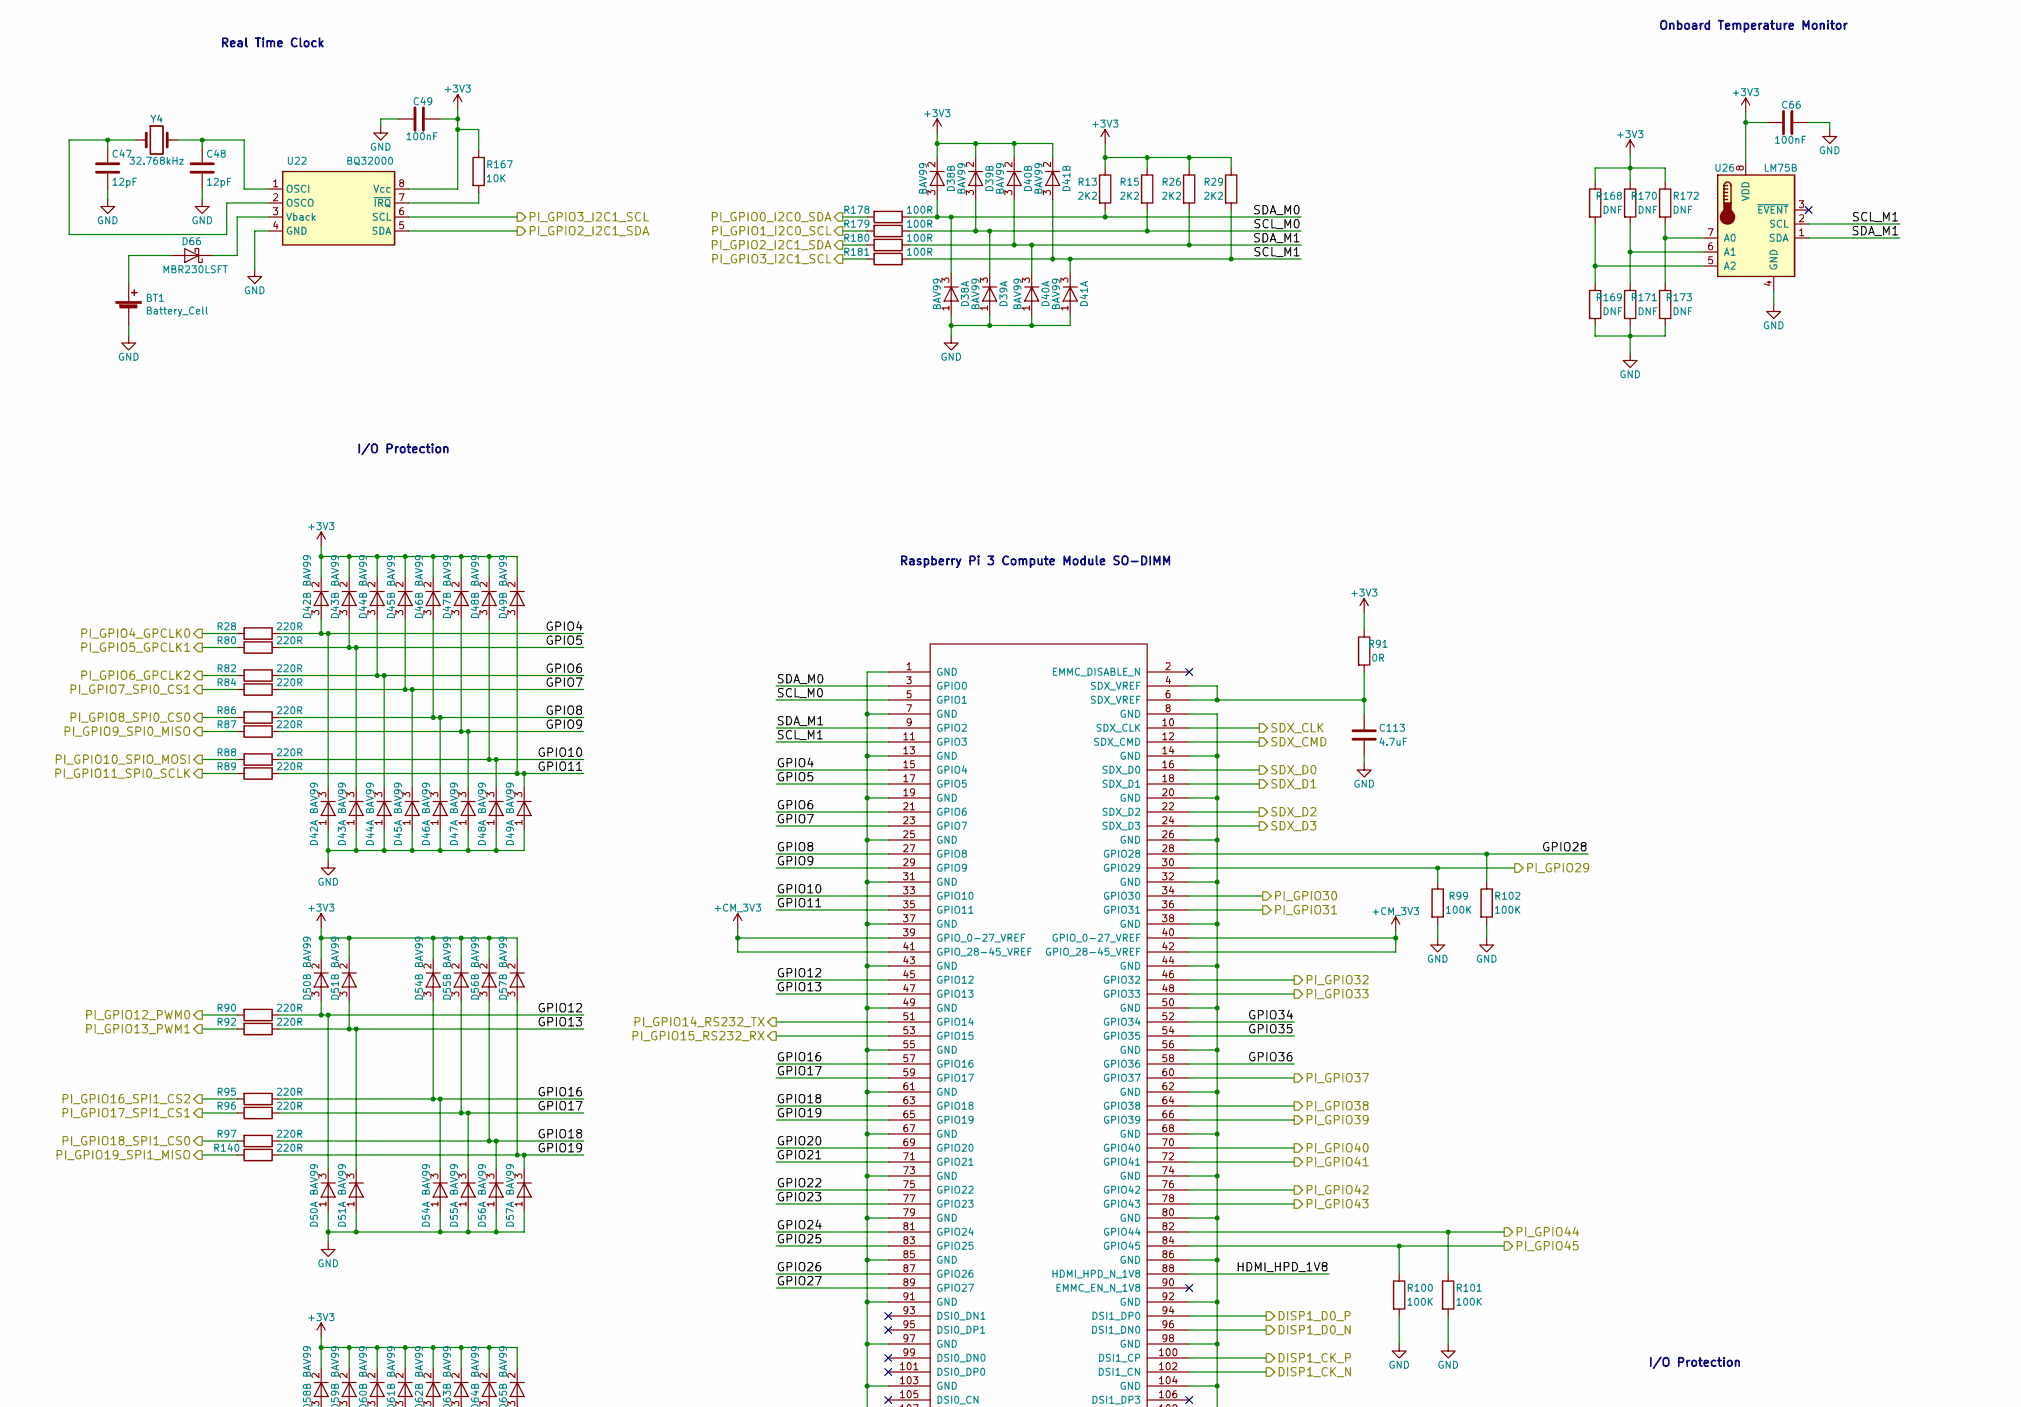
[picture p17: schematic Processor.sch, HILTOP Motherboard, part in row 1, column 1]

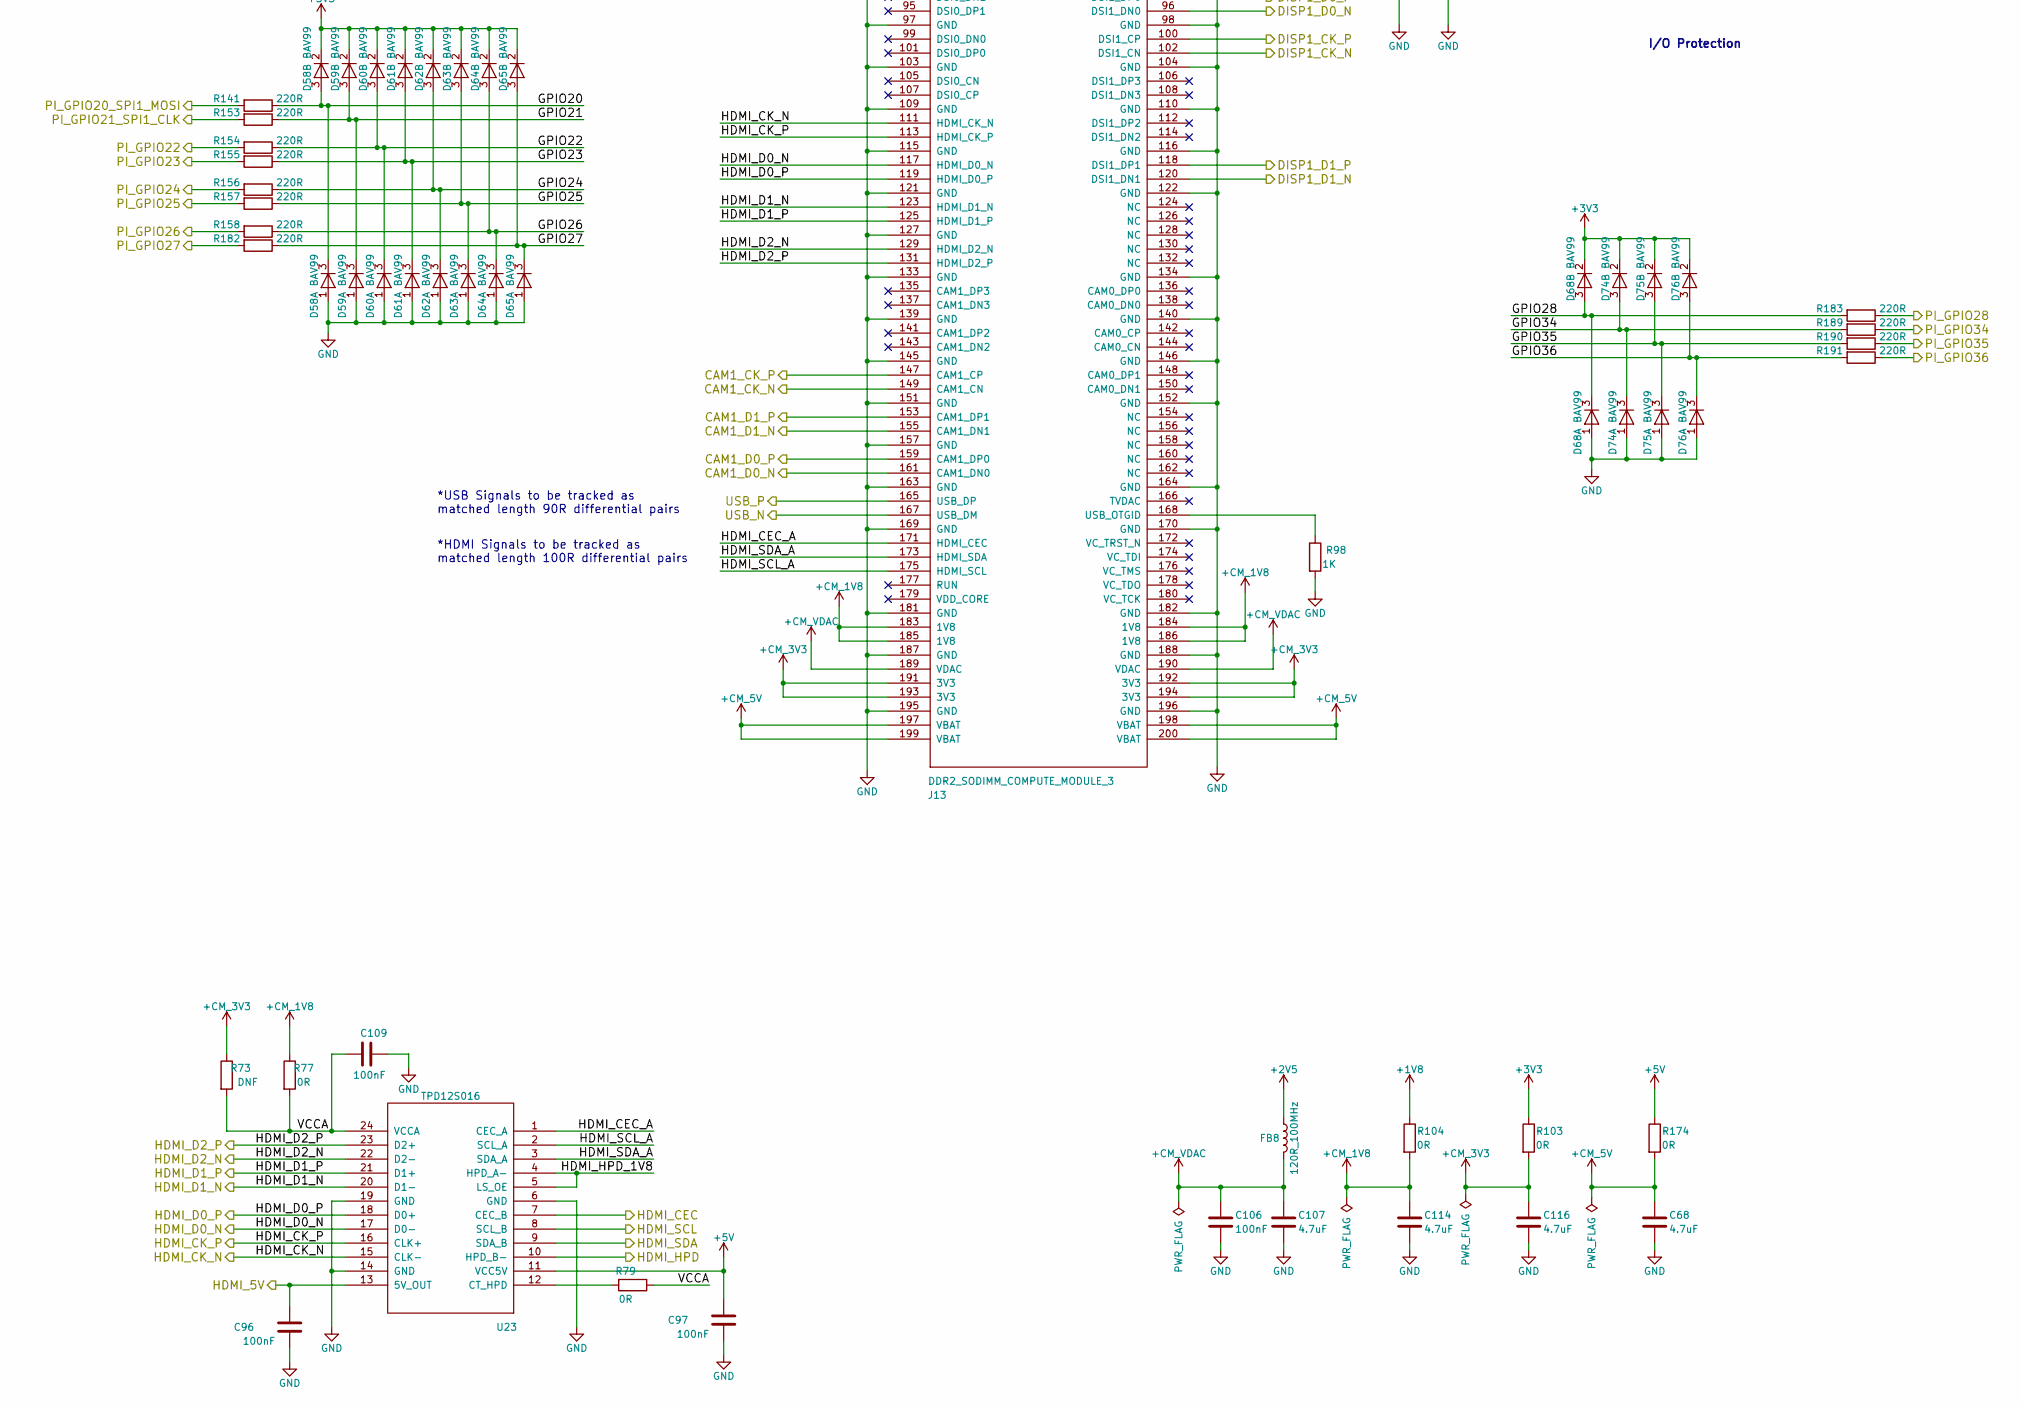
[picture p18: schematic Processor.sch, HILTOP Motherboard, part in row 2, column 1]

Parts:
BT1: Battery_Cell; BatteryHolder_Keystone_1061_1x20mm
C47, C48: 12pF; C_0603_1608Metric
C49, C66, C96, C97, C106, C109: 100nF; C_0603_1608Metric
C68, C107, C113, C114, C116: 4.7uF; C_0805_2012Metric
D38, D39, D40, D41, D42, D43, D44, D45, D46, D47, D48, D49, D50, D51, D54, D55, D56, D57, D58, D59, D60, D61, D62, D63, D64, D65, D68, D74, D75, D76: BAV99; SOT-23
D66: MBR230LSFT; D_SOD-123F
FB8: 120R_100MHz; R_0603_1608Metric
J13: DDR2_SODIMM_COMPUTE_MODULE_3; Conn_TE-DDR2-SODIMM-0.6-200P-ComputeModule
R13, R15, R26, R29: 2K2; R_0603_1608Metric
R28, R80, R82, R84, R86, R87, R88, R89, R90, R92, R95, R96, R97, R140, R141, R153, R154, R155, R156, R157, R158, R182, R183, R189, R190, R191: 220R; R_0402_1005Metric
R73: DNF; R_0603_1608Metric
R77, R79, R91, R103, R104, R174: 0R; R_0603_1608Metric
R98: 1K; R_0603_1608Metric
R99, R100, R101, R102: 100K; R_0402_1005Metric
R167: 10K; R_0603_1608Metric
R168, R169, R170, R171, R172, R173: DNF; R_0402_1005Metric
R178, R179, R180, R181: 100R; R_0402_1005Metric
U22: BQ32000; SOIC-8_3.9x4.9mm_P1.27mm
U23: TPD12S016; TSSOP-24_4.4x7.8mm_P0.65mm
U26: LM75B; SOIC-8_3.9x4.9mm_P1.27mm
Y4: 32.768kHz; Crystal_SMD_EuroQuartz_EQ161-2Pin_3.2x1.5mm

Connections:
+1V8: R104.1; also elsewhere on the board
+2V5: FB8.1; also elsewhere on the board
+3V3: C49.1, C66.2, D38.2 (K), D39.2 (K), D40.2 (K), D41.2 (K), D42.2 (K), D43.2 (K), D44.2 (K), D45.2 (K), D46.2 (K), D47.2 (K), D48.2 (K), D49.2 (K), D50.2 (K), D51.2 (K), D54.2 (K), D55.2 (K), D56.2 (K), D57.2 (K), D58.2 (K), D59.2 (K), D60.2 (K), D61.2 (K), D62.2 (K), D63.2 (K), D64.2 (K), D65.2 (K), D68.2 (K), D74.2 (K), D75.2 (K), D76.2 (K), R13.1, R15.1, R26.1, R29.1, R91.1, R103.1, R167.1, R168.1, R170.1, R172.1, U22.8 (Vcc), U26.8 (VDD); also elsewhere on the board
+5V: C97.2, R174.1, U23.11 (VCC5V); also elsewhere on the board
+CM_1V8: C114.1, J13.183 (1V8), J13.184 (1V8), J13.185 (1V8), J13.186 (1V8), R77.1, R104.2
+CM_3V3: C116.1, J13.39 (GPIO_0-27_VREF), J13.40 (GPIO_0-27_VREF), J13.41 (GPIO_28-45_VREF), J13.42 (GPIO_28-45_VREF), J13.191 (3V3), J13.192 (3V3), J13.193 (3V3), J13.194 (3V3), R73.1, R103.2
+CM_5V: C68.1, J13.197 (VBAT), J13.198 (VBAT), J13.199 (VBAT), J13.200 (VBAT), R174.2
+CM_VDAC: C106.1, C107.1, FB8.2, J13.189 (VDAC), J13.190 (VDAC)
/ATX_PWR_SHDN: J13.84 (GPIO45), R100.1; also elsewhere on the board
/BCK_SHUTDOWN: J13.36 (GPIO31); also elsewhere on the board
/CAM1_CK_N: J13.149 (CAM1_CN); also elsewhere on the board
/CAM1_CK_P: J13.147 (CAM1_CP); also elsewhere on the board
/CAM1_D0_N: J13.161 (CAM1_DN0); also elsewhere on the board
/CAM1_D0_P: J13.159 (CAM1_DP0); also elsewhere on the board
/CAM1_D1_N: J13.155 (CAM1_DN1); also elsewhere on the board
/CAM1_D1_P: J13.153 (CAM1_DP1); also elsewhere on the board
/CAN_CH1_CS: J13.70 (GPIO40); also elsewhere on the board
/CAN_CH2_CS: J13.72 (GPIO41); also elsewhere on the board
/DC_DC_ENABLE: J13.60 (GPIO37); also elsewhere on the board
/DC_OUT_ENABLE: J13.82 (GPIO44), R101.1; also elsewhere on the board
/DEBUG_RX: J13.53 (GPIO15); also elsewhere on the board
/DEBUG_TX: J13.51 (GPIO14); also elsewhere on the board
/DISP1_CK_N: J13.102 (DSI1_CN); also elsewhere on the board
/DISP1_CK_P: J13.100 (DSI1_CP); also elsewhere on the board
/DISP1_D0_N: J13.96 (DSI1_DN0); also elsewhere on the board
/DISP1_D0_P: J13.94 (DSI1_DP0); also elsewhere on the board
/DISP1_D1_N: J13.120 (DSI1_DN1); also elsewhere on the board
/DISP1_D1_P: J13.118 (DSI1_DP1); also elsewhere on the board
/EXT_TEMP_1WIRE: J13.34 (GPIO30); also elsewhere on the board
/FAN_SENSE_1: J13.46 (GPIO32); also elsewhere on the board
/FAN_SENSE_2: J13.48 (GPIO33); also elsewhere on the board
/I2C0_SCL: R179.2; also elsewhere on the board
/I2C0_SDA: R178.2; also elsewhere on the board
/I2C1_SCL: R181.2, U22.6 (SCL); also elsewhere on the board
/I2C1_SDA: R180.2, U22.5 (SDA); also elsewhere on the board
/MCP23017_INTA: J13.76 (GPIO42); also elsewhere on the board
/MCP23017_INTB: J13.78 (GPIO43); also elsewhere on the board
/PR_GPIO22: R154.2; also elsewhere on the board
/PR_GPIO23: R155.2; also elsewhere on the board
/PR_GPIO24: R156.2; also elsewhere on the board
/PR_GPIO25: R157.2; also elsewhere on the board
/PR_GPIO26: R158.2; also elsewhere on the board
/PR_GPIO27: R182.2; also elsewhere on the board
/PR_GPIO28: R183.1; also elsewhere on the board
/PR_GPIO34: R189.1; also elsewhere on the board
/PR_GPIO35: R190.1; also elsewhere on the board
/PR_GPIO36: R191.1; also elsewhere on the board
/Processor/GPIO4: D42.3 (K), J13.15 (GPIO4), R28.1
/Processor/GPIO5: D43.3 (K), J13.17 (GPIO5), R80.1
/Processor/GPIO6: D44.3 (K), J13.21 (GPIO6), R82.1
/Processor/GPIO7: D45.3 (K), J13.23 (GPIO7), R84.1
/Processor/GPIO8: D46.3 (K), J13.27 (GPIO8), R86.1
/Processor/GPIO9: D47.3 (K), J13.29 (GPIO9), R87.1
/Processor/GPIO10: D48.3 (K), J13.33 (GPIO10), R88.1
/Processor/GPIO11: D49.3 (K), J13.35 (GPIO11), R89.1
/Processor/GPIO12: D50.3 (K), J13.45 (GPIO12), R90.1
/Processor/GPIO13: D51.3 (K), J13.47 (GPIO13), R92.1
/Processor/GPIO16: D54.3 (K), J13.57 (GPIO16), R95.1
/Processor/GPIO17: D55.3 (K), J13.59 (GPIO17), R96.1
/Processor/GPIO18: D56.3 (K), J13.63 (GPIO18), R97.1
/Processor/GPIO19: D57.3 (K), J13.65 (GPIO19), R140.1
/Processor/GPIO20: D58.3 (K), J13.69 (GPIO20), R141.1
/Processor/GPIO21: D59.3 (K), J13.71 (GPIO21), R153.1
/Processor/GPIO22: D60.3 (K), J13.75 (GPIO22), R154.1
/Processor/GPIO23: D61.3 (K), J13.77 (GPIO23), R155.1
/Processor/GPIO24: D62.3 (K), J13.81 (GPIO24), R156.1
/Processor/GPIO25: D63.3 (K), J13.83 (GPIO25), R157.1
/Processor/GPIO26: D64.3 (K), J13.87 (GPIO26), R158.1
/Processor/GPIO27: D65.3 (K), J13.89 (GPIO27), R182.1
/Processor/GPIO28: D68.3 (K), J13.28 (GPIO28), R102.1, R183.2
/Processor/GPIO34: D74.3 (K), J13.52 (GPIO34), R189.2
/Processor/GPIO35: D75.3 (K), J13.54 (GPIO35), R190.2
/Processor/GPIO36: D76.3 (K), J13.58 (GPIO36), R191.2
/Processor/HDMI_5V: C96.2, U23.13 (5V_OUT); also elsewhere on the board
/Processor/HDMI_CEC: U23.7 (CEC_B); also elsewhere on the board
/Processor/HDMI_CEC_A: J13.171 (HDMI_CEC), U23.1 (CEC_A)
/Processor/HDMI_CK_N: J13.111 (HDMI_CK_N), U23.15 (CLK-); also elsewhere on the board
/Processor/HDMI_CK_P: J13.113 (HDMI_CK_P), U23.16 (CLK+); also elsewhere on the board
/Processor/HDMI_D0_N: J13.117 (HDMI_D0_N), U23.17 (D0-); also elsewhere on the board
/Processor/HDMI_D0_P: J13.119 (HDMI_D0_P), U23.18 (D0+); also elsewhere on the board
/Processor/HDMI_D1_N: J13.123 (HDMI_D1_N), U23.20 (D1-); also elsewhere on the board
/Processor/HDMI_D1_P: J13.125 (HDMI_D1_P), U23.21 (D1+); also elsewhere on the board
/Processor/HDMI_D2_N: J13.129 (HDMI_D2_N), U23.22 (D2-); also elsewhere on the board
/Processor/HDMI_D2_P: J13.131 (HDMI_D2_P), U23.23 (D2+); also elsewhere on the board
/Processor/HDMI_HPD: U23.10 (HPD_B-); also elsewhere on the board
/Processor/HDMI_HPD_1V8: J13.88 (HDMI_HPD_N_1V8), U23.4 (HPD_A-), U23.5 (LS_OE)
/Processor/HDMI_SCL: U23.8 (SCL_B); also elsewhere on the board
/Processor/HDMI_SCL_A: J13.175 (HDMI_SCL), U23.2 (SCL_A)
/Processor/HDMI_SDA: U23.9 (SDA_B); also elsewhere on the board
/Processor/HDMI_SDA_A: J13.173 (HDMI_SDA), U23.3 (SDA_A)
/Processor/PI_GPIO13_PWM1: R92.2; also elsewhere on the board
/Processor/SCL_M0: D39.3 (K), J13.5 (GPIO1), R15.2, R179.1
/Processor/SCL_M1: D41.3 (K), J13.11 (GPIO3), R29.2, R181.1, U26.2 (SCL)
/Processor/SDA_M0: D38.3 (K), J13.3 (GPIO0), R13.2, R178.1
/Processor/SDA_M1: D40.3 (K), J13.9 (GPIO2), R26.2, R180.1, U26.1 (SDA)
/Processor/SDX_CLK: J13.10 (SDX_CLK); also elsewhere on the board
/Processor/SDX_CMD: J13.12 (SDX_CMD); also elsewhere on the board
/Processor/SDX_D0: J13.16 (SDX_D0); also elsewhere on the board
/Processor/SDX_D1: J13.18 (SDX_D1); also elsewhere on the board
/Processor/SDX_D2: J13.22 (SDX_D2); also elsewhere on the board
/Processor/SDX_D3: J13.24 (SDX_D3); also elsewhere on the board
/Processor/VCCA: C109.2, R73.2, R77.2, R79.1, U23.24 (VCCA)
/SPI0_CS0: R86.2; also elsewhere on the board
/SPI0_CS1: R84.2; also elsewhere on the board
/SPI0_MISO: R87.2; also elsewhere on the board
/SPI0_MOSI: R88.2; also elsewhere on the board
/SPI0_SCLK: R89.2; also elsewhere on the board
/SPI1_CS0: R97.2; also elsewhere on the board
/SPI1_CS1_CAM_IO0: R96.2; also elsewhere on the board
/SPI1_CS2_CAM_IO1: R95.2; also elsewhere on the board
/SPI1_MISO: R140.2; also elsewhere on the board
/SPI1_MOSI: R141.2; also elsewhere on the board
/SPI1_SCLK: R153.2; also elsewhere on the board
/SYS_CLK0: R28.2; also elsewhere on the board
/SYS_CLK1: R80.2; also elsewhere on the board
/SYS_FAN_DC: J13.30 (GPIO29), R99.1; also elsewhere on the board
/SYS_PWM0: R90.2; also elsewhere on the board
/SYS_TRIG: R82.2; also elsewhere on the board
/UART_CH1_CS: J13.64 (GPIO38); also elsewhere on the board
/UART_CH2_CS: J13.66 (GPIO39); also elsewhere on the board
/USB_ROOT_N: J13.167 (USB_DM); also elsewhere on the board
/USB_ROOT_P: J13.165 (USB_DP); also elsewhere on the board
GND: BT1.2 (-), C47.2, C48.2, C49.2, C66.1, C68.2, C96.1, C97.1, C106.2, C107.2, C109.1, C113.2, C114.2, C116.2, D38.1 (A), D39.1 (A), D40.1 (A), D41.1 (A), D42.1 (A), D43.1 (A), D44.1 (A), D45.1 (A), D46.1 (A), D47.1 (A), D48.1 (A), D49.1 (A), D50.1 (A), D51.1 (A), D54.1 (A), D55.1 (A), D56.1 (A), D57.1 (A), D58.1 (A), D59.1 (A), D60.1 (A), D61.1 (A), D62.1 (A), D63.1 (A), D64.1 (A), D65.1 (A), D68.1 (A), D74.1 (A), D75.1 (A), D76.1 (A), J13.1 (GND), J13.7 (GND), J13.8 (GND), J13.13 (GND), J13.14 (GND), J13.19 (GND), J13.20 (GND), J13.25 (GND), J13.26 (GND), J13.31 (GND), J13.32 (GND), J13.37 (GND), J13.38 (GND), J13.43 (GND), J13.44 (GND), J13.49 (GND), J13.50 (GND), J13.55 (GND), J13.56 (GND), J13.61 (GND), J13.62 (GND), J13.67 (GND), J13.68 (GND), J13.73 (GND), J13.74 (GND), J13.79 (GND), J13.80 (GND), J13.85 (GND), J13.86 (GND), J13.91 (GND), J13.92 (GND), J13.97 (GND), J13.98 (GND), J13.103 (GND), J13.104 (GND), J13.109 (GND), J13.110 (GND), J13.115 (GND), J13.116 (GND), J13.121 (GND), J13.122 (GND), J13.127 (GND), J13.133 (GND), J13.134 (GND), J13.139 (GND), J13.140 (GND), J13.145 (GND), J13.146 (GND), J13.151 (GND), J13.152 (GND), J13.157 (GND), J13.163 (GND), J13.164 (GND), J13.169 (GND), J13.170 (GND), J13.181 (GND), J13.182 (GND), J13.187 (GND), J13.188 (GND), J13.195 (GND), J13.196 (GND), R98.2, R99.2, R100.2, R101.2, R102.2, R169.2, R171.2, R173.2, U22.4 (GND), U23.6 (GND), U23.14 (GND), U23.19 (GND), U26.4 (GND); also elsewhere on the board
unnamed: BT1.1 (+), D66.2 (A)
unnamed: C47.1, U22.2 (OSCO), Y4.1
unnamed: C48.1, U22.1 (OSCI), Y4.2
unnamed: C113.1, J13.4 (SDX_VREF), J13.6 (SDX_VREF), R91.2
unnamed: D66.1 (K), U22.3 (Vback)
unnamed: J13.168 (USB_OTGID), R98.1
unnamed: R79.2, U23.12 (CT_HPD)
unnamed: R167.2, U22.7 (~IRQ)
unnamed: R168.2, R169.1, U26.5 (A2)
unnamed: R170.2, R171.1, U26.6 (A1)
unnamed: R172.2, R173.1, U26.7 (A0)

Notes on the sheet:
*USB Signals to be tracked as matched length 90R differential pairs
*HDMI Signals to be tracked as matched length 100R differential pairs
I/O Protection
Raspberry Pi 3 Compute Module SO-DIMM
Real Time Clock
Onboard Temperature Monitor

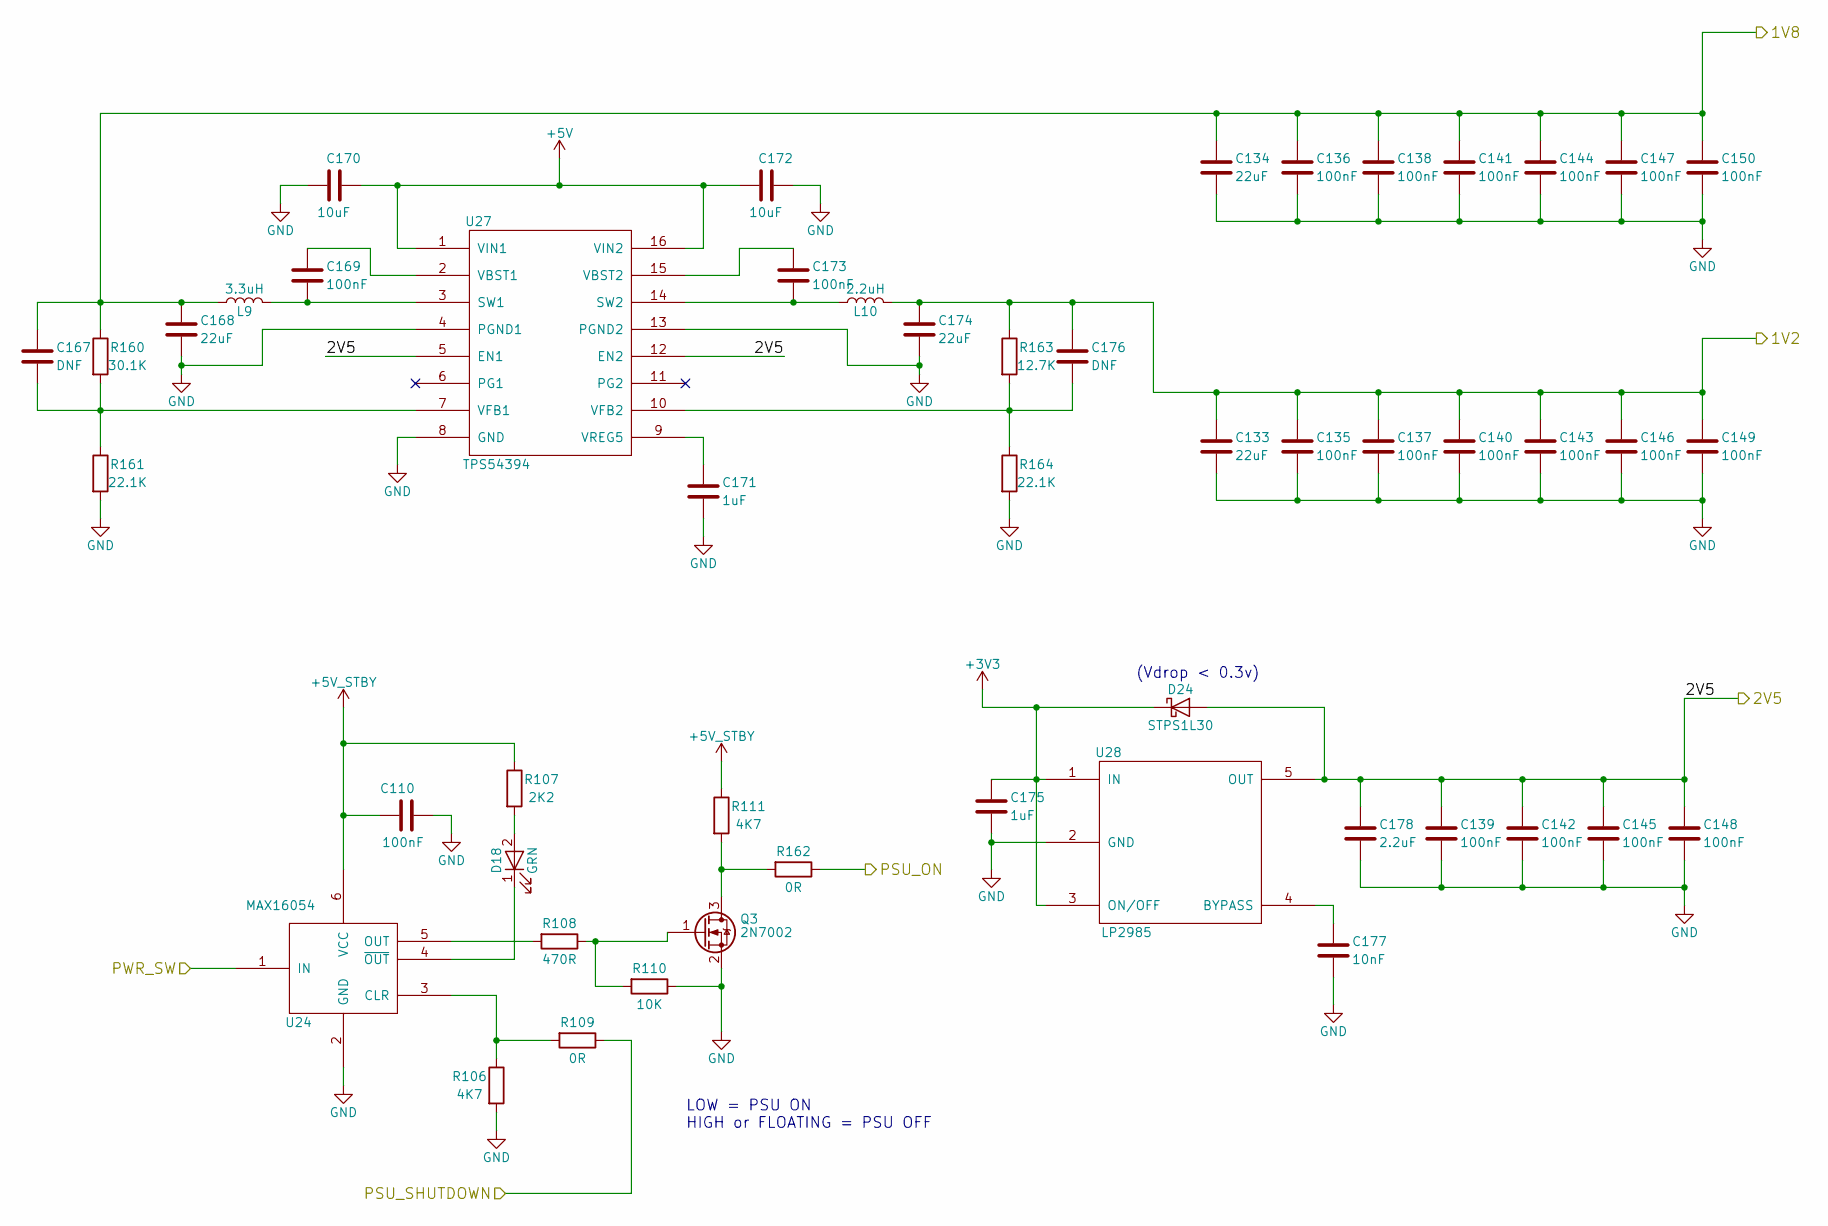
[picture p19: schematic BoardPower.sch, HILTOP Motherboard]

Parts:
C110, C135, C136, C137, C138, C139, C140, C141, C142, C143, C144, C145, C146, C147, C148, C149, C150, C169, C173: 100nF; C_0603_1608Metric
C133, C134, C168, C174: 22uF; C_1206_3216Metric
C167, C176: DNF; C_0603_1608Metric
C170, C172: 10uF; C_0805_2012Metric
C171: 1uF; C_0805_2012Metric
C175: 1uF; C_0603_1608Metric
C177: 10nF; C_0603_1608Metric
C178: 2.2uF; C_0805_2012Metric
D18: GRN; LED_0402_1005Metric
D24: STPS1L30; D_SMB
L9: 3.3uH; Inductor_8x8
L10: 2.2uH; Inductor_8x8
Q3: 2N7002; SOT-23
R106, R111: 4K7; R_0603_1608Metric
R107: 2K2; R_0603_1608Metric
R108: 470R; R_0603_1608Metric
R109, R162: 0R; R_0603_1608Metric
R110: 10K; R_0603_1608Metric
R160: 30.1K; R_0603_1608Metric
R161, R164: 22.1K; R_0603_1608Metric
R163: 12.7K; R_0603_1608Metric
U24: MAX16054; TSOT-23-6
U27: TPS54394; HTSSOP-16_4.4x5mm_Pitch0.65mm
U28: LP2985; SOT-23-5

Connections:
+1V2: C133.1, C135.1, C137.1, C140.1, C143.1, C146.1, C149.1, C174.1, C176.1, L10.2, R163.1; also elsewhere on the board
+1V8: C134.1, C136.1, C138.1, C141.1, C144.1, C147.1, C150.1, C167.1, C168.1, L9.1, R160.1; also elsewhere on the board
+2V5: C139.1, C142.1, C145.1, C148.1, C178.1, D24.2 (A), U27.5 (EN1), U27.12 (EN2), U28.5 (OUT); also elsewhere on the board
+3V3: C175.1, D24.1 (K), U28.1 (IN), U28.3 (ON/OFF); also elsewhere on the board
+5V: C170.1, C172.2, U27.1 (VIN1), U27.16 (VIN2); also elsewhere on the board
+5V_STBY: C110.1, R107.1, R111.1, U24.6 (VCC); also elsewhere on the board
/ATX_PWR_SHDN: R109.1; also elsewhere on the board
/BoardPower/PSU_ON: R162.1; also elsewhere on the board
/PWR_SW: U24.1 (IN); also elsewhere on the board
GND: C110.2, C133.2, C134.2, C135.2, C136.2, C137.2, C138.2, C139.2, C140.2, C141.2, C142.2, C143.2, C144.2, C145.2, C146.2, C147.2, C148.2, C149.2, C150.2, C168.2, C170.2, C171.2, C172.1, C174.2, C175.2, C177.2, C178.2, Q3.2 (S), R106.2, R110.1, R161.2, R164.2, U24.2 (GND), U27.4 (PGND1), U27.8 (GND), U27.13 (PGND2), U28.2 (GND); also elsewhere on the board
unnamed: C167.2, R160.2, R161.1, U27.7 (VFB1)
unnamed: C169.1, U27.2 (VBST1)
unnamed: C169.2, L9.2, U27.3 (SW1)
unnamed: C171.1, U27.9 (VREG5)
unnamed: C173.1, U27.15 (VBST2)
unnamed: C173.2, L10.1, U27.14 (SW2)
unnamed: C176.2, R163.2, R164.1, U27.10 (VFB2)
unnamed: C177.1, U28.4 (BYPASS)
unnamed: D18.1 (K), U24.4 (~OUT)
unnamed: D18.2 (A), R107.2
unnamed: Q3.1 (G), R108.1, R110.2
unnamed: Q3.3 (D), R111.2, R162.2
unnamed: R106.1, R109.2, U24.3 (CLR)
unnamed: R108.2, U24.5 (OUT)

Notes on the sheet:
LOW = PSU ON HIGH or FLOATING = PSU OFF
(Vdrop < 0.3v)

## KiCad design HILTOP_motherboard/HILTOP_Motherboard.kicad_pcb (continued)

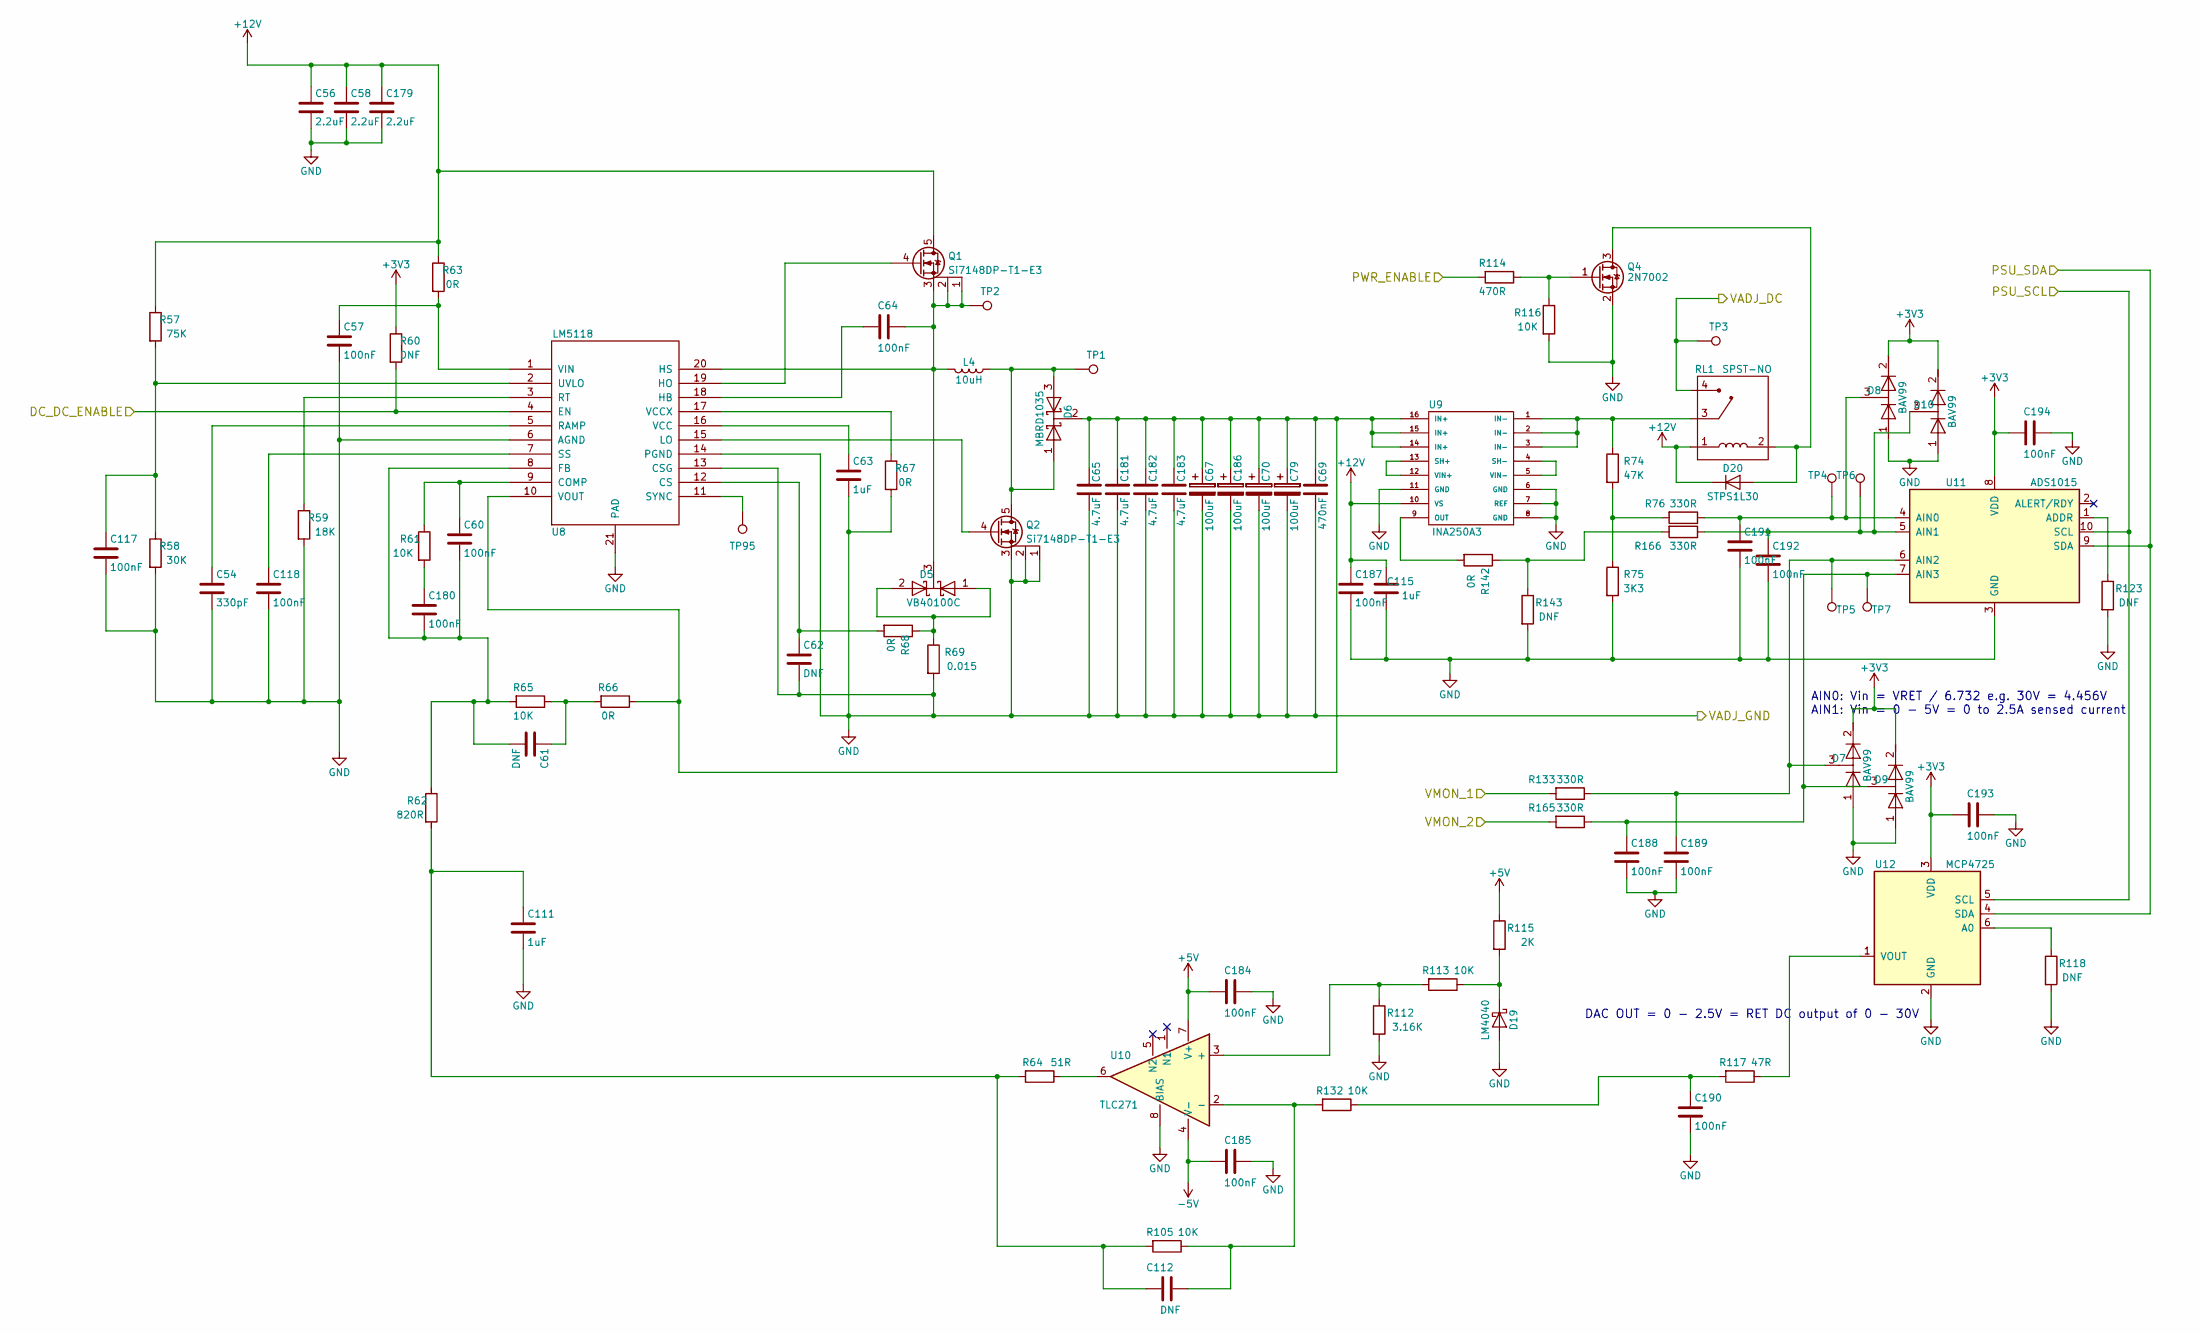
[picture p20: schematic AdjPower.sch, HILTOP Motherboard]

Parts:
C54: 330pF; C_0402_1005Metric
C56, C58, C179: 2.2uF; C_1206_3216Metric
C57, C60, C64, C117, C118, C180, C184, C185, C187, C188, C189, C190, C191, C192, C193, C194: 100nF; C_0603_1608Metric
C61, C62, C112: DNF; C_0603_1608Metric
C63, C111, C115: 1uF; C_0805_2012Metric
C65, C181, C182, C183: 4.7uF; C_1210_3225Metric
C67, C70, C79, C186: 100uF; CP_Elec_6.3x7.7
C69: 470nF; C_0805_2012Metric
D5: VB40100C; TO-263AB
D6: MBRD1035; DPAK
D7, D8, D9, D10: BAV99; SOT-23
D19: LM4040; SOT-23
D20: STPS1L30; D_SMB
L4: 10uH; Inductor_Coilcraft_SER2800
Q1, Q2: Si7148DP-T1-E3; PowerPAK_SO-8
Q4: 2N7002; SOT-23
R57: 75K; R_0603_1608Metric
R58: 30K; R_0603_1608Metric
R59: 18K; R_0603_1608Metric
R60, R118, R123, R143: DNF; R_0603_1608Metric
R61, R65, R105, R113, R116, R132: 10K; R_0603_1608Metric
R62: 820R; R_0603_1608Metric
R63: 0R; R_1206_3216Metric
R64: 51R; R_0603_1608Metric
R66, R67, R68, R142: 0R; R_0603_1608Metric
R69: 0.015; RL7520W_3008
R74: 47K; R_0603_1608Metric
R75: 3K3; R_0603_1608Metric
R76, R133, R165, R166: 330R; R_0603_1608Metric
R112: 3.16K; R_0603_1608Metric
R114: 470R; R_0603_1608Metric
R115: 2K; R_0603_1608Metric
R117: 47R; R_0603_1608Metric
RL1: SPST-NO; Relay_SPST_TE_PCH
TP1, TP2, TP3, TP4, TP5, TP6, TP7, TP95: TP; TestPoint_THTPad_D1.0mm_Drill0.5mm
U8: LM5118; HTSSOP-20-1EP_4.4x6.5mm_P0.65mm_ThermalPad
U9: INA250A3; TSSOP-16_4.4x5mm_P0.65mm
U10: TLC271; SOIC-8_3.9x4.9mm_P1.27mm
U11: ADS1015; TSSOP-10_3x3mm_P0.5mm
U12: MCP4725; SOT-23-6

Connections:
+3V3: C193.2, C194.2, D7.2 (K), D8.2 (K), D9.2 (K), D10.2 (K), R60.1, U11.8 (VDD), U12.3 (VDD); also elsewhere on the board
+5V: C184.2, R115.1, U10.7 (V+); also elsewhere on the board
+12V: C56.1, C58.1, C115.2, C179.1, C187.1, D20.1 (K), Q1.5 (D), R57.1, R63.1, RL1.1, U9.10 (VS); also elsewhere on the board
-5V: C185.2, U10.4 (V-); also elsewhere on the board
/AdjPower/VADJ_DC: RL1.4, TP3.1; also elsewhere on the board
/AdjPower/VMON_1: R133.2; also elsewhere on the board
/AdjPower/VMON_2: R165.2; also elsewhere on the board
/DC_DC_ENABLE: R60.2, U8.4 (EN); also elsewhere on the board
/DC_OUT_ENABLE: R114.2; also elsewhere on the board
/I2C1_SCL: U11.10 (SCL), U12.5 (SCL); also elsewhere on the board
/I2C1_SDA: U11.9 (SDA), U12.4 (SDA); also elsewhere on the board
GND: C54.2, C56.2, C57.2, C58.2, C62.2, C63.2, C65.1, C67.2, C69.1, C70.2, C79.2, C111.2, C115.1, C117.2, C118.2, C179.2, C181.1, C182.1, C183.1, C184.1, C185.1, C186.2, C187.2, C188.2, C189.2, C190.2, C191.2, C192.2, C193.1, C194.1, D7.1 (A), D8.1 (A), D9.1 (A), D10.1 (A), D19.2 (A), Q2.1, Q2.2, Q2.3 (S), Q4.2 (S), R58.2, R59.2, R67.2, R69.2, R75.2, R112.2, R116.2, R118.2, R123.2, R143.2, U8.6 (AGND), U8.13 (CSG), U8.14 (PGND), U8.21 (PAD), U9.6 (GND), U9.7 (REF), U9.8 (GND), U9.11 (GND), U10.8 (BIAS), U11.3 (GND), U12.2 (GND); also elsewhere on the board
unnamed: C54.1, U8.5 (RAMP)
unnamed: C57.1, R63.2, U8.1 (VIN)
unnamed: C60.1, R61.1, U8.9 (COMP)
unnamed: C61.1, R65.1, R66.2
unnamed: C62.1, R68.2, U8.12 (CS)
unnamed: C63.1, U8.16 (VCC)
unnamed: C64.1, D5.3 (K), L4.2, Q1.1, Q1.2, Q1.3 (S), TP2.1, U8.20 (HS)
unnamed: C64.2, U8.18 (HB)
unnamed: C111.1, C112.1, R62.2, R64.2, R105.2
unnamed: C112.2, R105.1, R132.2, U10.2 (-)
unnamed: C117.1, R57.2, R58.1, U8.2 (UVLO)
unnamed: C118.1, U8.7 (SS)
unnamed: C180.1, R61.2
unnamed: C60.2, C61.2, C180.2, R62.1, R65.2, U8.8 (FB)
unnamed: C65.2, C67.1, C69.2, C70.1, C79.1, C181.2, C182.2, C183.2, C186.1, D6.2 (K), R66.1, U8.10 (VOUT), U9.14 (IN+), U9.15 (IN+), U9.16 (IN+)
unnamed: C188.1, D9.3 (common), R165.1, TP7.1, U11.7 (AIN3)
unnamed: C189.1, D7.3 (common), R133.1, TP5.1, U11.6 (AIN2)
unnamed: C190.1, R117.2, R132.1
unnamed: C191.1, D8.3 (common), R76.1, TP4.1, U11.4 (AIN0)
unnamed: C192.1, D10.3 (common), R166.1, TP6.1, U11.5 (AIN1)
unnamed: D5.1 (A), D5.2 (A), R68.1, R69.1
unnamed: D6.1 (A), D6.3 (A), L4.1, Q2.5 (D), TP1.1
unnamed: D19.1 (K), R113.1, R115.2
unnamed: D20.2 (A), Q4.3 (D), RL1.2
unnamed: Q1.4 (G), U8.19 (HO)
unnamed: Q2.4 (G), U8.15 (LO)
unnamed: Q4.1 (G), R114.1, R116.1
unnamed: R59.1, U8.3 (RT)
unnamed: R64.1, U10.6
unnamed: R67.1, U8.17 (VCCX)
unnamed: R74.1, RL1.3, U9.1 (IN-), U9.2 (IN-), U9.3 (IN-)
unnamed: R74.2, R75.1, R76.2
unnamed: R112.1, R113.2, U10.3 (+)
unnamed: R117.1, U12.1 (VOUT)
unnamed: R118.1, U12.6 (A0)
unnamed: R123.1, U11.1 (ADDR)
unnamed: R142.1, R143.1, R166.2
unnamed: R142.2, U9.9 (OUT)
unnamed: TP95.1, U8.11 (SYNC)
unnamed: U9.4 (SH-), U9.5 (VIN-)
unnamed: U9.12 (VIN+), U9.13 (SH+)

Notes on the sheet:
AIN0: Vin = VRET / 6.732 e.g. 30V = 4.456V AIN1: Vin = 0 - 5V = 0 to 2.5A sensed current
DAC OUT = 0 - 2.5V = RET DC output of 0 - 30V

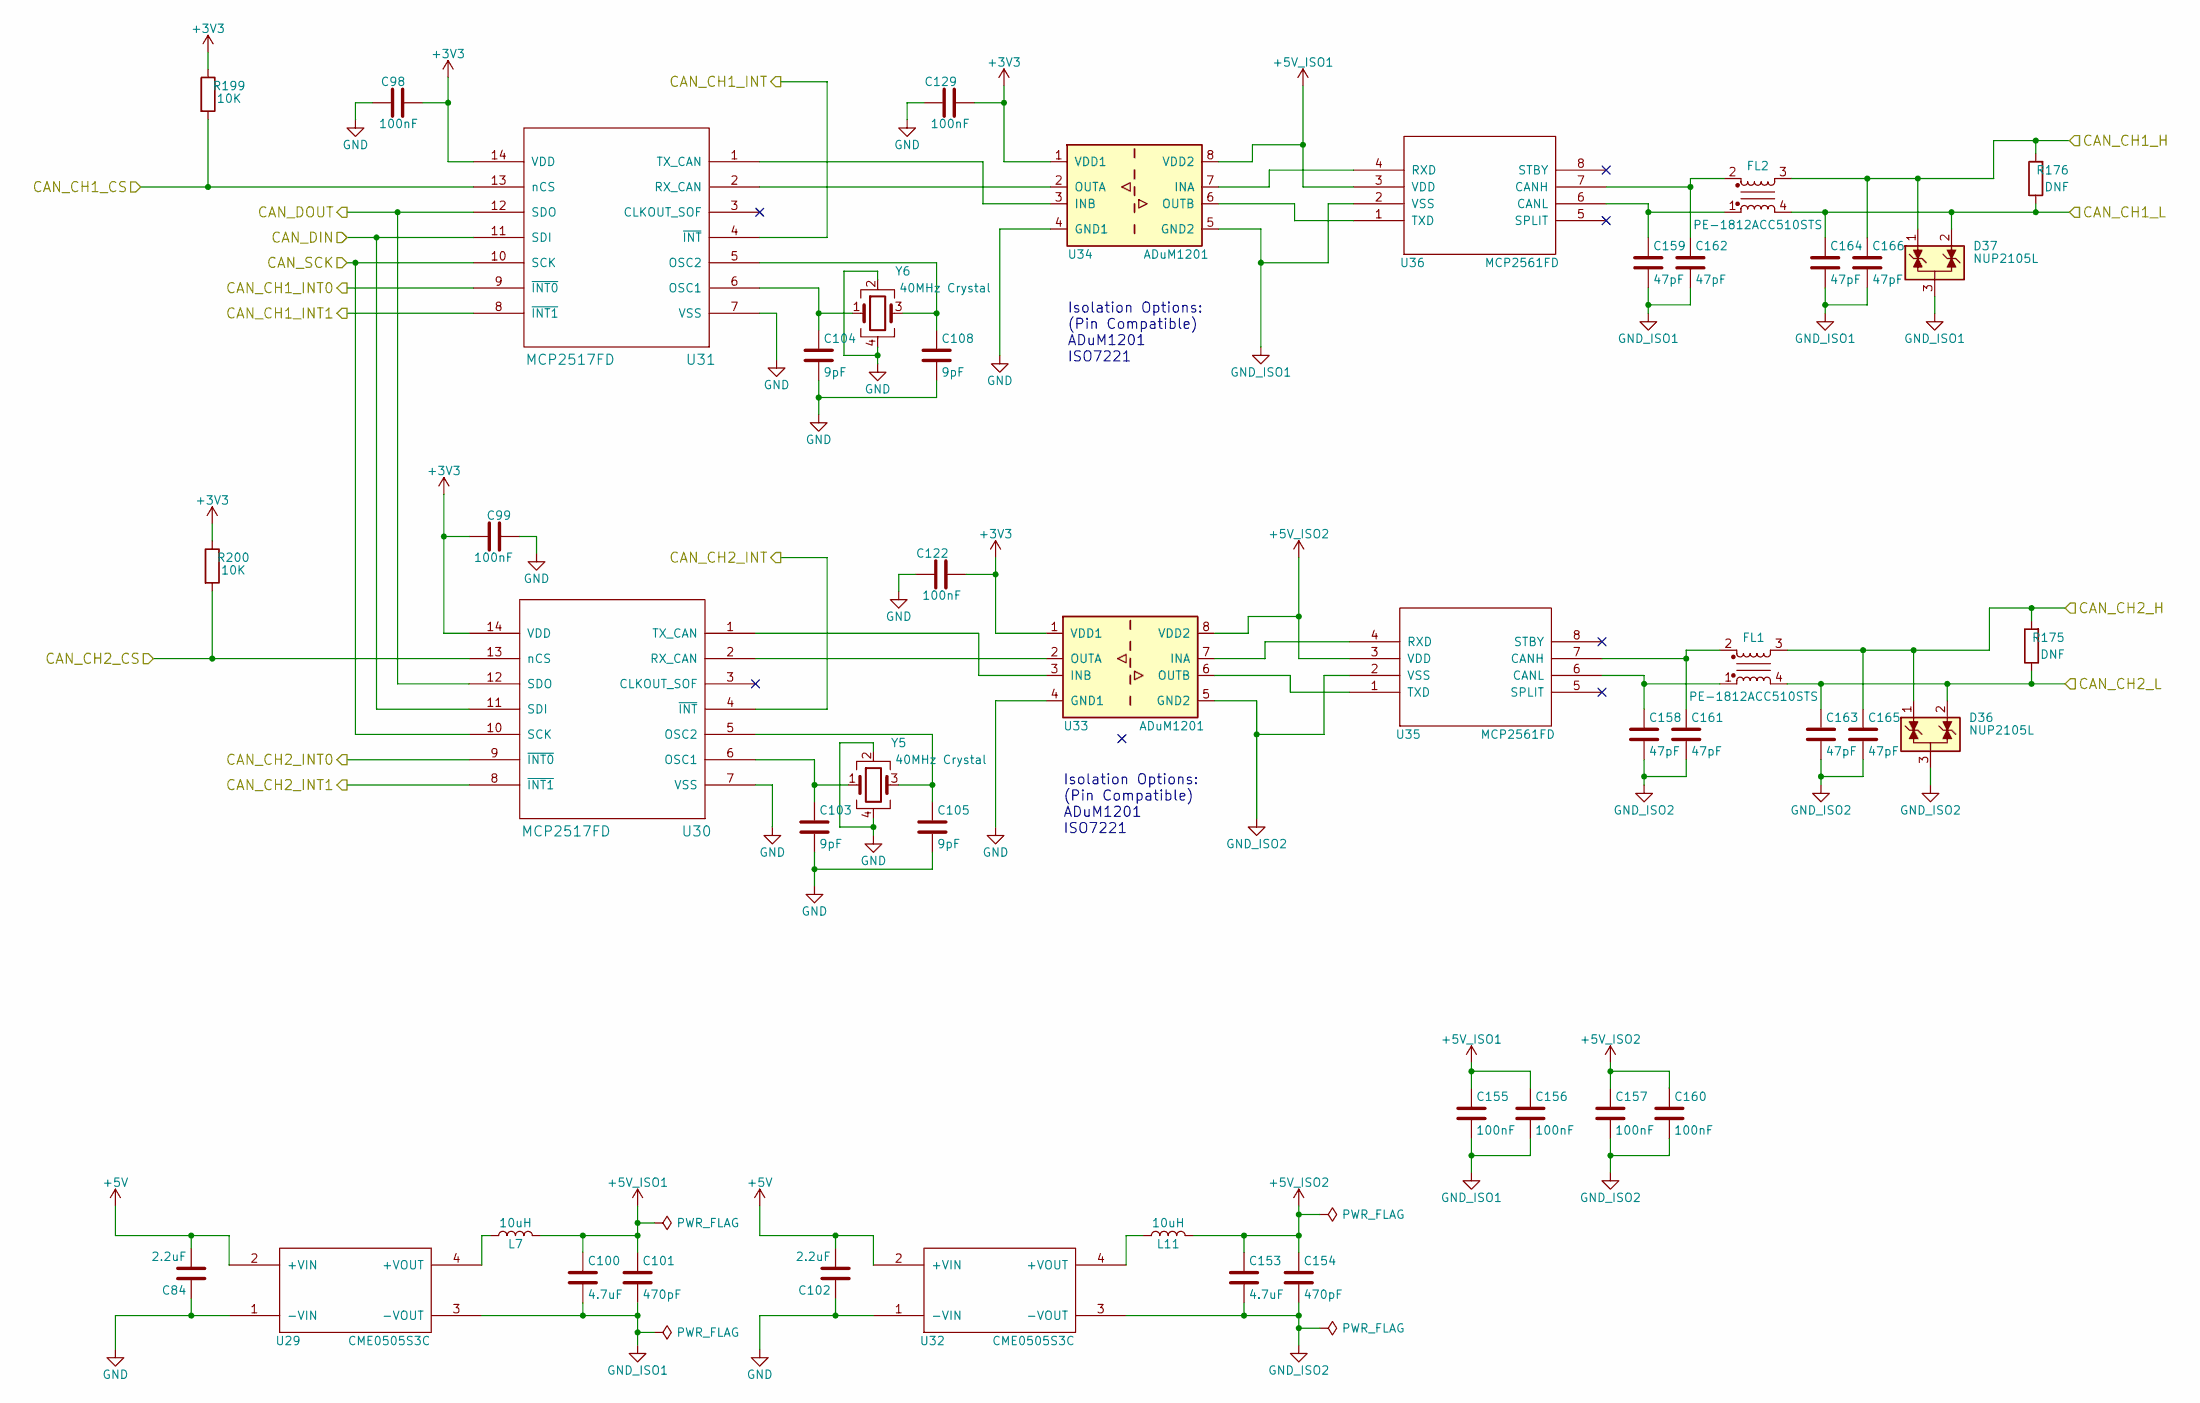
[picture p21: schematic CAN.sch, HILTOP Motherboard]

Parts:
C84, C102: 2.2uF; C_0805_2012Metric
C98, C99, C122, C129, C155, C156, C157, C160: 100nF; C_0603_1608Metric
C100, C153: 4.7uF; C_0805_2012Metric
C101, C154: 470pF; C_0603_1608Metric
C103, C104, C105, C108: 9pF; C_0603_1608Metric
C158, C159, C161, C162, C163, C164, C165, C166: 47pF; C_0603_1608Metric
D36, D37: NUP2105L; SOT-23
FL1, FL2: PE-1812ACC510STS; Inductor_PE-1812ACCXXXSTS
L7, L11: 10uH; Inductor_MuRata_82103C
R175, R176: DNF; R_0603_1608Metric
R199, R200: 10K; R_0603_1608Metric
U29, U32: CME0505S3C; CME_XXXX_S3C_PSU_MODULE
U30, U31: MCP2517FD; SOIC-14_3.9x8.7mm_P1.27mm
U33, U34: ADuM1201; SOIC-8_3.9x4.9mm_P1.27mm
U35, U36: MCP2561FD; SOIC-8_3.9x4.9mm_P1.27mm
Y5, Y6: 40MHz Crystal; Crystal_SMD_SeikoEpson_FA238V-4Pin_3.2x2.5mm

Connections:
+3V3: C98.2, C99.2, C122.2, C129.2, R199.1, R200.1, U30.14 (VDD), U31.14 (VDD), U33.1 (VDD1), U34.1 (VDD1); also elsewhere on the board
+5V: C84.2, C102.2, U29.2 (+VIN), U32.2 (+VIN); also elsewhere on the board
+5V_ISO1: C100.1, C101.1, C155.1, C156.1, L7.2, U34.8 (VDD2), U36.3 (VDD); also elsewhere on the board
+5V_ISO2: C153.1, C154.1, C157.1, C160.1, L11.2, U33.8 (VDD2), U35.3 (VDD); also elsewhere on the board
/CAN1_H: C166.1, D37.1 (K), FL2.3, R176.2; also elsewhere on the board
/CAN1_INT: U31.4 (~INT); also elsewhere on the board
/CAN1_L: C164.1, D37.2 (K), FL2.4, R176.1; also elsewhere on the board
/CAN2_H: C165.1, D36.1 (K), FL1.3, R175.2; also elsewhere on the board
/CAN2_INT: U30.4 (~INT); also elsewhere on the board
/CAN2_L: C163.1, D36.2 (K), FL1.4, R175.1; also elsewhere on the board
/CAN_CH1_CS: R199.2, U31.13 (nCS); also elsewhere on the board
/CAN_CH2_CS: R200.2, U30.13 (nCS); also elsewhere on the board
/SPI1_MISO: U30.12 (SDO), U31.12 (SDO); also elsewhere on the board
/SPI1_MOSI: U30.11 (SDI), U31.11 (SDI); also elsewhere on the board
/SPI1_SCLK: U30.10 (SCK), U31.10 (SCK); also elsewhere on the board
GND: C84.1, C98.1, C99.1, C102.1, C103.2, C104.2, C105.2, C108.2, C122.1, C129.1, U29.1 (-VIN), U30.7 (VSS), U31.7 (VSS), U32.1 (-VIN), U33.4 (GND1), U34.4 (GND1), Y5.2, Y5.4, Y6.2, Y6.4; also elsewhere on the board
GND_ISO1: C100.2, C101.2, C155.2, C156.2, C159.2, C162.2, C164.2, C166.2, D37.3 (A), U29.3 (-VOUT), U34.5 (GND2), U36.2 (VSS); also elsewhere on the board
GND_ISO2: C153.2, C154.2, C157.2, C158.2, C160.2, C161.2, C163.2, C165.2, D36.3 (A), U32.3 (-VOUT), U33.5 (GND2), U35.2 (VSS); also elsewhere on the board
unnamed: C103.1, U30.6 (OSC1), Y5.1
unnamed: C104.1, U31.6 (OSC1), Y6.1
unnamed: C105.1, U30.5 (OSC2), Y5.3
unnamed: C108.1, U31.5 (OSC2), Y6.3
unnamed: C158.1, FL1.1, U35.6 (CANL)
unnamed: C159.1, FL2.1, U36.6 (CANL)
unnamed: C161.1, FL1.2, U35.7 (CANH)
unnamed: C162.1, FL2.2, U36.7 (CANH)
unnamed: L7.1, U29.4 (+VOUT)
unnamed: L11.1, U32.4 (+VOUT)
unnamed: U30.1 (TX_CAN), U33.3 (INB)
unnamed: U30.2 (RX_CAN), U33.2 (OUTA)
unnamed: U31.1 (TX_CAN), U34.3 (INB)
unnamed: U31.2 (RX_CAN), U34.2 (OUTA)
unnamed: U33.6 (OUTB), U35.1 (TXD)
unnamed: U33.7 (INA), U35.4 (RXD)
unnamed: U34.6 (OUTB), U36.1 (TXD)
unnamed: U34.7 (INA), U36.4 (RXD)

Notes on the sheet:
Isolation Options: (Pin Compatible) ADuM1201 ISO7221

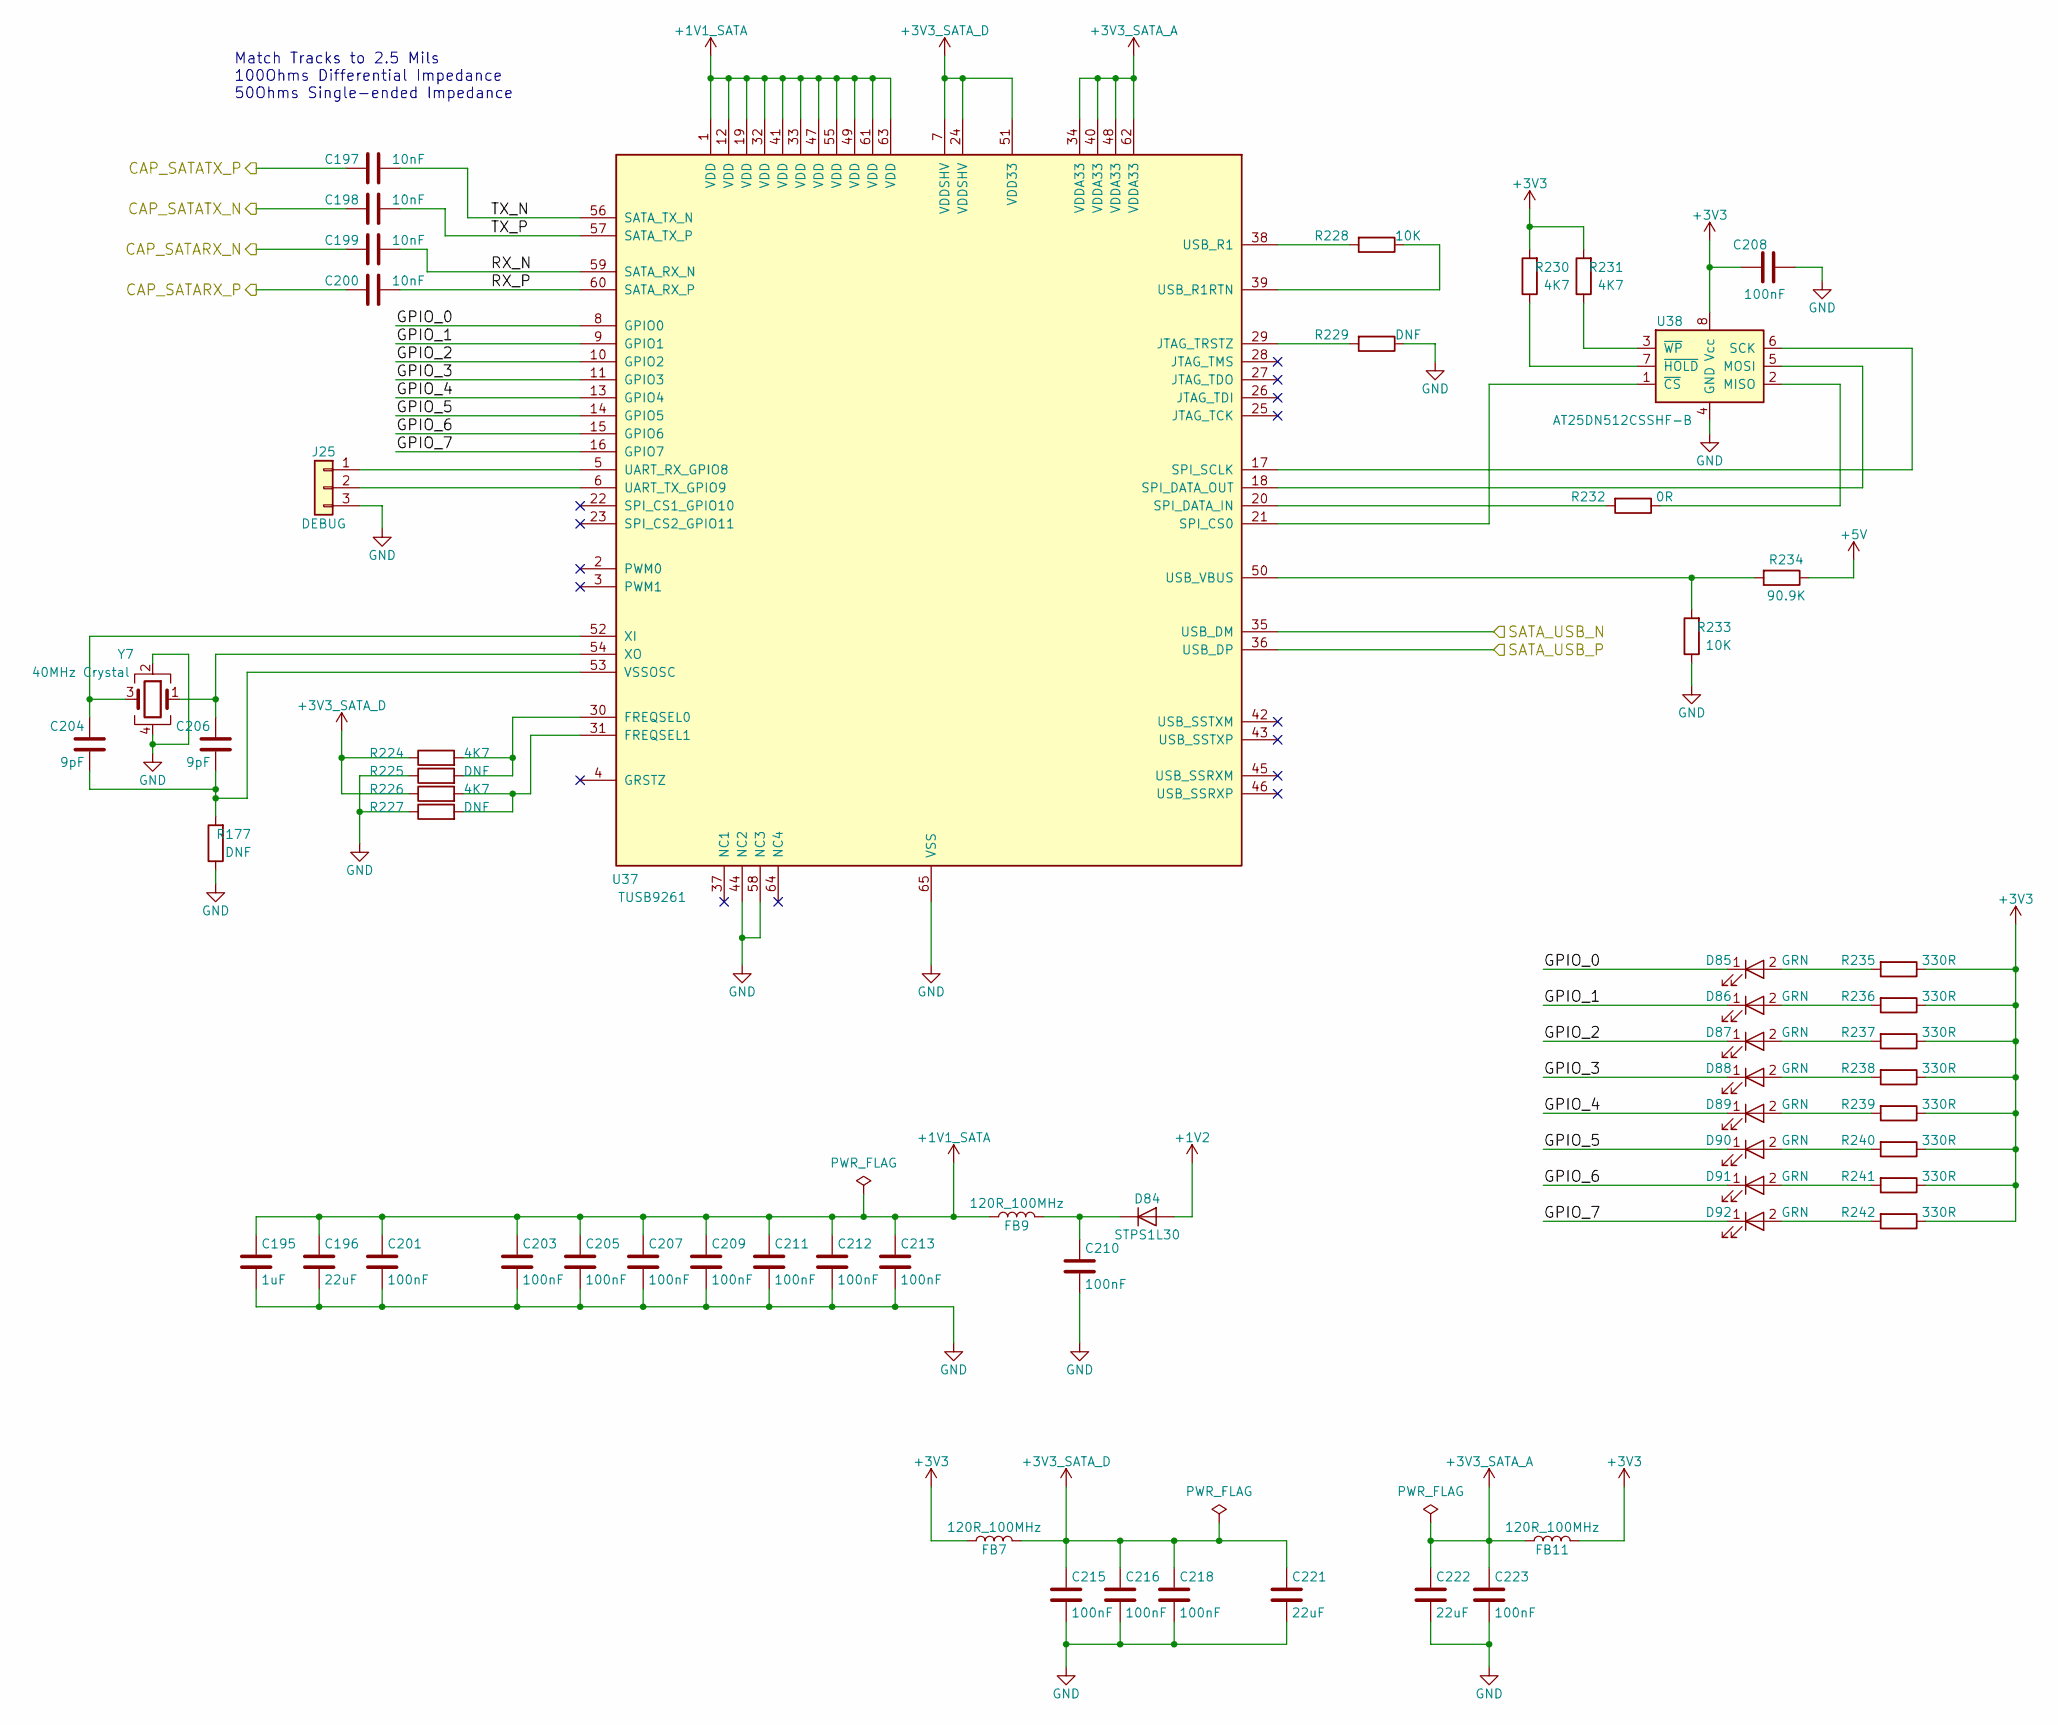
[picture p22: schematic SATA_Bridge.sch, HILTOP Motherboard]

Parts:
C195: 1uF; C_0603_1608Metric
C196, C221, C222: 22uF; C_1206_3216Metric
C197, C198, C199, C200: 10nF; C_0402_1005Metric
C201, C203, C205, C207, C208, C209, C210, C211, C212, C213, C215, C216, C218, C223: 100nF; C_0603_1608Metric
C204, C206: 9pF; C_0603_1608Metric
D84: STPS1L30; D_SMB
D85, D86, D87, D88, D89, D90, D91, D92: GRN; LED_0402_1005Metric
FB7, FB9, FB11: 120R_100MHz; R_0603_1608Metric
J25: DEBUG; PinHeader_1x03_P2.54mm_Vertical
R177, R225, R227, R229: DNF; R_0603_1608Metric
R224, R226, R230, R231: 4K7; R_0603_1608Metric
R228, R233: 10K; R_0603_1608Metric
R232: 0R; R_0603_1608Metric
R234: 90.9K; R_0603_1608Metric
R235, R236, R237, R238, R239, R240, R241, R242: 330R; R_0402_1005Metric
U37: TUSB9261; PQFP-64_7x7mm_P0.4mm_EP
U38: AT25DN512CSSHF-B; SOIC-8_3.9x4.9mm_P1.27mm
Y7: 40MHz Crystal; Crystal_SMD_SeikoEpson_FA238V-4Pin_3.2x2.5mm

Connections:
+1V1_SATA: C195.1, C196.1, C201.1, C203.1, C205.1, C207.1, C209.1, C211.1, C212.1, C213.1, FB9.1, U37.1 (VDD), U37.12 (VDD), U37.19 (VDD), U37.32 (VDD), U37.33 (VDD), U37.41 (VDD), U37.47 (VDD), U37.49 (VDD), U37.55 (VDD), U37.61 (VDD), U37.63 (VDD)
+1V2: D84.2 (A); also elsewhere on the board
+3V3: C208.1, FB7.1, FB11.2, R230.2, R231.2, R235.1, R236.1, R237.1, R238.1, R239.1, R240.1, R241.1, R242.1, U38.8 (Vcc); also elsewhere on the board
+3V3_SATA_A: C222.1, C223.1, FB11.1, U37.34 (VDDA33), U37.40 (VDDA33), U37.48 (VDDA33), U37.62 (VDDA33)
+3V3_SATA_D: C215.1, C216.1, C218.1, C221.1, FB7.2, R224.1, R226.1, U37.7 (VDDSHV), U37.24 (VDDSHV), U37.51 (VDD33)
+5V: R234.1; also elsewhere on the board
/SATA_Bridge/CAP_SATARX_N: C199.2; also elsewhere on the board
/SATA_Bridge/CAP_SATARX_P: C200.2; also elsewhere on the board
/SATA_Bridge/CAP_SATATX_N: C198.2; also elsewhere on the board
/SATA_Bridge/CAP_SATATX_P: C197.2; also elsewhere on the board
/SATA_Bridge/GPIO_0: D85.1 (K), U37.8 (GPIO0)
/SATA_Bridge/GPIO_1: D86.1 (K), U37.9 (GPIO1)
/SATA_Bridge/GPIO_2: D87.1 (K), U37.10 (GPIO2)
/SATA_Bridge/GPIO_3: D88.1 (K), U37.11 (GPIO3)
/SATA_Bridge/GPIO_4: D89.1 (K), U37.13 (GPIO4)
/SATA_Bridge/GPIO_5: D90.1 (K), U37.14 (GPIO5)
/SATA_Bridge/GPIO_6: D91.1 (K), U37.15 (GPIO6)
/SATA_Bridge/GPIO_7: D92.1 (K), U37.16 (GPIO7)
/SATA_Bridge/RX_N: C199.1, U37.59 (SATA_RX_N)
/SATA_Bridge/RX_P: C200.1, U37.60 (SATA_RX_P)
/SATA_Bridge/TX_N: C197.1, U37.56 (SATA_TX_N)
/SATA_Bridge/TX_P: C198.1, U37.57 (SATA_TX_P)
/SATA_USB_N: U37.35 (USB_DM); also elsewhere on the board
/SATA_USB_P: U37.36 (USB_DP); also elsewhere on the board
GND: C195.2, C196.2, C201.2, C203.2, C205.2, C207.2, C208.2, C209.2, C210.2, C211.2, C212.2, C213.2, C215.2, C216.2, C218.2, C221.2, C222.2, C223.2, J25.3, R177.1, R225.1, R227.1, R229.1, R233.1, U37.44 (NC2), U37.58 (NC3), U37.65 (VSS), U38.4 (GND), Y7.2, Y7.4; also elsewhere on the board
unnamed: C204.1, U37.52 (XI), Y7.3
unnamed: C204.2, C206.2, R177.2, U37.53 (VSSOSC)
unnamed: C206.1, U37.54 (XO), Y7.1
unnamed: C210.1, D84.1 (K), FB9.2
unnamed: D85.2 (A), R235.2
unnamed: D86.2 (A), R236.2
unnamed: D87.2 (A), R237.2
unnamed: D88.2 (A), R238.2
unnamed: D89.2 (A), R239.2
unnamed: D90.2 (A), R240.2
unnamed: D91.2 (A), R241.2
unnamed: D92.2 (A), R242.2
unnamed: J25.1, U37.5 (UART_RX_GPIO8)
unnamed: J25.2, U37.6 (UART_TX_GPIO9)
unnamed: R224.2, R225.2, U37.30 (FREQSEL0)
unnamed: R226.2, R227.2, U37.31 (FREQSEL1)
unnamed: R228.1, U37.39 (USB_R1RTN)
unnamed: R228.2, U37.38 (USB_R1)
unnamed: R229.2, U37.29 (JTAG_TRSTZ)
unnamed: R230.1, U38.7 (~HOLD)
unnamed: R231.1, U38.3 (~WP)
unnamed: R232.1, U38.2 (MISO)
unnamed: R232.2, U37.20 (SPI_DATA_IN)
unnamed: R233.2, R234.2, U37.50 (USB_VBUS)
unnamed: U37.17 (SPI_SCLK), U38.6 (SCK)
unnamed: U37.18 (SPI_DATA_OUT), U38.5 (MOSI)
unnamed: U37.21 (SPI_CS0), U38.1 (~CS)

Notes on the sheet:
Match Tracks to 2.5 Mils 100Ohms Differential Impedance 50Ohms Single-ended Impedance

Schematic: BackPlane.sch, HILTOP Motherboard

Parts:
J24: HILTOP_PCIE-64_CONN; PCIE-064-02-X-D-TH

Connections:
/BACKPLANE_USB_N: J24.B2 (USB_N); also elsewhere on the board
/BACKPLANE_USB_P: J24.B1 (USB_P); also elsewhere on the board
/BCK_SHUTDOWN: J24.B5 (SHUTDOWN); also elsewhere on the board
/I2C0_SCL: J24.B24 (I2C0_SCL/BCM1); also elsewhere on the board
/I2C0_SDA: J24.B23 (I2C0_SDA/BCM0); also elsewhere on the board
/I2C1_SCL: J24.B27 (I2C1_SCL/BCM3); also elsewhere on the board
/I2C1_SDA: J24.B26 (I2C1_SDA/BCM2); also elsewhere on the board
/PORT1_SEL: J24.A5 (PSEL/BCM38); also elsewhere on the board
/PORT2_SEL: J24.A6 (PSEL/BCM39); also elsewhere on the board
/PORT3_SEL: J24.A7 (PSEL/BCM40); also elsewhere on the board
/PORT4_SEL: J24.A8 (PSEL/BCM41); also elsewhere on the board
/PORT5_SEL: J24.A9 (PSEL/BCM42); also elsewhere on the board
/PORT6_SEL: J24.A10 (PSEL/BCM43); also elsewhere on the board
/PR_GPIO22: J24.B10 (GPIO1/BCM22); also elsewhere on the board
/PR_GPIO23: J24.B11 (GPIO2/BCM23); also elsewhere on the board
/PR_GPIO24: J24.B12 (GPIO3/BCM24); also elsewhere on the board
/PR_GPIO25: J24.B13 (GPIO4/BCM25); also elsewhere on the board
/PR_GPIO26: J24.B14 (GPIO5/BCM26); also elsewhere on the board
/PR_GPIO27: J24.B16 (GPIO6/BCM27); also elsewhere on the board
/PR_GPIO28: J24.B17 (GPIO7/BCM28); also elsewhere on the board
/PR_GPIO34: J24.B18 (GPIO8/BCM34); also elsewhere on the board
/PR_GPIO35: J24.B20 (GPIO9/BCM35); also elsewhere on the board
/PR_GPIO36: J24.B21 (GPIO10/BCM36); also elsewhere on the board
/SPI0_CS0: J24.A20 (SPIO_CS0/BCM8); also elsewhere on the board
/SPI0_CS1: J24.A21 (SPI0_CS1/BCM7); also elsewhere on the board
/SPI0_MISO: J24.A18 (SPIO_MISO/BCM9); also elsewhere on the board
/SPI0_MOSI: J24.A17 (SPIO_MOSI/BCM10); also elsewhere on the board
/SPI0_SCLK: J24.A19 (SPIO_CLK/BCM11); also elsewhere on the board
/SPI1_CS0: J24.A26 (SPI1_CS0/BCM18); also elsewhere on the board
/SPI1_CS1_CAM_IO0: J24.A27 (SPI1_CS1/BCM17); also elsewhere on the board
/SPI1_CS2_CAM_IO1: J24.B29 (GPIO11); also elsewhere on the board
/SPI1_MISO: J24.A24 (SPI1_MISO/BCM19); also elsewhere on the board
/SPI1_MOSI: J24.A23 (SPI1_MOSI/BCM20); also elsewhere on the board
/SPI1_SCLK: J24.A25 (SPI1_CLK/BCM21); also elsewhere on the board
/SYS_CLK1: J24.A2 (SYS_CLK/BCM5); also elsewhere on the board
/SYS_PWM0: J24.B7 (PWM0/BCM12); also elsewhere on the board
/SYS_PWM1: J24.B8 (PWM1/BCM13); also elsewhere on the board
/SYS_TRIG: J24.A3 (SYS_TRIG/BCM6); also elsewhere on the board
/~MASTER_RESET: J24.B4 (RESET); also elsewhere on the board
GND: J24.A1 (GND), J24.A4 (GND), J24.A11 (GND), J24.A16 (GND), J24.A22 (GND), J24.A28 (GND), J24.A32 (GND), J24.B3 (GND), J24.B6 (GND), J24.B9 (GND), J24.B15 (GND), J24.B19 (GND), J24.B22 (GND), J24.B25 (GND), J24.B28 (GND), J24.B32 (GND); also elsewhere on the board

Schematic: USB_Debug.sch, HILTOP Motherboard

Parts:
C217, C224: 4.7uF; C_0805_2012Metric
C219, C225: 100nF; C_0603_1608Metric
D32, D33: GRN; LED_0402_1005Metric
R201, R203, R208, R209: 0R; R_0603_1608Metric
R202: DNF; R_0603_1608Metric
R204, R205: 330R; R_0603_1608Metric
U40: SP3003-02XJ; SC70-5
U41: CP2102N-A01-GQFN24; QFN-24-1EP_4x4mm_P0.5mm_EP2.6x2.6mm_ThermalVias

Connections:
+3V3: C217.1, C219.1, C224.1, C225.1, D32.2 (A), D33.2 (A), R202.2, U41.5 (VIO), U41.6 (VDD), U41.7 (REGIN); also elsewhere on the board
+5V: U40.3 (VCC); also elsewhere on the board
/DEBUG_RX: R209.1; also elsewhere on the board
/DEBUG_TX: R208.1; also elsewhere on the board
/USB_Debug/USB_BUS_PWR: R203.2; also elsewhere on the board
/USB_Debug/USB_N: U40.4 (IO2), U41.4 (D-); also elsewhere on the board
/USB_Debug/USB_P: U40.5 (IO1), U41.3 (D+); also elsewhere on the board
/~MASTER_RESET: R201.2; also elsewhere on the board
GND: C217.2, C219.2, C224.2, C225.2, U40.2 (GND), U41.2 (GND), U41.25 (GND); also elsewhere on the board
unnamed: D32.1 (K), R204.1
unnamed: D33.1 (K), R205.1
unnamed: R201.1, R202.1, U41.9 (~RSTb)
unnamed: R203.1, U41.8 (VBUS)
unnamed: R204.2, U41.13 (GPIO.1)
unnamed: R205.2, U41.14 (GPIO.0)
unnamed: R208.2, U41.20 (RXD)
unnamed: R209.2, U41.21 (TXD)

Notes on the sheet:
RXT
TXT

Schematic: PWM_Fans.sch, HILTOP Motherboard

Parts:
C237, C238: DNF; C_0603_1608Metric
Q5, Q6, Q7: ZXMN6A07F; SOT-23
Q8: SSM3J328R; SOT-23
R159, R184, R185, R217, R218: 10K; R_0603_1608Metric
R215, R216: 470R; R_0603_1608Metric
R219, R220: DNF; R_0603_1608Metric

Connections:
+5V: R219.1, R220.1; also elsewhere on the board
+12V: C237.1, Q8.2 (S), R184.1; also elsewhere on the board
/PWM_Fans/12V_SW_LOAD: C238.2, Q8.3 (D); also elsewhere on the board
/PWM_Fans/FAN1_OUT: Q5.3 (D), R219.2; also elsewhere on the board
/PWM_Fans/FAN2_OUT: Q6.3 (D), R220.2; also elsewhere on the board
/SYS_FAN_DC: Q7.1 (G), R159.1; also elsewhere on the board
/SYS_FAN_PWM: R215.2, R216.2; also elsewhere on the board
GND: Q5.2 (S), Q6.2 (S), Q7.2 (S), R159.2, R217.2, R218.2; also elsewhere on the board
unnamed: C237.2, C238.1, Q8.1 (G), R184.2, R185.1
unnamed: Q5.1 (G), R215.1, R217.1
unnamed: Q6.1 (G), R216.1, R218.1
unnamed: Q7.3 (D), R185.2

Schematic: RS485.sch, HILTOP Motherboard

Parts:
C43, C46: 470pF; C_0603_1608Metric
C44, C78: 2.2uF; C_0805_2012Metric
C45, C76: 4.7uF; C_0805_2012Metric
C80, C81, C82, C83, C226, C228, C230, C231, C232, C233, C234, C235: 100nF; C_0603_1608Metric
C227, C229: 1uF; C_0603_1608Metric
FB6, FB10: 120R_100MHz; R_0603_1608Metric
L5, L6: 10uH; Inductor_MuRata_82103C
R81, R221, R222, R244: 10K; R_0603_1608Metric
R223: 0R; R_0603_1608Metric
R243: DNF; R_0603_1608Metric
U13, U17: CME0505S3C; CME_XXXX_S3C_PSU_MODULE
U15, U16: ISO3080; SOIC-16W_7.5x10.3mm_P1.27mm
U18, U19, U20, U21: USB6B1; SOIC-8_3.9x4.9mm_P1.27mm
U43, U44: MAX3107; SSOP-24_5.3x8.2mm_P0.65mm
Y8, Y9: 3.6864MHz Crystal; Crystal_SMD_SeikoEpson_MA505-2Pin_12.7x5.1mm

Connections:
+2V5: FB6.1, FB10.1; also elsewhere on the board
+3V3: C80.2, C81.2, C226.2, C228.2, C232.1, C233.1, C234.1, C235.1, R221.1, R222.1, R243.1, U15.1 (VCC1), U16.1 (VCC1), U43.5 (~I2C/~SPI), U43.6 (LDOEN), U43.13 (VL), U43.23 (VEXT), U44.5 (~I2C/~SPI), U44.6 (LDOEN), U44.13 (VL), U44.23 (VEXT); also elsewhere on the board
+5V: C44.2, C78.2, U13.2 (+VIN), U17.2 (+VIN); also elsewhere on the board
+5V_ISO3: C43.1, C76.1, C82.1, L5.2, U15.16 (VCC2), U18.1 (Vcc), U18.5 (Vcc), U19.1 (Vcc), U19.5 (Vcc); also elsewhere on the board
+5V_ISO4: C45.1, C46.1, C83.1, L6.2, U16.16 (VCC2), U20.1 (Vcc), U20.5 (Vcc), U21.1 (Vcc), U21.5 (Vcc); also elsewhere on the board
/A1: U18.6 (I/O1); also elsewhere on the board
/A2: U20.6 (I/O1); also elsewhere on the board
/B1: U18.7 (I/O2); also elsewhere on the board
/B2: U20.7 (I/O2); also elsewhere on the board
/SPI0_MISO: U43.7 (DOUT/SDA), U44.7 (DOUT/SDA); also elsewhere on the board
/SPI0_MOSI: U43.10 (DIN/A1), U44.10 (DIN/A1); also elsewhere on the board
/SPI0_SCLK: U43.8 (SCLK/SCL), U44.8 (SCLK/SCL); also elsewhere on the board
/UART_CH1_CS: R221.2, U43.9 (~CS/~A0); also elsewhere on the board
/UART_CH1_IRQ: U43.11 (~IRQ); also elsewhere on the board
/UART_CH2_CS: R222.2, U44.9 (~CS/~A0); also elsewhere on the board
/UART_CH2_IRQ: U44.11 (~IRQ); also elsewhere on the board
/Y1: U19.7 (I/O2); also elsewhere on the board
/Y2: U21.7 (I/O2); also elsewhere on the board
/Z1: U19.6 (I/O1); also elsewhere on the board
/Z2: U21.6 (I/O1); also elsewhere on the board
/~MASTER_RESET: R223.2; also elsewhere on the board
GND: C44.1, C78.1, C80.1, C81.1, C226.1, C227.1, C228.1, C229.1, C230.1, C231.1, C232.2, C233.2, C234.2, C235.2, R81.2, R244.2, U13.1 (-VIN), U15.2 (GND1), U15.4 (~RE), U15.7 (GND1), U15.8 (GND1), U16.2 (GND1), U16.4 (~RE), U16.7 (GND1), U16.8 (GND1), U17.1 (-VIN), U43.2 (AGND), U43.14 (DGND), U44.2 (AGND), U44.14 (DGND); also elsewhere on the board
GND_ISO3: C43.2, C76.2, C82.2, U13.3 (-VOUT), U15.9 (GND2), U15.10 (GND2), U15.15 (GND2), U18.4 (GND), U18.8 (GND), U19.4 (GND), U19.8 (GND); also elsewhere on the board
GND_ISO4: C45.2, C46.2, C83.2, U16.9 (GND2), U16.10 (GND2), U16.15 (GND2), U17.3 (-VOUT), U20.4 (GND), U20.8 (GND), U21.4 (GND), U21.8 (GND); also elsewhere on the board
unnamed: C227.2, U43.4 (V18)
unnamed: C229.2, U44.4 (V18)
unnamed: C230.2, FB6.2, U43.3 (VA)
unnamed: C231.2, FB10.2, U44.3 (VA)
unnamed: L5.1, U13.4 (+VOUT)
unnamed: L6.1, U17.4 (+VOUT)
unnamed: R81.1, U15.5 (DE), U43.20 (~RTS~/CLKOUT)
unnamed: R223.1, R243.2, U43.12 (~RST), U44.12 (~RST)
unnamed: R244.1, U16.5 (DE), U44.20 (~RTS~/CLKOUT)
unnamed: U15.3 (R), U43.21 (RX)
unnamed: U15.6 (D), U43.22 (TX)
unnamed: U15.11 (Y), U19.3 (I/O2)
unnamed: U15.12 (Z), U19.2 (I/O1)
unnamed: U15.13 (B), U18.3 (I/O2)
unnamed: U15.14 (A), U18.2 (I/O1)
unnamed: U16.3 (R), U44.21 (RX)
unnamed: U16.6 (D), U44.22 (TX)
unnamed: U16.11 (Y), U21.3 (I/O2)
unnamed: U16.12 (Z), U21.2 (I/O1)
unnamed: U16.13 (B), U20.3 (I/O2)
unnamed: U16.14 (A), U20.2 (I/O1)
unnamed: U43.1 (XIN), Y8.1
unnamed: U43.24 (XOUT), Y8.2
unnamed: U44.1 (XIN), Y9.1
unnamed: U44.24 (XOUT), Y9.2

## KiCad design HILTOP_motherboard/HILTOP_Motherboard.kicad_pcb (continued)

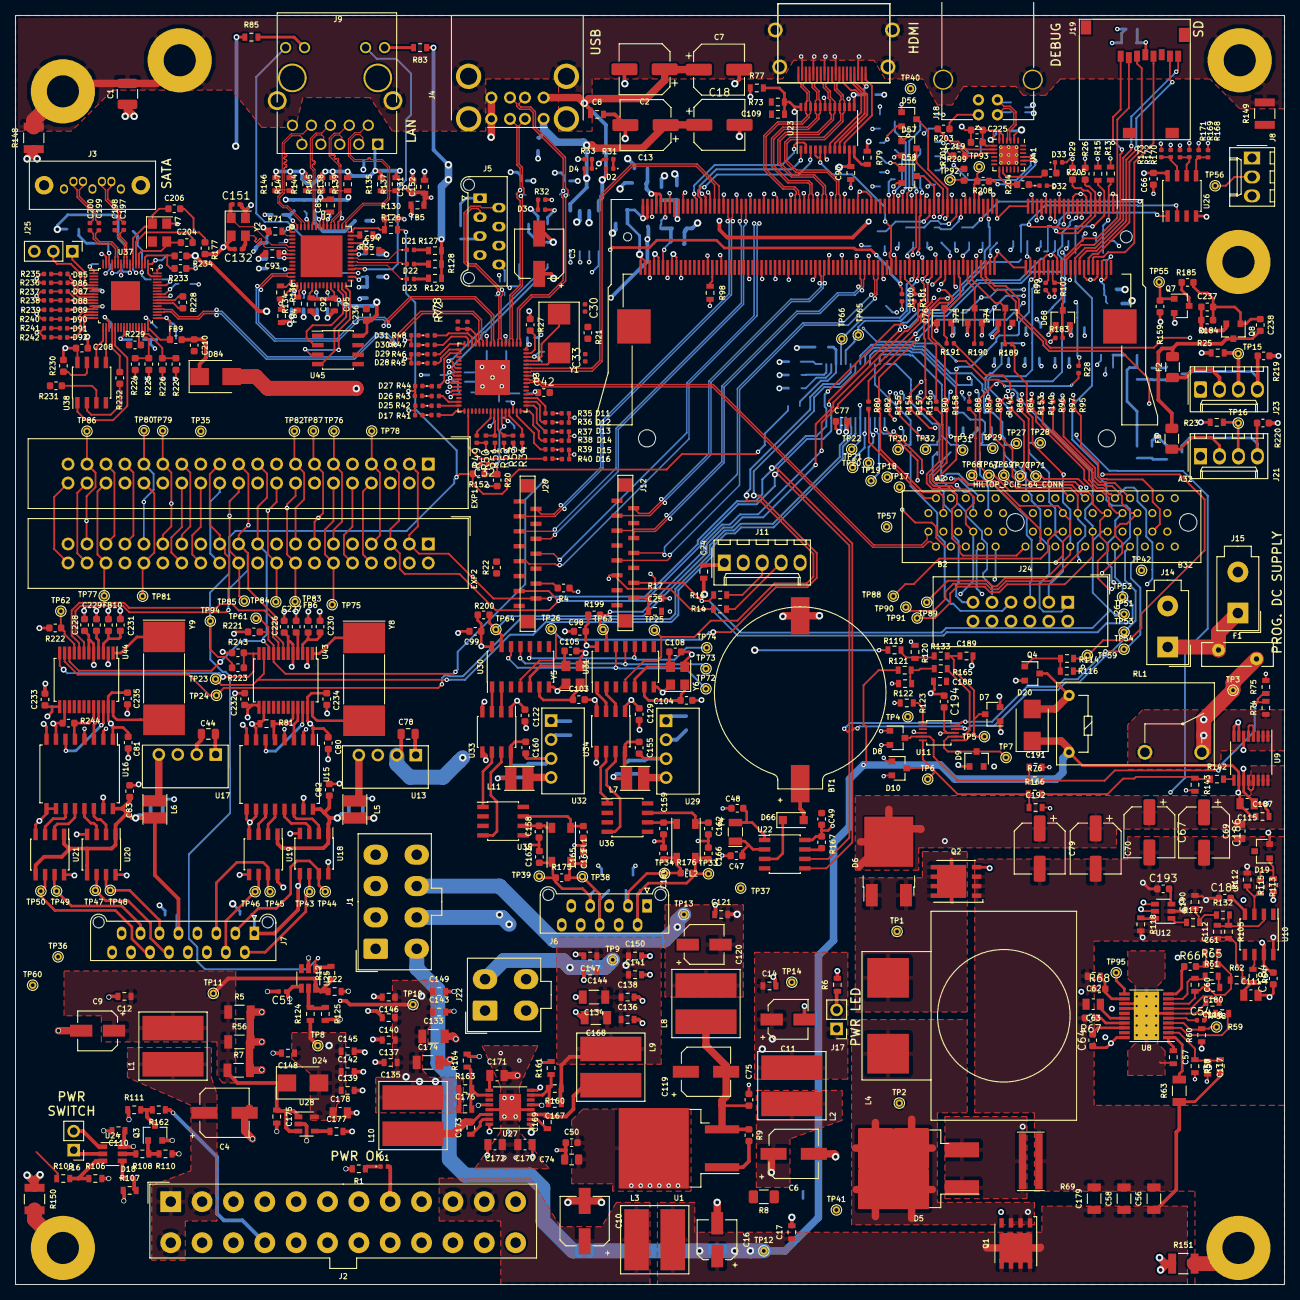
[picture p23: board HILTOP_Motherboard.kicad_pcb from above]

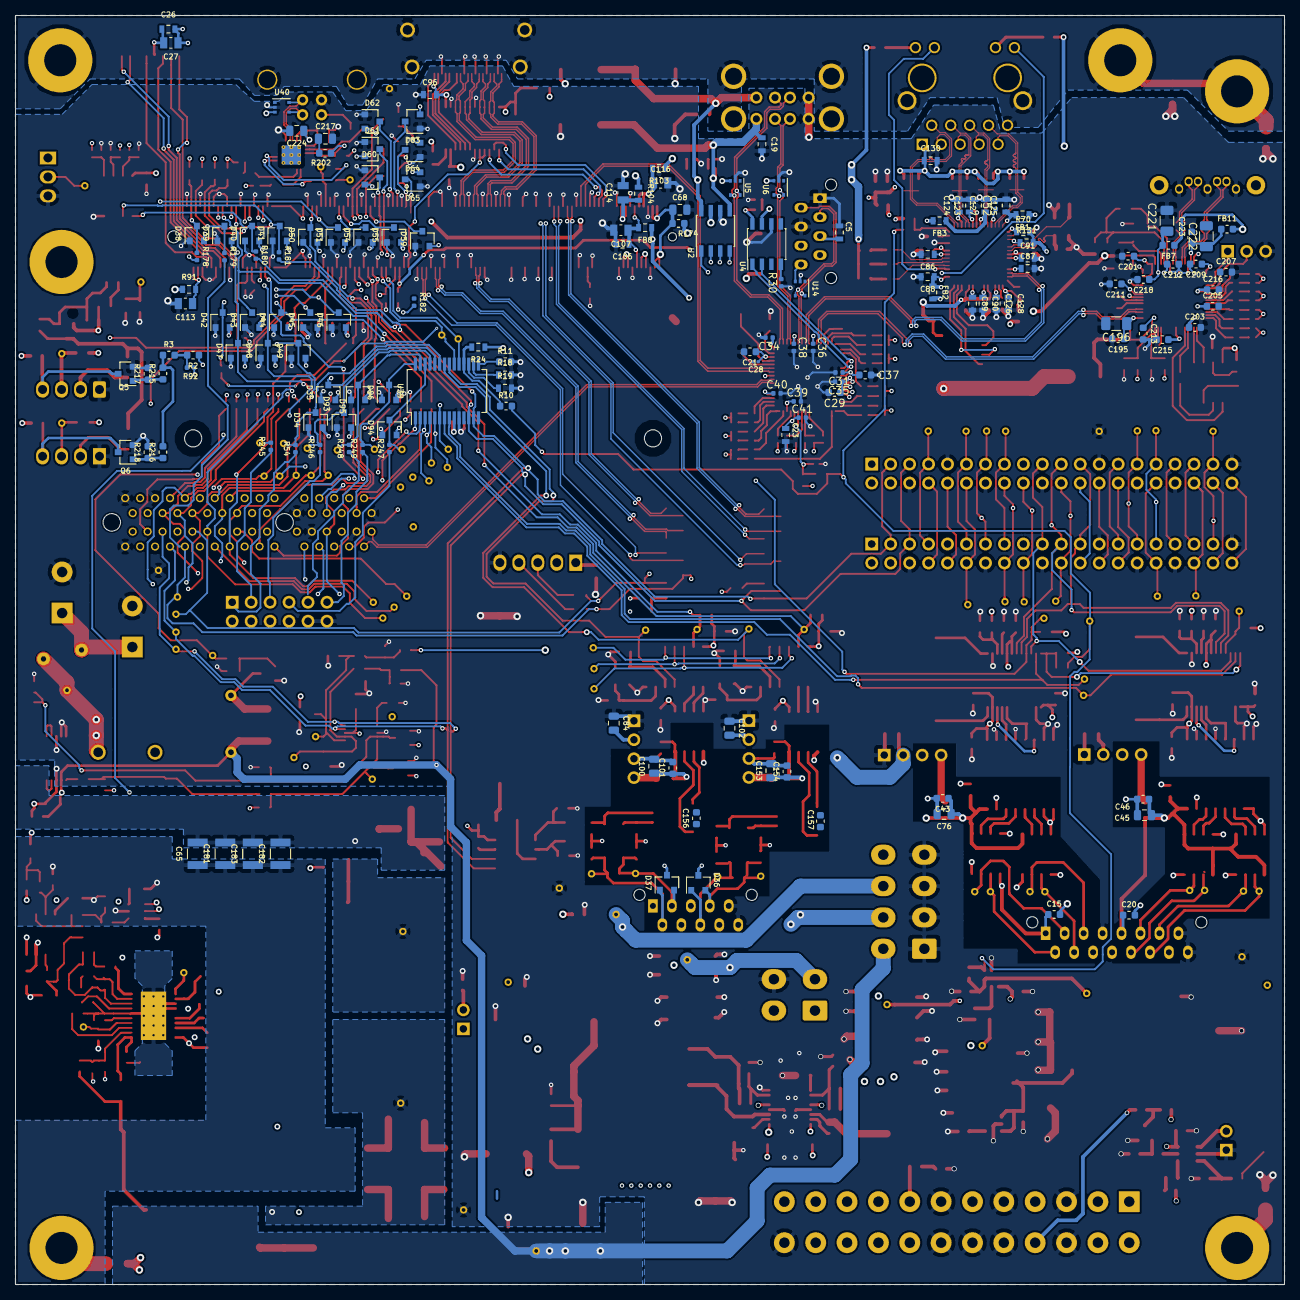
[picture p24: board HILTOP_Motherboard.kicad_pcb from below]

Board: 6 copper layers, 170.0 x 170.0 mm, 752 parts (151 on the bottom side), 473 nets.

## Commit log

2018-01-26 Setup common libraries for my Kicad project.
2018-01-26 Project setup - ready for development
    [BoardPower.sch, Ethernet.sch, HILTOP_Motherboard.kicad_pcb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]
2018-02-25 Added new USB2.0 device
    [BoardPower.sch, CAN.sch, Ethernet.sch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]
2018-02-26 add SP3003 ESD protection diodes to USB circuit
    [USBHub.sch]
2018-02-26 Added RTC and Temp Sensor
    [BoardPower.sch, CAN.sch, Ethernet.sch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]
2018-02-27 Added TUSB9260 SATA bridge device
2018-02-27 Added more detail for SATA bridge chip circuit
    [BoardPower.sch, CAN.sch, Ethernet.sch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]
2018-03-09 Fixed giabit LAN Schematic errors
    [HILTOP_Motherboard.kicad_pcb, HILTOP_Motherboard.sch, RETPower.sch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]
2018-03-09 Added more detail to motherboard schemas
    [BackPlane.sch, CAN.sch, HILTOP_Motherboard.sch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]
2018-05-03 Finished CAN nd RS485 interface circuits
    [CAN.sch, HILTOP_Motherboard.kicad_pcb, HILTOP_Motherboard.sch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]
2018-05-03 Updated pinouts for Backplane and Compute Module
    [AdjPower.sch, BackPlane.sch, BoardPower.sch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]
2018-05-08 Furthe progress on Schematics, assigned all main footprints using latest libraries, removed unwanted tracking and parts from original PCB layout
    [AdjPower.sch, BackPlane.sch, BoardPower.sch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]
2018-12-21 Schematics complete - 1st draft
    [AdjPower.sch, BackPlane.sch, BoardPower.sch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]
2018-12-21 Schematics complete - 1st draft2
    [AdjPower-2018-09-17-11-31-07.sch, BackPlane-2018-09-17-11-31-07.sch, BoardPower-2018-09-17-11-31-07.sch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]
2019-01-04 BOM nearly complete!
    [AdjPower.sch, BackPlane.sch, BoardPower.sch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]
2019-01-09 nearly finished placing all parts!
    [CAN.sch, HILTOP_Motherboard.csv, HILTOP_Motherboard.kicad_pcb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]
2019-01-11 All parts placed and backplane connector checked and locked
    [AdjPower.sch, BackPlane.sch, BoardPower.sch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]
2019-01-14 DRC checks complete, all errors and warnings cleared. BOM created and parts rationalised.
    [AdjPower.sch, BoardPower.sch, CAN.sch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]
2019-01-14 tracking updates
    [HILTOP_Motherboard.kicad_pcb, HILTOP_Motherboard.sch, SATA_Bridge.sch]
2019-01-25 90% complete on backplane and IO connectors
    [HILTOP_Motherboard.kicad_pcb, HILTOP_Motherboard.sch]
2019-02-01 nearly all tracked - power and ground planes to do!
    [HILTOP_Motherboard.kicad_pcb, HILTOP_Motherboard_BOM_Draft.xlsx]
2019-02-04 nearly there, drc errors all resolved!
    [HILTOP_Motherboard.sch]
2019-06-28 Rev A complete!
    [HILTOP_Motherboard.csv]
2019-07-03 finished new tracking for RS485 signals and general house keeping
    [AdjPower.sch, BackPlane.sch, BoardPower.sch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]
2019-07-10 Replaced FCC 15way connectors with new footprint
    [AdjPower.sch, BackPlane.sch, BoardPower.sch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]
2020-02-09 Rev B
    [BoardPower.sch, HILTOP_Motherboard.csv, HILTOP_Motherboard.ods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]
2020-04-28 Rev C - pre-release
    [AdjPower.sch, BackPlane.sch, BoardPower.sch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]
2021-02-10 Moved Backplane Connctor 2mm to the left to fix alignment issue on HILTOP 63HP
    [AdjPower.sch, BackPlane.sch, BoardPower.sch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]
2021-02-10 added small fixes for USB Debug chip to allow independant power up from external cable
    [USB_Debug.sch]
2021-02-12 updates to include - license, remove U46, swap crystal Y1
    [HILTOP_Motherboard.sch, USBHub.sch, USB_Debug.sch]
2021-02-17 Added TVS diodes on PSU inputs, update license details
    [HILTOP_Motherboard.sch]
2021-02-17 problem with gerber export!
2021-02-17 changed silkscreen to revD and updated sheet information
    [AdjPower.sch, BackPlane.sch, BoardPower.sch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]
2021-03-05 fixed component pos data for CM and minor updates to BOM to remove depreciated parts
2021-03-15 Tidy up documentation ready for public release
    [AdjPower-2018-09-17-11-31-07.sch, BackPlane-2018-09-17-11-31-07.sch, BoardPower-2018-09-17-11-31-07.sch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]
2021-03-16 Updated some 3D footprint filepaths
